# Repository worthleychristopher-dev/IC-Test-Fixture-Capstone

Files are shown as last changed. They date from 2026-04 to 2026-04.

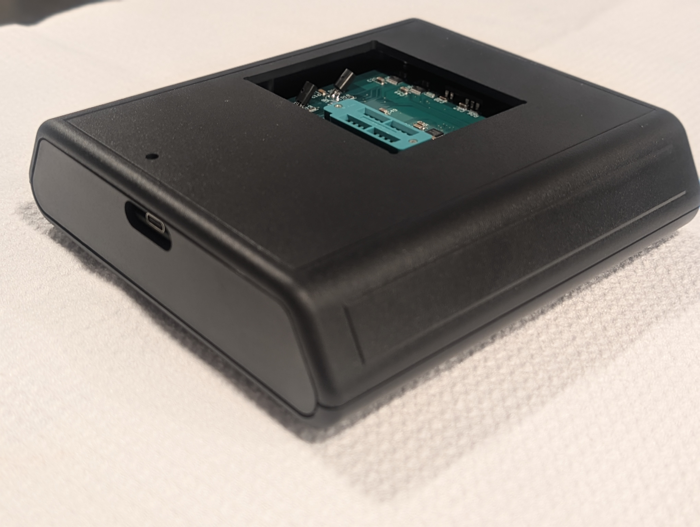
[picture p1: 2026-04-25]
docs/images/hardware_images/chassis_2.jpg

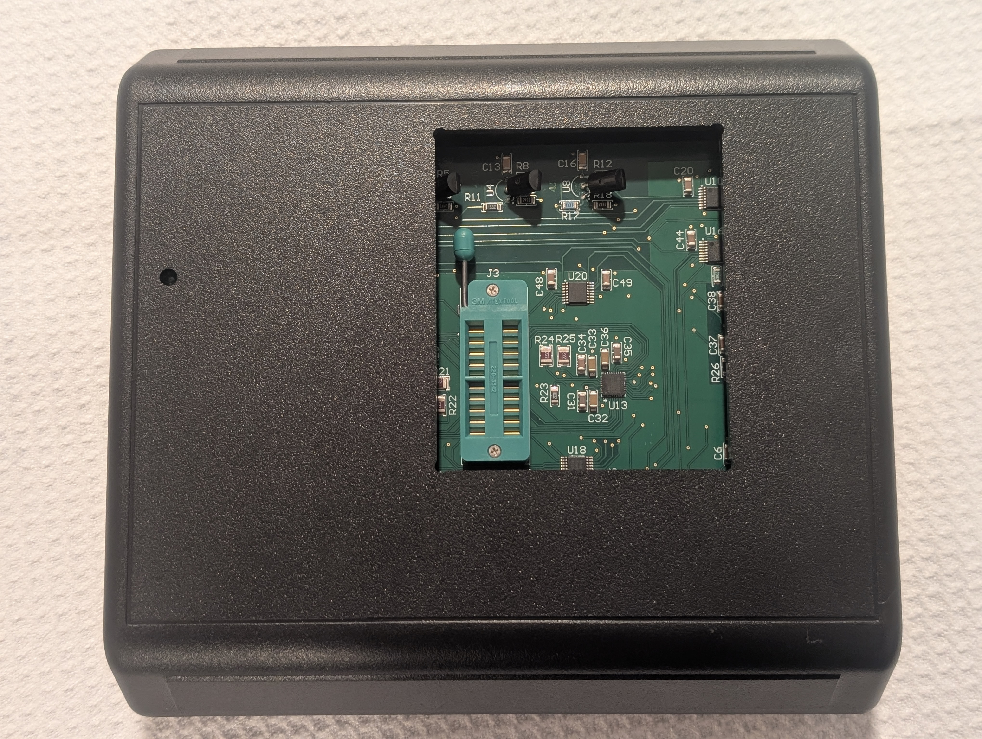
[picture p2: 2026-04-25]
docs/images/hardware_images/chassis_1.jpg

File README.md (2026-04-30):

# Reconfigurable Digital Integrated Circuit Test Fixture

A flexible test setup designed to quickly verify the functionality of various digital integrated circuits, ranging from simple logic gates to timing-dependent shift registers. It supplies standard logic-level voltages and measures output voltages to ensure they are within specification. A PC application enables users to control the system and execute test scripts. Test results are stored and exported as a PDF report describing the outcome of each test.

## Project Background

The core challenge lies in testing and servicing digital integrated circuit (IC) assemblies used in NUWC Division Newport’s ship test equipment. The large number of ICs in these systems makes troubleshooting and verification time-consuming, impacting operational efficiency, system reliability, and maintenance costs.

Since these assemblies are expected to remain functionally reliable for 25–30 years, diagnosing failures without efficient tools increases labor time, risks using faulty components, and threatens overall system readiness.

### Proposed Solution

To address this, our project proposes a **Reconfigurable Digital Integrated Circuit Test Fixture** that enables NUWC technicians to quickly verify IC functionality and assist in debugging failed circuit assemblies.

### System Components

- **Hardware Fixture**  
  Adapts to various IC packages and pinouts, applies logic-level signals, and measures outputs via analog-to-digital converters.

- **Software Interface**  
  Communicates with the hardware over USB, runs user-defined test scripts, and automatically generates detailed PDF reports.

### Key Benefits

- **Improved Maintenance Efficiency**  
  Reduces time spent on board-level diagnostics and repairs.

- **Inventory Verification**  
  Confirms IC functionality before installation.

- **Cost and Labor Savings**  
  Minimizes dependence on expensive test equipment and manual checks.

## Prerequisites

### Hardware

Altium Designer or KiCad (may need to manually fix PCB layers)

SolidWorks

CP2102 USB to UART Driver (https://www.silabs.com/software-and-tools/usb-to-uart-bridge-vcp-drivers)

AN721: CP210x/CP211x Device Customization Guide (https://www.silabs.com/interface/usb-bridges/classic/device.cp2102?tab=softwareandtools)

USB-C 2.0 Cable

### Software

Requires Python >= 3.10

Third Party Libraries used in this project are:

  - PySide6
  - PyYAML
  - ReportLab

See software/pyproject.toml for compatible versions.

### Firmware

STM32CubeIDE

ST-Link debugger/programmer

## Installation

```sh
git clone https://github.com/worthleychristopher-dev/IC-Test-Fixture-Capstone
```

Follow the steps below in order to complete the full system setup.

### 1. PCB Fabrication and Assembly

Fabricate and assemble the PCB before proceeding with any software setup.

- Gerber and ODB++ files are located in: hardware/altium_files/
- Bill of Materials (BOM) is located in: docs/

Send these files to your PCB manufacturer and complete assembly.

---

### 2. Install Required Drivers

Install all required hardware drivers before connecting the device.

- Refer to the **Hardware** section of this README for the full list of required drivers
- Ensure STM32 and any peripheral device drivers are properly installed

---

### 3. Firmware Installation (STM32)

Build and flash the firmware to the STM32 microcontroller.

- Navigate to: firmware/README.md
- Follow the instructions under:
  - Building the Firmware
  - Flashing the Firmware

Verify successful flashing before proceeding.

---

### 4. Software Installation (Python Application)

Build and install the Python application.

- Navigate to: software/README.md
- Follow the instructions under:
  - Installation
  - Usage

## Usage

1. Connect test fixture to PC using USB-C 2.0 cable
2. Open ICTestFixture.exe
3. Go to File -> Open and open a test script
4. Insert the IC into the socket.
5. Run -> Run to execute the test script
6. Save PDF report, refer to User Manual for interpretation

## Test Scripts

The test fixture was tested with select 7400-series ICs manufactured by Texas Instruments. These chips range from simple logic gates, to edge dependent shift-registers. Refer to the table below for exact chips tested. 

Test scripts are written using YAML syntax, refer to docs/YAML Test Script Documentation for expected syntax of the application. All used test scripts and their results are located in test_scripts/ and test_results/ respectively.

| IC | Logic |
| -- | ----- |
| 74(HC/HCT)00 | NAND |
| 74(HC/HCT)02 | NOR |
| 74(HC/HCT)04 | Inverter |
| 74(HC/HCT)08 | AND |
| 74(HC/HCT)32 | OR |
| 74(HC/HCT)73 | J-K FF -edge |
| 74(HC/HCT)74 | D FF +edge |
| 74(HC/HCT)138 | 3:8 Demux |
| 74(HC/HCT)153 | 4:1 Mux |
| 74(HC/HCT)165 | 8-bit shift register |
| 74(HC/HCT)244 | Tri-state buffer |
| 74(HC/HCT)245 | 8-bit transceiver |
| 74(HC/HCT)283 | 4-bit full adder |
| 74(HC/HCT)374 | Tri-state D FF +edge |
| 74(HC/HCT)688 | 8-bit comparator |

All chips were able to pass. For ICs 245, 283, and 688, shorter test scripts were used as running an exhaustive test will take hours to complete. The shorter test scripts for these ICs checked that all inputs and output pins were able to operate with a HIGH or LOW signal. See test_results/ for all generated PDF reports.

74HC74 and 74HCT73 had their 2nd flip-flops fail (right side), but their respective variants were able to pass.Rotating the ICs 180 degrees (reverse test scripts), the 2nd flip-flops were able to pass, but the 1st flip-flop failed. It is theorized the right side of the PCB is signifcantly noisier causing the chips to unexpectedly fail.

## Documentation

All documentation can be found in the directory docs. The directory includes PDF files of user manuals
and technical documentation. Additionally, /docs/editable/ includes a DOCX variant to allow
additions to the documentation as this project is expanded on. README markdown file are included with most parts
of the project to assist in navigation and summarize their purpose.

The User Manual for this system is located in docs/User Manual

## License

The Reconfigurable Integrated Test Fixture project contains multiple components with different licenses:

- **Hardware (Altium, SolidWorks)**: CERN-OHL-P-2.0 (see /hardware/LICENSE)
- **Software (Python)**: MIT License (see /software/LICENSE)
- **Firmware (STM32)**: MIT License (see /firmware/LICENSE)

Refer to each subdirectory for full details regarding license of each component.

## Project Structure

```
IC-Test-Fixture-Capstone/
├── README.md               # project overview, and instructions
├── LICENSE                 # top-level license
├── docs/                   # images, user manual, and technical documentation
├── hardware/               # altium source files and chassis files
├── software/               # Python application
├── firmware/               # firmware for STM32C071RB
├── test_scripts/           # HC/HCT test scripts for select 7400-series ICs
└── test_results/           # generated PDF reports from testing on 7400-series ICs
```

## UML Capstone Team 2025 - 2026

Qingping Diep (EE/CS) - [LinkedIn](https://www.linkedin.com/in/qdiep/)

Chris Worthley (CE) - [LinkedIn](https://www.linkedin.com/in/christopher-worthley-98b83a29a/)

Theodore Skafidas (EE) - [LinkedIn](https://www.linkedin.com/in/theodore-skafidas/)

Will Mensah (EE) - [LinkedIn](https://www.linkedin.com/in/will-s-mensah/)

Zacharie Fluet (EE) - [LinkedIn](https://www.linkedin.com/in/zacharie-fluet-6625728b/)

## Acknowledgements

### Advisors

Zachary Murtishi (NUWC)

Paul Robinette (Dept. of Electrical and Computer Engineering UML) - [LinkedIn](https://www.linkedin.com/in/paul-robinette-24857b/)

### UConn Capstone Team 2024 - 2025

Steven Chen (CSE) - [LinkedIn](https://www.linkedin.com/in/steven848/)

William Dunnett (CSE) - [LinkedIn](https://www.linkedin.com/in/william-dunnett-61431b260/)

Joshua Bardinelli (CSE) - [LinkedIn](https://www.linkedin.com/in/joshua-bardinelli/)

Sarah Millien (CSE) - [LinkedIn](https://www.linkedin.com/in/sarah-millien/)

Brennen Ravenberg (CSE)

Gabriel Zambrano (ECE) - [LinkedIn](https://www.linkedin.com/in/gabrielzambrano1111/)

Quincy Tejada (ECE)

Amir Herzberg (Dept. of Computer Science and Engineering UConn)

This project was sponsored by Naval Undersea Warfare Center Division Newport.

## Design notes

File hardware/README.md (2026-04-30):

# Reconfigurable Digital Integrated Circuit Test Fixture - Hardware

The hardware encompasses circuit simulations, schematics, chassis and any other physical component of the **Reconfigurable Digital Integerated Circuit Test Fixture**. The design emphasizes reconfigurability, measurement accuracy, and system protection, enabling reliable testing of digital ICs across a range of operating conditions.

## Overview

The hardware utilizes a USB-C interface for power and communication. The power and data lines are isolated, reducing the noise of the system and protecting the host PC from potential electrical faults. The test fixture accomodates common logic voltage levels from 1.8V to 5V.

Input signal routing is handled using a pair of analog switch arrays, allowing flexible operation of input voltages to pins of the device under test. For measuring output pins, the output signal path is multiplexed and fed first into a high-impedance (Hi-Z) detection circuit, and then into a high-resolution ADC system.

## Core Components

Control of the circuit is handled by the STM32C071RB microcontroller from STMicroelectronics. Communication with the host PC is achieved through a CP2102 USB-to-UART bridge. To ensure signal integrity and safety, USB data lines are isolated using the ADuM4160, while power isolation is provided by the UCC33420 module.

Logic-level voltage references are generated using TLV431 shunt regulators in combination with high-precision resistors, ensuring stable and accurate voltage levels.

Dynamic analog signal routing is implemented using the ADG2128 switch array and ADG708 multiplexers. Output voltages are measured by the NAU7802 ADC, providing high-resolution data.

## Validation

The hardware was validated through a series of test, ensuring analog components performed with high-precison and stability. The power rails and TLV431 circuits were verified for correctness. Signal routing was tested for all ppossible combinations. The ADC performance was evaluated to confirm accuracy of responses and compatability with 1.8 to 5V signals.

All system components performed within expected specifications.

## Chassis

All files included are of the SolidWorks CAD of the IC test fixture chassis design.

This includes raw pre-fab chassis consisting of a top, front, rear, and bottom chassis, modified chassis with cutouts for the PCB on the top, front, and bottom chassis, and the CAD files for hardware used to fully assemble the IC test fixture, including screws, standoffs, and rubber feet.

Drawings are present showing each chassis parts individually, along with their measurements and cutouts. The Chassis is made of ABS plastic.

The pre-fabricated chassis is a JB-65 Desktop Electronics Enclosure, by Polycase and can be orderd from https://www.polycase.com/jb-65

Physical assembly of the chassis can be done with the chassis screws provided with the chassis by Polycase, 8x #4-40 Pan screws, 4x #4-40 1" hex standoffs, and 4x 0.5" cylindrical bumper rubber feet along with the IC test fixture PCB.

## Spice Simulations

Voltage reference (VREF) circuits consist of a TLV431 shunt regulator component with a $1.24\ V$ reference voltage, a voltage divider resistor circuit to set the VREF voltage, and a current limiting resistor to restrict the amount of current that can flow through the circuit.

For all VREF circuits within the IC test fixture, $V_{in} = 5\ V$, $V_{ref} = 1.24\ V$.

The formula for all the VREF circuits is:

$$V_{out} = V_{ref} \left(1 + \frac{R_1}{R_2}\right)$$

where $R_2 = 2490\ \Omega$ for consistency.

$V_{out}$ is set to $1.8\ V$, $2.5\ V$, $3.3\ V$, $4.0\ V$, or $4.5\ V$ for the VREF circuit, which is used to find each circuit's $R_1$ value, which is then chosen from the closest available 0.1% tolerance value.

The current limiting resistor ($R_3$) is equal to: 
$$R_3 = \frac{\left(V_{in} - V_{out}\right)}{\left(I_{out} + I_{cathode}\right)}$$

### TLV431 Simulation Results

| Target Voltage | Simulated Voltage |
| --- | --- |
| 1.8 V | 1.803 V |
| 2.5 V | 2.509 V |
| 3.3 V | 3.314 V |
| 4.0 V | 4.001 V |
| 4.5 V | 4.506 V |

5V is not present as the USB interface outputs at max 5V. Instead, the 5V is provided by the isolated 5V rail from UCC33420.

## Documentation

Refer to Hardware Documentation in docs/. The documentation details the system architecture, circuit design, component selection, and PCB implementation used to support flexible, multi-voltage logic testing.

The hardware documentation includes:

| Section | Description |
| --- | --- |
| System Overview | High-level description of functionality and purpose |
| System Architecture | Block-level breakdown of subsystems |
| Design Decisions | Justification of key engineering choices |
| Signal Flow | End-to-end operation from input to measurement |
| Circuit Descriptions | Detailed explanation of each schematic block |
| PCB Layout | Board design, routing, and layer stack considerations |
| Electrical Specifications | Voltage ranges, thresholds, and performance |
| Interfaces | USB, UART, I²C, and ZIF socket definitions |
| Testing & Validation | Verification of system functionality |
| Safety & Protection | ESD, isolation, and overcurrent protection |

Refer to Reconfigurable Test Fixture BOM in docs/. The file includes the name of the part, part number, manufacturer number, designator, and quantity.

Errors were identified in the PCB layout, refer to docs/eco for all Engineering Change Orders implemented.

## License

The hardware portion of the **Reconfigurable Digital Integrated Circuit Test Fixture** is under a CERN-OHL-P-2.0 license.

## Package Structure

```
hardware/
├── README.md               # project overview, and instructions
├── LICENSE                 # license for hardware source files
├── altium_files/
│   ├── Source/  
│   │   ├── Schematics/     # altium schematics
│   │   └── PCB/            # altium PCB
│   ├── Outputs/            # generated altium output files
│   ├── Draftsman/          # assembly and fabrication drawings
│   └── Releases/           # gerber file used for fabrication
├── chassis/                # SolidWorks design files
└── vref__circuits/         # LTSpice simulation for TLV431 shunt regulator
```

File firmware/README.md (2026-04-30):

# Reconfigurable Integrated Circuit Test Fixture – Firmware

This firmware drives the **Reconfigurable Digital Integrated Circuit Test Fixture**, enabling configurable testing of common digital ICs through a command-based interface.

## Overview

The system is designed to operate in two primary modes:
- **GUI-controlled operation** (normal use case)
- **Standalone command-driven operation** (development, debugging, automation)

The firmware runs on an STM32 microcontroller and interfaces with:
- Analog switch matrices (2x ADG2128)
- Analog multiplexers (4x ADG708, 1x ADG709)
- Voltage rail selection circuitry
- GPIO-based digital I/O
- ADC (NAU7802) for measurement
- UART interface for command communication

## Firmware Architecture

### Core Responsibilities
- Parse and execute incoming commands (SCPI-style)
- Configure routing through analog switch arrays
- Apply voltage rails to DUT pins
- Drive digital inputs and read outputs
- Execute test sequences
- Return structured responses over UART

### Key Modules
- `main.c`  
  Handles system initialization (HAL, peripherals), UART communication, and command dispatch
  Parses incoming ASCII commands and routes them to execution handlers

- `test_utils.c`  
  Contains core test execution logic and validation
  Contains functions for switch array routing

- `nau7802.c`
  Handles ADC reads, calibration, and measurement routines

- `mux_utils.c`  
  Controls analog switch matrices (ADG2128) and pin routing

- `bist.c`   
  Code for executing a built-in self test for the fixture

- `fault_handling.c`
  Functions and subroutines for hardware fault handling

- `adg2128_router.c` *functions not used*
  Contains legacy functions for routing the switch arrays
  Functions improved upon and implemented in test_utils.c. 
  Header file includes variable definitions that ARE used

- `firmware_crc.c`
  Contains functions for running the firmware checksum

## Command Interface

The firmware uses a text-based command protocol.

### Format
```
CMD:arg1,arg2,arg3
```

### Example
```
PRM:20,7,5
VIN:0.33,3.84
INS:1,2,3
OUT:4,5
VIP:0b0101,0b1010
TEST
```

### Full Command Reference
See:
```
/docs/STM32 Command Programming Guide.txt
```

This file contains:
- All supported commands
- Argument formats
- Command use cases

## Development Setup

### Requirements
- STM32CubeIDE
- ST-Link debugger/programmer
- USB connection to STM32 board
- (Optional) Python (for executor script)

## Building the Firmware

1. Open STM32CubeIDE
2. Go to:
   ```
   File → Open Projects from File System
   ```
3. Import the firmware project folder
4. Build the project:
   ```
   Project → Build Project
   ```

## Flashing the Firmware (ST-Link)

1. Connect ST-Link to the board
2. Power the board via USB
3. In STM32CubeIDE:
   ```
   Run → Debug (or Run)
   ```
4. The firmware will compile (if needed) and flash automatically

## UART Communication

Typical UART settings:
- Baud Rate: 115200
- Data Bits: 8
- Stop Bits: 1
- Parity: None

## Using the System with the GUI

### Steps
1. Plug in the fixture via USB
2. Ensure firmware is running on the STM32
3. Open the GUI application
4. The GUI will automatically connect 
5. System now ready to run test scripts from the GUI application

### Notes
- No manual setup is required if firmware is running
- GUI handles all command formatting and communication

## Standalone Usage (Without GUI)

### Option 1: Serial Terminal

You can manually send commands using a serial terminal.

#### Recommended Tools
- STM32CubeIDE Serial Terminal
- Terminal or Windows Powershell

#### Steps
1. Open a serial terminal
2. Set directory to the one that includes stm32_terminal.py
   ex. 'cd C:\IC-Test-Fixture-Capstone\firmware\utils'
3. Run the python file, 'python stm32_terminal.py'
4. Send commands manually:
   ```
   PRM:20,7,5
   TEST
   ```

#### Example Output
```
OK PRM
OK TEST
RESULT: PASS
```

---

### Option 2: Script Execution (executor.py)

The `executor.py` script allows automated execution of command sequences.

#### Usage
```
python executor.py 
```

#### Example `script.txt`
```
PRM:20,7,5
VIN:0.33,3.84
INS:1,2,3
OUT:4
VIP:0b0101
TEST
```

#### Features
- Sequential command execution
- Response logging
- Useful for automated testing and debugging

## Typical Workflow

### Development Workflow
1. Modify firmware source code
2. Build in STM32CubeIDE
3. Flash using ST-Link
4. Test using terminal or executor.py

### Normal Operation
1. Power on fixture
2. Open GUI
3. Run test scripts

## Error Handling

Common responses:
- `OK <CMD>` → Command executed successfully
- `ERR <reason>` → Command failed

### Examples
```
ERR no_colon
ERR invalid_args
```

## Troubleshooting

### No UART Output
- Check COM port selection
- Verify baud rate
- Ensure firmware is running

### Flashing Issues
- Verify ST-Link connection
- Confirm correct target device in CubeIDE
- Power cycle the board

### Command Errors
- Ensure correct format (`CMD:args`)
- Refer to Command Programming Guide

## Future Improvements
- Expanded command set
- Improved error reporting
- Multi-fixture GUI support
- Enhanced logging and diagnostics

## Notes
- Designed for production-like testing environments
- Emphasizes modularity and scalability
- Command-based interface enables easy automation

## License

The firmware portion of the **Reconfigurable Digital Integrated Circuit Test Fixture** is under a MIT license. The firmware contains third-party software provided by STMicroelectronic and are subject to their own licenses and agreement policies. See firmware/LICENSE, and firmware/THIRD_PARTY_NOTICES for full details.

## Package Structure

firmware/
├── README.md               # project overview, and instructions
├── LICENSE                 # license for firmware source files
├── THIRD PARTY NOTICES     # license for third-party libraries used
├── STM32_main/
│   ├── Core/  
│   │   ├── Src/            # C source files
│   │   └── Inc/            # C header files
│   ├── Drivers/            # STMicroelectronic drivers
│   ├── .cproject           # compiler settings
│   ├── .mxproject          # CubeMX project wrapper
│   ├── .project            # STM32CubdeIDE project file
│   └── STM32_main.ioc      # STM32 configurations
└── utils/                  # utility Python scripts to run firmware
```

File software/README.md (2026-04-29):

# Reconfigurable Digital Integrated Circuit Test Fixture - Software

A standalone GUI application for controlling the **Reconfigurable Digital Integrated Circuit Test Fixture**. 
Users can write or upload YAML-based test scripts to execute tests, with results exported as PDF files.

Requires Python >= 3.10

Recommended Python >= 3.14.3 (latest as of April 2026)

## Installation

Create virtual Python environment
```sh
cd software/

python -m venv .venv

# linux/mac
source .venv/bin/activate

# windows
.venv\scripts\Activate.ps1
```

To install project dependencies
```sh
# run in same directory as pyproject.toml

# only required dependencies
pip install -e .

# install with additional optional dev dependencies
pip install -e .[dev]
```

## Usage

### Developing in IDE
```sh
# run directly from src
python src/ic_test_fixture/main.py

# or if installed in editable mode
python -m ic_test_fixture.main
```

### Compiling Executable

To compile an executable
```sh
# linux/mac
bash ./scripts/build.sh

# winodws (PowerShell)
powershell -ExecutionPolicy Bypass -File .\scripts\build.ps1
```

## GUI Usage

### From Existing Test Script
    1. Go to **File -> Open File** (Ctrl+O)
    2. Verify test script is correct
    3. Press **Run -> Run** (F5)
    4. Save results to desired location as PDF file
    
### Create a New Test Script

1. Go to **File → New File** (Ctrl+N)
2. Choose one of the following:
   - **Text Editor** (manual script creation)
   - **Test Script Wizard** (guided setup)

---

Refer to User Guide in docs/ for full usage

#### Option A: Text Editor
3. Write your test script manually  
4. Save the test script as a YAML file  

---

#### Option B: Test Script Wizard
3. Select the desired optional sections  
4. Use the dropdown menus to configure parameters  
5. Save the test script as a YAML file  

## Running Tests

```sh
# to run all unit tests
pytest tests/

# :: operator can be used to run specific tests
pytest tests/test_parser.py::TestParserHelpers
```

## Troubleshooting

### Unable to Communicate with STM32

Reset the circuit by unplugging and replugging the USB-C cable. Firmware must have the response "OK PING".

### Software Checksum failed

Verify the ICTestFixture.exe file has not been tampered with. Last 32 bytes should match the SHA-256 of the executable excluding the last 32 bytes of data.

### Checksum failed

Verify CP2102 driver has been installed and serial number has been reprogrammed. See the repository's main README.md for the associated download links.

Verify the test fixture is connected via USB-C 2.0.

Ensure firmware has not been tampered with. If developing, change EXPECTED_CHECKSUM in device/serial_manager.py::CheckSum to the the new expected checksum. 

## Documentation

See docs/ for all documentation

Python Technical Documentation - explaination of source code, architecture, and data structures

YAML Test Script Documentation - expected syntax of test scripts

## License

The software portion of the **Reconfigurable Digital Integrated Circuit Test Fixture** is under a MIT license. The software contains third-party packages that are subject to their own licenses provided by their authors. See software/LICENSE, and software/THIRD_PARTY_NOTICES for full details.

## Package Structure

```
software/
├── README.md               # project overview, and instructions
├── LICENSE                 # license for Python source code
├── THIRD PARTY NOTICES     # licenses for Python packages used
├── pyproject.toml          # package metadata and dependencies
├── scripts/
│   ├── append_checksum.py  # appends checksum to executable
│   ├── build.ps1           # Windows Powershell build script
│   └── build.sh            # Mac/Linux build script
├── src/
│   └── ic_test_fixture/
│       ├── device/         # device-related modules
│       ├── file_io/        # file parsing, and exporting data
│       ├── gui/            # graphical user interface code
│       ├── utils/          # misc. code / helper tools
│       ├── __init__.py
│       └── main.py         # application entry point
└── tests/
    ├── unittest_yaml/      # YAML-based test scripts for unit tests
    ├── test_parser.py      # tests for parser module
    └── test_test_vector.py # tests for test_vector module
```

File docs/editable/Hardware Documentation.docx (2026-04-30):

Reconfigurable Test Fixture for Digital Integrated Circuits

Hardware Design Documentation

ABSTRACT

This report presents the design and implementation of a reconfigurable test fixture for evaluating 7400-series digital integrated circuits (ICs). The system enables dynamic signal routing, multi-voltage logic testing, and automated data acquisition through a USB-connected microcontroller platform. Key features include electrical isolation, programmable voltage references, multiplexed signal routing, and high-resolution analog-to-digital conversion. The design ensures accurate, flexible, and safe testing of digital ICs across a range of operating conditions.

I. INTRODUCTION

The increasing diversity of digital logic devices necessitates flexible testing platforms capable of supporting multiple voltage levels and configurations. Traditional fixed test setups lack adaptability and require significant manual intervention. This work presents a reconfigurable hardware system that enables testing of a varied number of digital ICs.

II. SYSTEM OVERVIEW:

The reconfigurable test fixture for digital integrated circuits is designed to evaluate and characterize 7400-series logic ICs across a range of operating voltage levels. The system provides a flexible platform that allows users to dynamically configure input signals, apply selectable voltage levels, and measure output responses through a software-controlled interface.

The fixture connects to a host computer via USB, enabling both power delivery and communication. An onboard microcontroller coordinates signal routing, voltage selection, and data acquisition while interfacing with external components such as analog switch arrays, multiplexers, and an analog-to-digital converter (ADC). The system supports multiple logic voltage levels (1.8V to 5V), allowing compatibility with a wide variety of digital devices.

By integrating electrical isolation, programmable signal routing, and high-impedance measurement capability, the design ensures safe operation, minimizes noise interference, and provides accurate testing results. This makes the system suitable for both educational use and practical validation of digital IC functionality.

III. SYSTEM ARCHITECTURE:

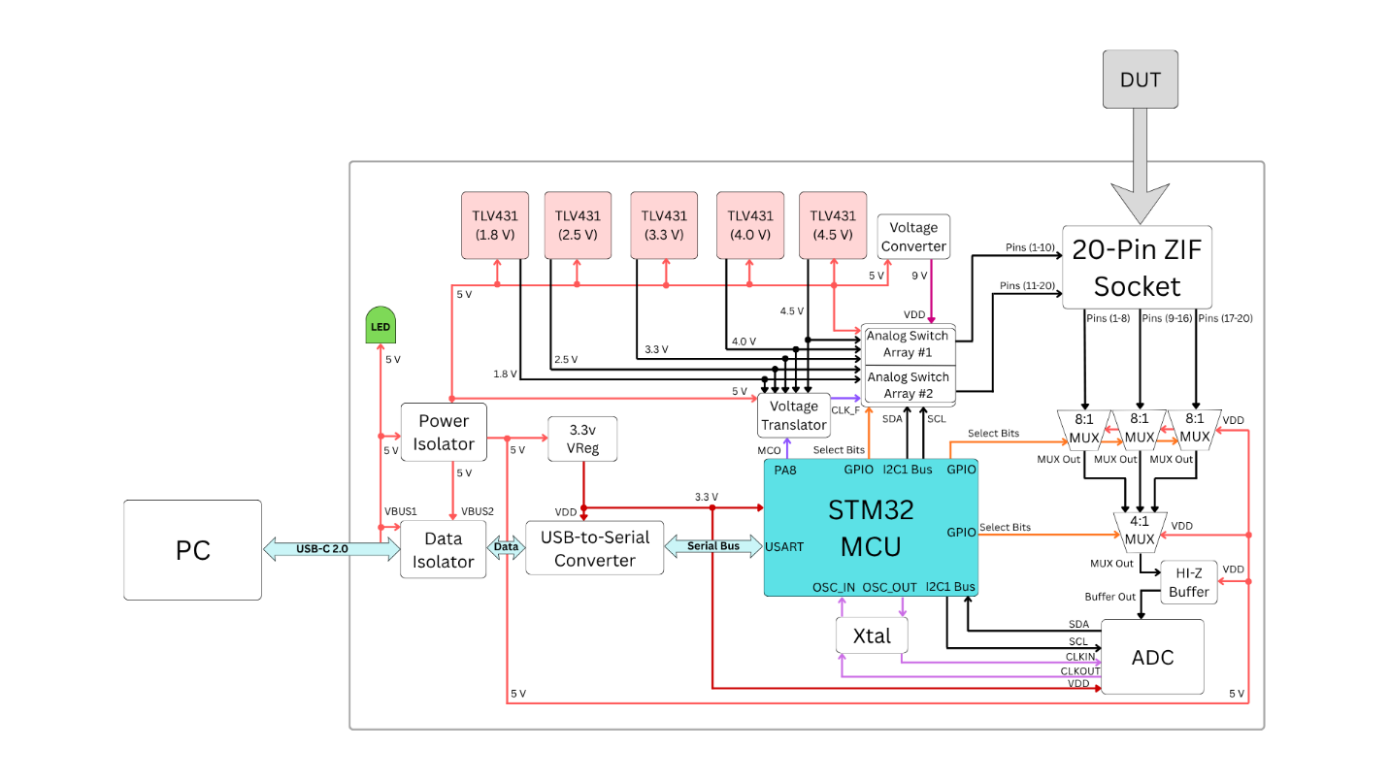
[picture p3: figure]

Fig. 1. Block Diagram of the Reconfigurable Test Fixture

In Figure 1 above, the IC test fixture connects to a user-end PC through a USB-C 2.0 connection, which provides 5 V and data for both power and communication. The 5 V from USB connects to a power indicator LED and, along with the data lines, is routed to individual isolators for protection. The isolated data then connects to a USB-to-Serial converter before interfacing with the STM32 microcontroller. The isolated 5 V rail powers multiple components, including a 3.3 V voltage regulator, buffer op-amp, 8:1 and 4:1 multiplexers, a voltage translator, and a voltage converter, as well as multiple voltage reference circuits (1.8 V, 2.5 V, 3.3 V, 4.0 V, and 4.5 V) made up of TLV431. TLV431 are shunt regulators and used to maintain a stable voltage signal by using voltage dividing resistors. The 3.3 V regulator supplies power to the USB-to-Serial converter, STM32 microcontroller, and the analog-to-digital converter. The voltage converter generates 9 V to power the analog switch arrays, which provide routing to all 20 pins of the zero-insertion force (ZIF) socket to accommodate the input pin requirements of a valid 7400 series IC for testing. The 20-pin ZIF socket provides connection access for these ICs, supporting a maximum of 20 pins. A cascade of three 8:1 multiplexers provides routing to all 20 pins of the ZIF socket to accommodate output pins of the IC under test and funnels them into a 4:1 multiplexer. The 4:1 multiplexer sends the selected signal through a buffer op-amp to allow for high-impedance (Hi-Z) testing, after which the buffer op-amp drives the signal into the analog-to-digital converter for conversion. The analog-to-digital converter then sends the digitized signal to the STM32 microcontroller for analysis. The STM32 processes the received data and transmits the results back to the user-end PC. Additionally, the STM32 controls multiple components through select bits, including the analog switch arrays and both the 8:1 and 4:1 multiplexers, to determine signal pathing during testing. A voltage translator is used to match voltage levels for clock rise and fall signals required by certain ICs, and an external crystal (Xtal) provides a higher frequency (24 MHz) and improved accuracy for both the STM32 and the analog-to-digital converter.

IV. REQUIREMENTS AND SPECIFICATIONS

A. Functional Requirements

- Support up to 20-pin 7400-series ICs
- Provide configurable voltage levels (1.8V–5V)
- Enable dynamic signal routing
- Measure and report logic states

B. Electrical Specifications

- Input Voltage: 5V (USB)
- ADC Resolution: 24-bit
- Logic Levels: 1.8V–5V

V. DESIGN DECISIONS

The purpose of this test fixture is to provide a flexible and safe platform capable of testing a wide range of logic voltage levels for 7400-series integrated circuits. Several key design decisions were made to achieve this functionality:

USB-Based Power and Communication

USB-C was selected as the primary interface due to its widespread availability and ability to provide both power and data through a single connection. Operating in USB 2.0 mode simplifies implementation while still meeting system bandwidth requirements.

Electrical Isolation

Isolation was implemented using the ADuM4160 and UCC33420 to protect the host computer and eliminate ground loops. This improves measurement accuracy and prevents noise from propagating between the host and the test circuitry.

Microcontroller Selection (STM32)

The STM32 microcontroller was chosen for its balance of processing capability, peripheral support, and ease of integration. It provides sufficient GPIO, I²C, and UART interfaces to control multiplexers, switch arrays, and communication modules while maintaining low power consumption.

External ADC Usage

An external ADC (NAU7802) was used instead of the internal STM32 ADC to achieve higher resolution and improved measurement accuracy. This is particularly important when detecting small voltage differences and high-impedance states.

Multiplexing and Switching Architecture

Instead of dedicating a measurement channel to each pin, multiplexers (8:1 and 4:1) and an analog switch array (ADG2128) were used to reduce hardware complexity while maintaining flexibility. This allows a single ADC channel to measure multiple signals efficiently.

Multi-Voltage Support

Multiple voltage references (1.8V to 5V) were implemented using TLV431 shunt regulators. This enables the system to test ICs operating at different logic levels and ensures stable and accurate voltage generation.

High-Impedance Measurement Capability

A buffer op-amp stage was included before the ADC to allow high-impedance (Hi-Z) measurements. This prevents loading effects and ensures accurate detection of open or disconnected signals.

Dedicated Power Domains

Separate isolated and non-isolated domains were used to improve signal integrity and system reliability. Sensitive analog and measurement circuits operate in the isolated domain to minimize noise.

VI. SIGNAL FLOW DESCRIPTION

The system operates through a coordinated signal flow controlled by the STM32 microcontroller:

1. A command is sent from the user’s PC to the system via the USB interface.
2. The USB-to-UART bridge (CP2102) converts the incoming USB data into serial communication for the STM32.
3. The STM32 processes the command and configures the analog switch array and multiplexers to establish the desired signal path.
4. Selected voltage levels are applied to the input pins of the device under test (DUT) through the switch matrix.
5. Output signals from the DUT are routed through a cascade of multiplexers (8:1 followed by 4:1).
6. The selected signal passes through a high-impedance buffer stage to prevent loading.
7. The buffered signal is sent to the ADC, where it is converted into digital data.
8. The STM32 reads the ADC data via I²C, processes the results, and determines the logic state or measurement outcome.
9. The processed data is transmitted back to the PC for display and analysis.

This structured signal flow enables flexible, automated, and accurate testing of digital ICs.

VII. KEY COMPONENT SUMMARY TABLE

Component | Part Number | Function
Microcontroller | STM32 | Controls system operation and data processing
USB-to-UART Bridge | CP2102 | Enables communication between PC and MCU
USB Isolator | ADuM4160 | Provides data isolation between host and system
Power Isolator | UCC33420 | Generates isolated 5V supply
ADC | NAU7802 | Converts analog signals to digital data
Analog Switch Array | ADG2128 | Routes signals dynamically
Multiplexer (8:1) | ADG708 | Selects one of multiple input signals
Multiplexer (4:1) | ADG708 | Final signal selection stage
Voltage Reference | TLV431 | Generates stable reference voltages
Voltage Regulator | LDO (3.3V) | Supplies regulated power to digital components

VIII. SCHEMATICS

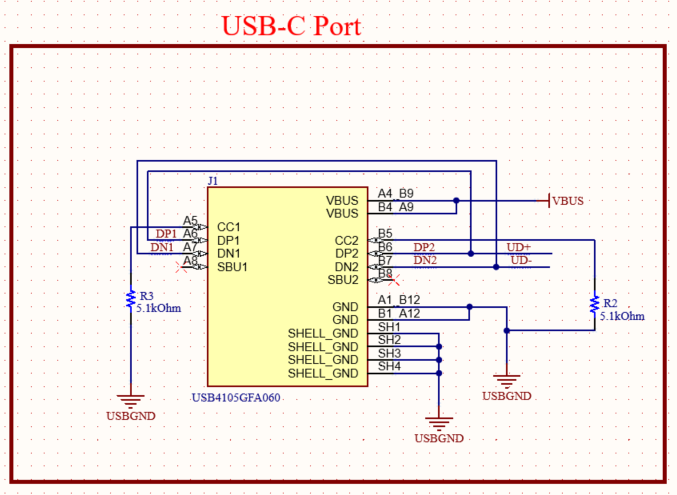
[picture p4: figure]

Figure 2. USB-C Port Schematic.

A USB-C connector is configured to operate in USB 2.0 mode, providing both power and data communication between the user and the board. The differential data lines (D+ and D−) are formed by tying DP1 with DP2 and DN1 with DN2, ensuring proper operation regardless of cable orientation.

The CC1 and CC2 pins are connected to 5.1 kΩ pull-down resistors, indicating that the device operates as a USB sink. This configuration allows the host to detect the connection and supply 5V (VBUS) power while enabling data communication.

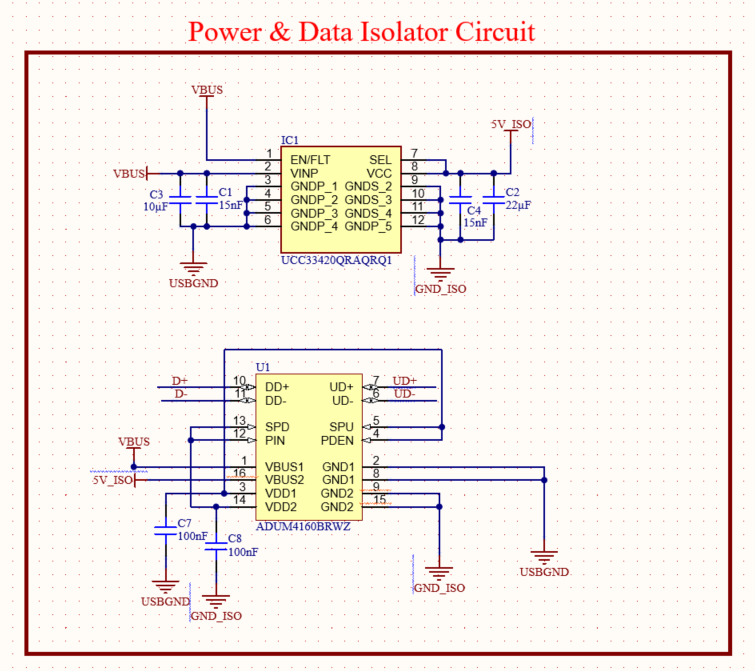
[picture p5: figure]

Figure 3. Power and Data Isolator Circuit

This circuit implements full USB isolation by separating both power and data between the host (computer) and the system. The top portion of the schematic uses the UCC33420 to convert the incoming USB VBUS (5V) into an isolated 5V supply (5V_ISO), effectively separating the host ground (USBGND) from the system ground (GND_ISO). This ensures that the board operates on a clean, isolated power domain, reducing noise and preventing ground loops. The bottom portion of the circuit uses the ADuM4160 USB isolator to transfer the differential data signals (D+ and D−) across the isolation barrier. On the host side, the data lines are received and magnetically coupled across the isolator, then reconstructed on the device side as DATA_P and DATA_N. Together, these components create two independent domains, host and system, allowing safe and reliable communication while protecting sensitive circuitry and improving measurement accuracy by minimizing noise interference.

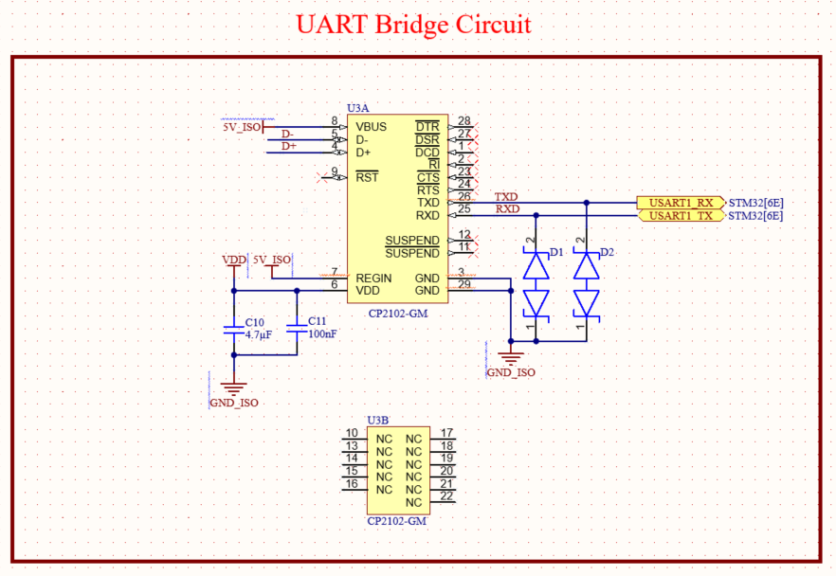
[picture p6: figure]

Figure 4. USB-to UART Bridge

This circuit implements a USB-to-UART communication bridge using the CP2102, enabling communication between the host computer and the microcontroller. The differential USB data lines (D+ and D−), labeled as DATA_P and DATA_N, enter from the isolated USB domain (5V_ISO and GND_ISO) and connect to the CP2102, which converts USB signals into UART signals. The device is powered using the isolated 5V supply, with local decoupling capacitors (4.7 µF and 100 nF) ensuring stable operation. On the output side, the CP2102 provides TXD and RXD signals, which are routed to the microcontroller’s UART interface (USART1 TX/RX). ESD protection diodes are placed on the UART lines to protect against voltage spikes and improve system robustness. Overall, this circuit enables reliable, isolated serial communication between the USB host and the onboard microcontroller while maintaining signal integrity and protection.

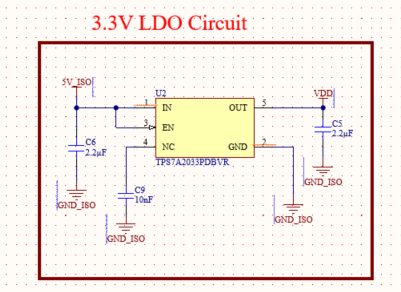
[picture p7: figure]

Figure 5. 3.3V LDO Circuit.

This circuit implements a 3.3V low-dropout (LDO) regulator to generate a stable supply voltage for low-power components on the board. The regulator takes the isolated 5V supply (5V_ISO) as its input and steps it down to a regulated 3.3V output (VDD). Input and output capacitors (2.2 µF) are used to stabilize the voltage and reduce noise, while an additional 10 nF capacitor on the enable pin helps filter any unwanted transients. The entire circuit is referenced to the isolated ground (GND_ISO), maintaining consistency with the system’s isolated power domain. This ensures a clean and reliable 3.3V rail for sensitive digital and analog components, contributing to overall system stability and performance.

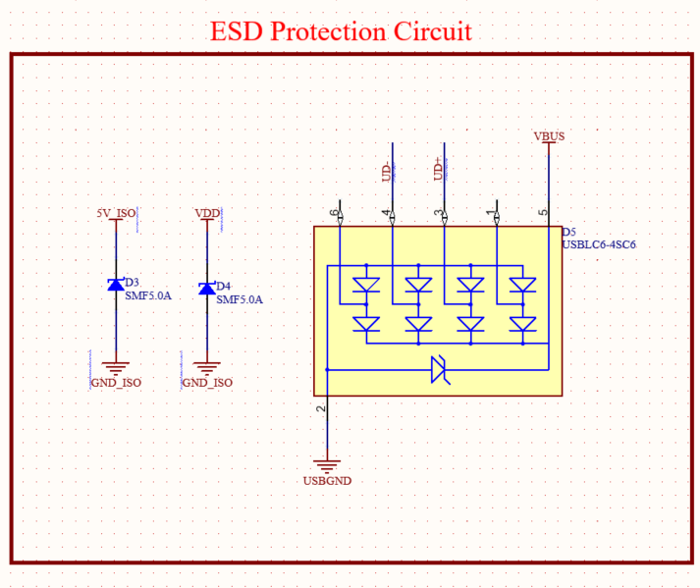
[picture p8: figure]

Figure 6. ESD Protection Circuit

This circuit provides electrostatic discharge (ESD) protection for the USB interface and critical signal lines. Transient voltage suppression (TVS) diodes are placed on key lines, including VBUS, TX, and RX, to protect against voltage spikes caused by electrostatic events or external disturbances. The USBLC6-4SC6 device is used to protect the USB data lines (D+ and D−) by clamping high-voltage transients safely to ground (USBGND), ensuring the integrity of the communication interface. Additional TVS diodes (SMF5.0A) are used on power and signal lines referenced to the isolated ground (GND_ISO), providing localized protection within the system. This design helps prevent damage to sensitive components, improves system robustness, and ensures reliable operation in environments where ESD events may occur.

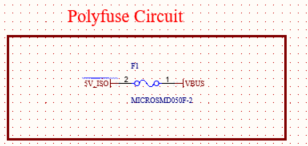
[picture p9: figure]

Figure 7. Polyfuse Circuit

This circuit implements overcurrent protection using a resettable polyfuse (PTC fuse) on the 5V supply line. The polyfuse is placed between the isolated 5V supply (5V_ISO) and the downstream VBUS rail, allowing normal current flow during standard operation. If excessive current is drawn due to a fault or short circuit, the polyfuse increases its resistance significantly, limiting the current and protecting the rest of the system. Once the fault is removed, the polyfuse automatically resets to its low-resistance state, restoring normal operation without requiring replacement. This provides a simple and reliable method of protecting the power path from damage.

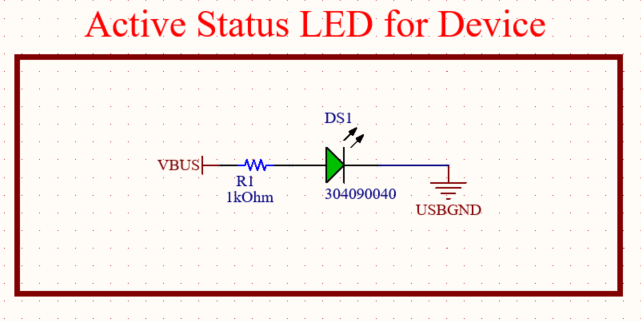
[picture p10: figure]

Figure 8. Active Status LED for Device

This circuit implements a simple status indicator using an LED to show when the device is powered. The LED is connected to the VBUS line through a current-limiting resistor, allowing it to illuminate whenever USB power is present. The resistor ensures that the LED operates within a safe current range, preventing damage while providing visible indication. The LED is referenced to USB ground (USBGND), making it active as soon as the USB cable is connected. This provides a quick and intuitive visual confirmation that the device is receiving power.

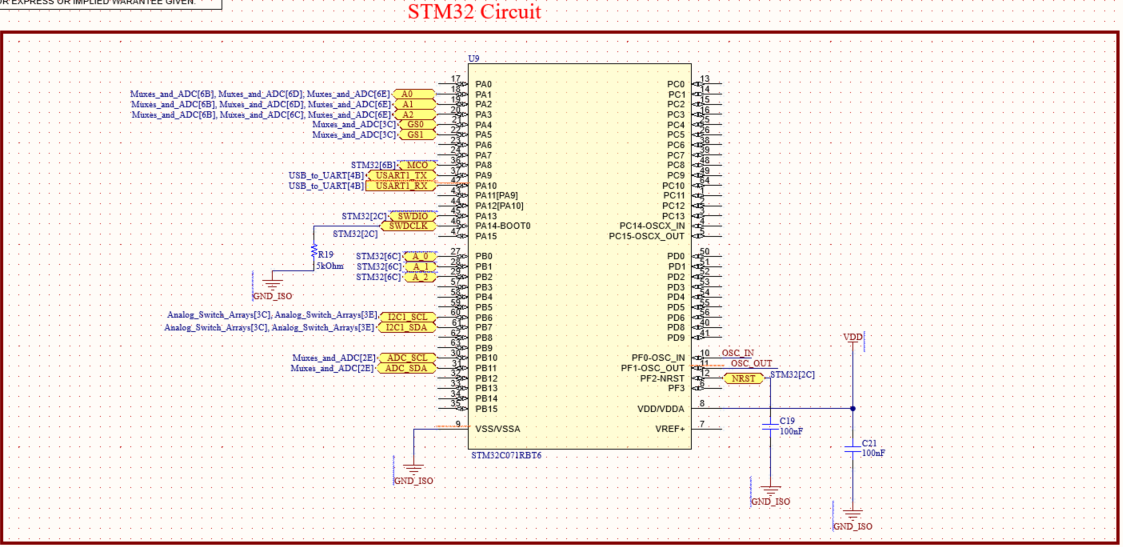
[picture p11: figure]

Figure 9. STM32 Circuit

This circuit implements the STM32 microcontroller as the central control unit of the system, responsible for coordinating data acquisition, processing, and communication. The microcontroller interfaces with multiple subsystems, including the USB-to-UART bridge for communication, the ADC for measurement data, and external circuitry through GPIO pins. Power is supplied through the 3.3V rail (VDD), with local decoupling capacitors placed near the supply pins to ensure stable operation and reduce noise. The reset (NRST) and oscillator (OSC_IN/OSC_OUT) pins are configured to support reliable startup and clock generation. Additionally, communication interfaces such as I²C (SCL/SDA) and UART (TX/RX) are connected to enable interaction with peripheral devices and sensors. Overall, the STM32 serves as the core processing element, managing system logic, data flow, and control functionality.

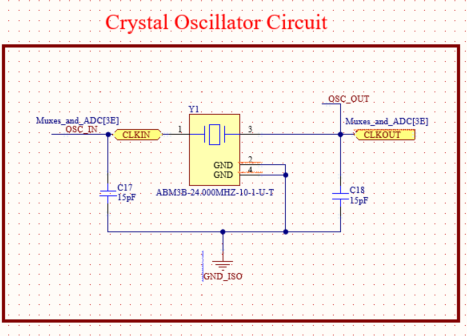
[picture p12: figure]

Figure 10. Crystal Oscillator Circuit

This circuit implements a crystal oscillator to provide a stable clock signal for the system. The 24 MHz crystal (ABM3B series) is connected between the microcontroller’s oscillator input (OSC_IN) and output (OSC_OUT) pins, forming a feedback loop required for oscillation. Two load capacitors (15 pF each) are connected from each side of the crystal to ground (GND_ISO) to stabilize the oscillation frequency and ensure reliable startup. The crystal generates a precise and stable clock signal (CLKIN/CLKOUT), which is essential for accurate timing, communication, and overall system operation.

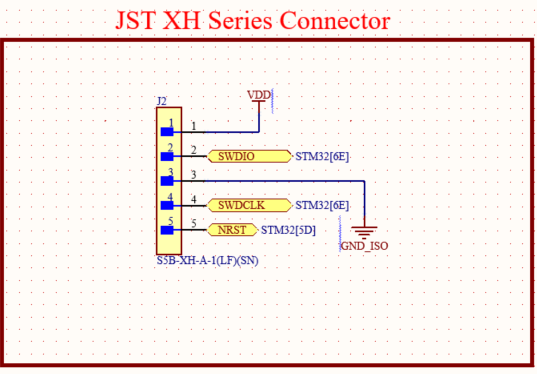
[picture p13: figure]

Figure 11. JST XH Series Connector

This circuit implements a JST XH series connector to provide an external programming and debugging interface for the STM32 microcontroller. The connector exposes key signals, including SWDIO and SWCLK for Serial Wire Debug (SWD) communication, as well as NRST for resetting the microcontroller. A 3.3V supply (VDD) and ground (GND_ISO) are also included to power the debugger and establish a common reference. This interface allows for firmware programming, real-time debugging, and system testing, making it an essential tool for development and troubleshooting.

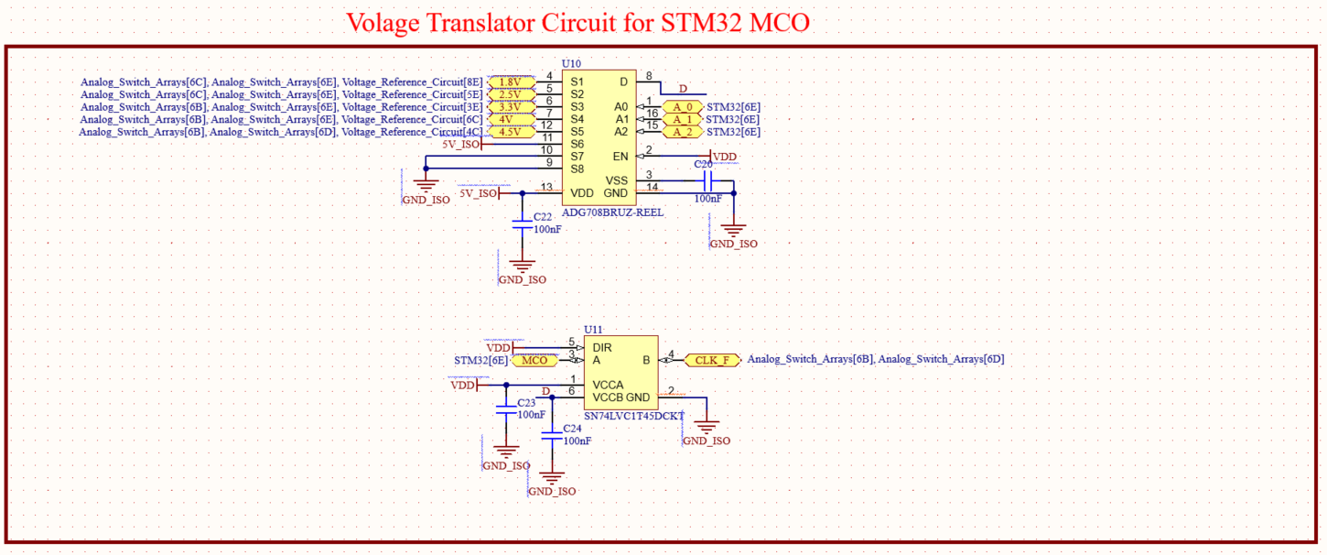
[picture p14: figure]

Figure 12. Voltage Translator Circuit for STM32 MCO

This circuit implements voltage translation and selection to ensure compatibility between the STM32 and devices under test (DUT) operating at different logic levels. An 8:1 multiplexer is used to select from multiple reference voltages (e.g., 1.8V, 2.5V, 3.3V, 4V, 4.5V, and 5V) generated by the voltage reference circuit, allowing the system to dynamically choose the appropriate logic level for the DUT. In addition, a 74LVC series level translator is used to shift the STM32’s MCO (microcontroller clock output) signal from its native 3.3V domain to the selected voltage level, ensuring proper signal compatibility. Together, this circuit enables flexible, multi-voltage operation and reliable interfacing with a wide range of logic devices.

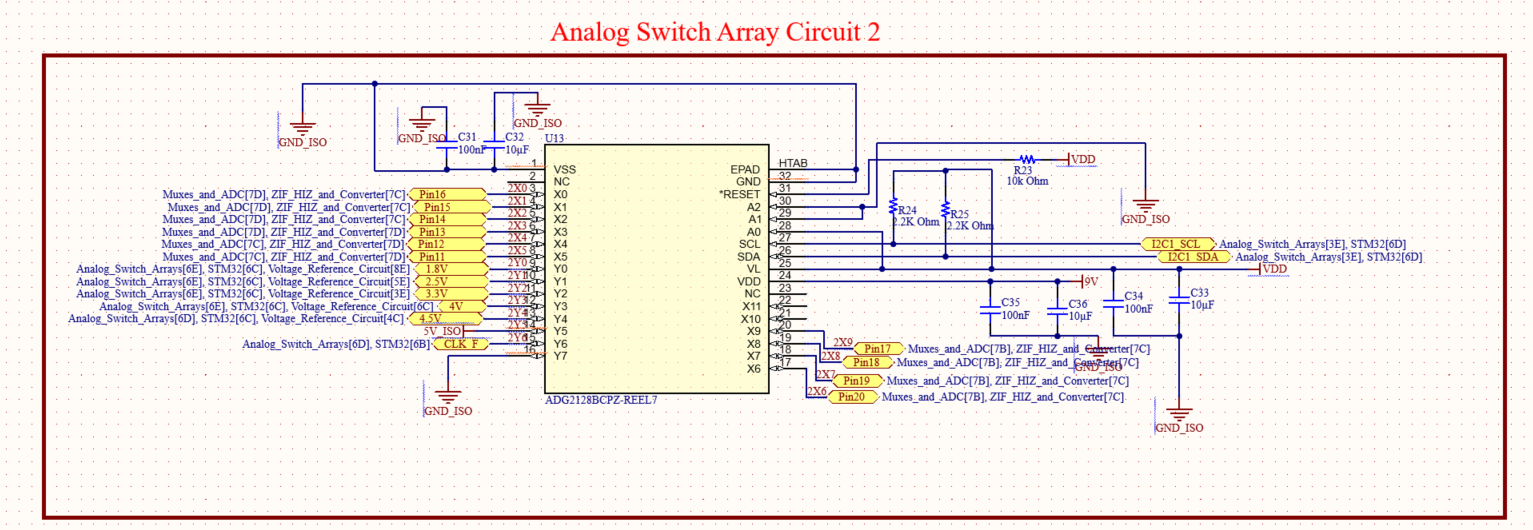
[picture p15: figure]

Figure 13. Analog Switch Array Circuit

This circuit implements an analog switch array that enables flexible routing of multiple voltage levels and signals throughout the system. The ADG2128 switch matrix allows different input voltages, including 1.8V, 2.5V, 3.3V, 4V, 4.5V, and 5V, as well as clock and measurement signals, to be selectively connected to various outputs under digital control. The device is controlled via an I²C interface (SCL and SDA) from the STM32, allowing dynamic configuration of signal paths in real time. Pull-up resistors are used on the I²C lines to ensure proper communication, and decoupling capacitors are included to stabilize the power supply. This design enables reconfigurable signal routing, allowing the system to adapt to different testing conditions and voltage requirements efficiently.

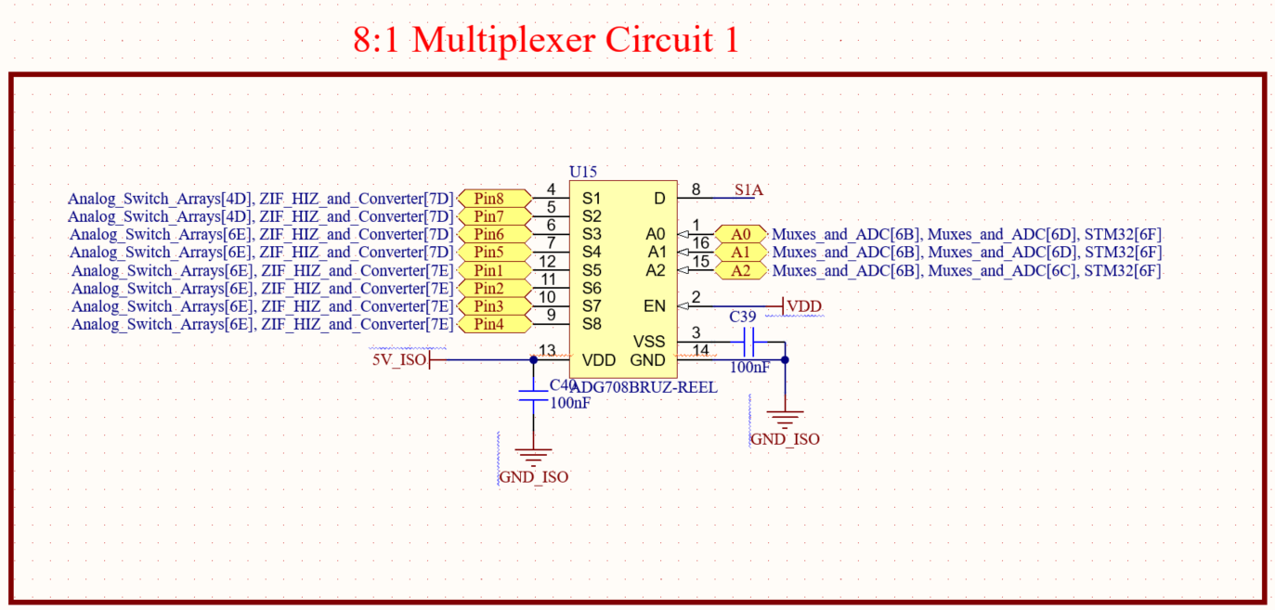
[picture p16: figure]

Figure 14. 8:1 Multiplexer Circuit

This circuit implements an 8:1 multiplexer that allows the system to select one of multiple input signals and route it to a single output. The ADG708 multiplexer receives several input signals, including outputs from the analog switch array and measurement circuitry, and selects one based on the control signals (A0, A1, A2) provided by the STM32. This enables dynamic signal selection and efficient use of a single ADC channel for multiple inputs. The device is powered from the isolated supply (5V_ISO) with a local decoupling capacitor to ensure stable operation. Overall, this circuit provides flexible signal routing and reduces the need for multiple ADC inputs by multiplexing several signals into one.

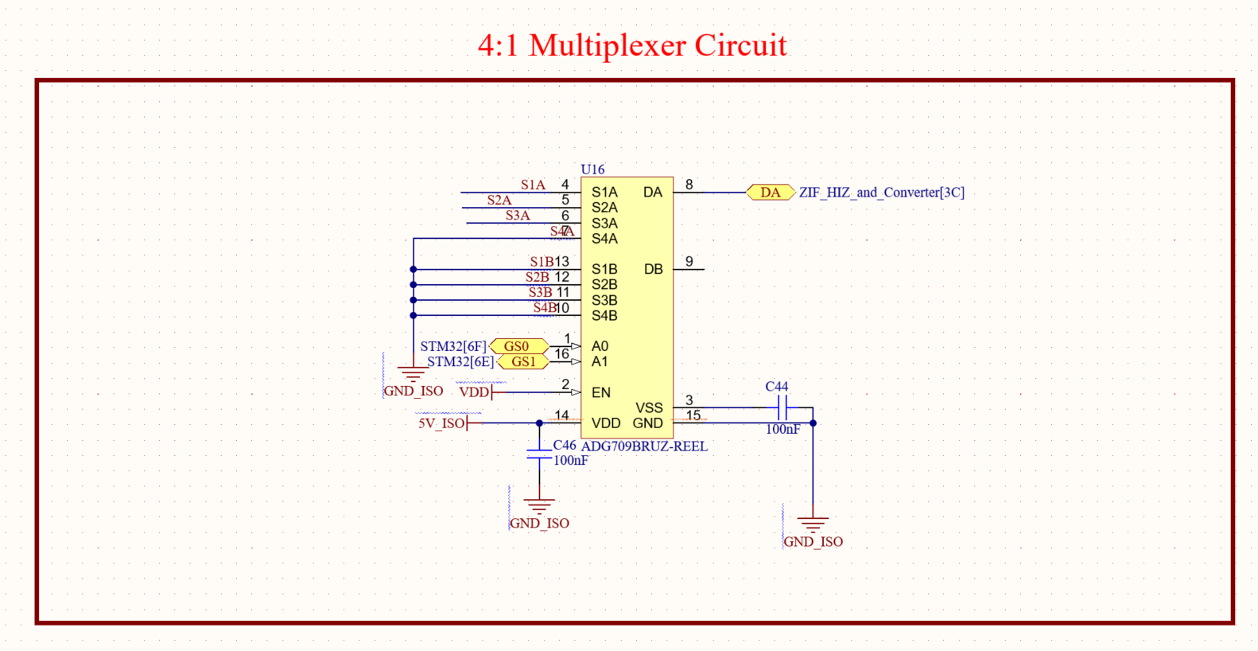
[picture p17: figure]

Figure 15. 4:1 Multiplexer Circuit

This circuit implements a 4:1 multiplexer that selects one of multiple input signals and routes it to a single output for further processing. The ADG708 device receives inputs from different signal paths and uses control lines (A0 and A1) from the STM32 to determine which input is passed to the output (DA). An enable (EN) pin allows the multiplexer to be activated or disabled as needed. The device is powered using the isolated 5V supply (5V_ISO), with a local decoupling capacitor to ensure stable operation. This configuration allows efficient signal selection and routing, enabling multiple signals to share a single processing path while maintaining system flexibility.

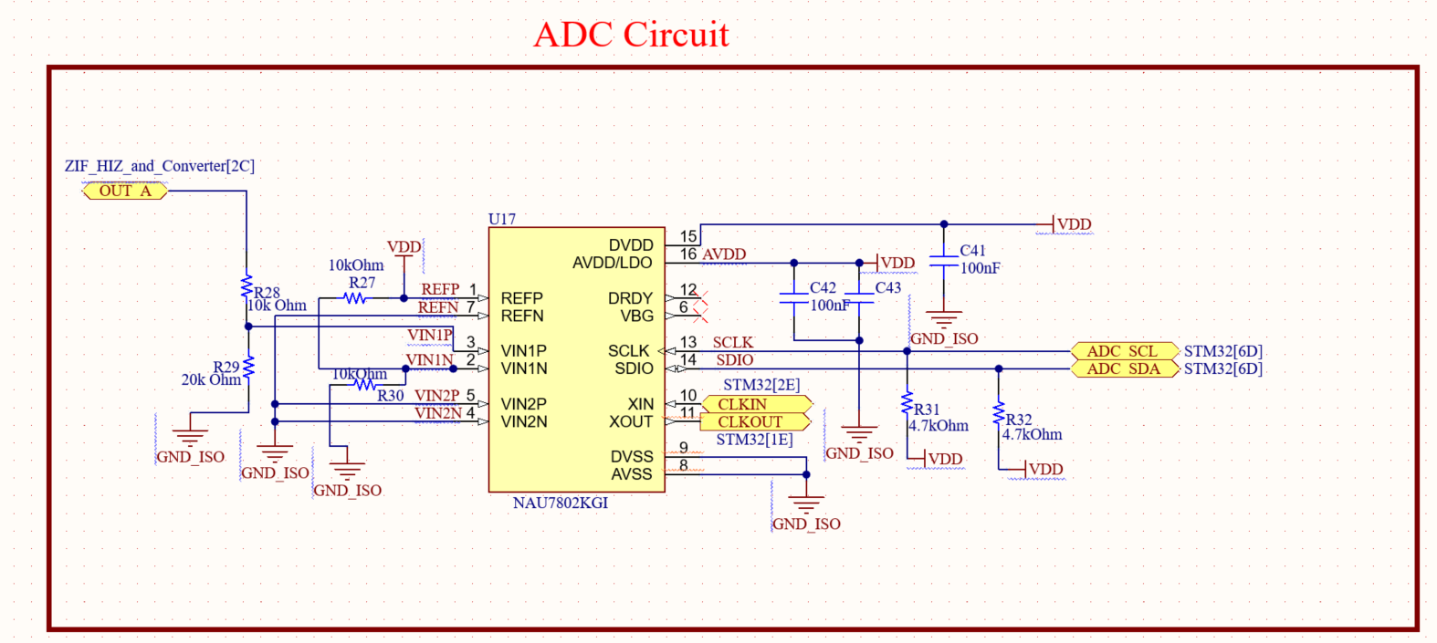
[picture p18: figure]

Figure 16. ADC Circuit

This circuit implements a high-resolution ADC stage using the NAU7802 to convert analog signals into digital data for processing by the microcontroller. A voltage divider network is incorporated at the input to scale down incoming signals, ensuring that the voltage presented to the ADC does not exceed the programmable gain amplifier (PGA) input limit of approximately 2.5V. This prevents signal clipping and allows the ADC to accurately measure higher input voltages without distortion. The conditioned signal is then applied to the differential input pins (VIN1P/VIN1N and VIN2P/VIN2N) for precise measurement. The ADC is powered by the 3.3V supply (VDD), with local decoupling capacitors used to minimize noise and maintain stability. Communication with the STM32 is handled through an I²C interface (SCL and SDA), with pull-up resistors ensuring proper signal levels. Overall, this design enables accurate, low-noise measurements while safely accommodating a wider input voltage range.

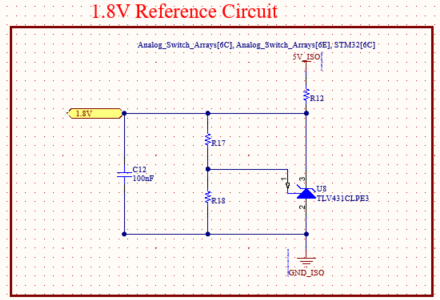
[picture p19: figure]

Figure 17. Voltage Reference Circuit for 1.8V

This schematic shows a set of precision reference voltage circuits that generate multiple stable voltage levels 1.8V, 2.5V, 3.3V, 4V, and 4.5V used throughout the system for accurate analog measurements and signal conditioning. Each reference circuit follows a similar design approach, where a resistor divider network is used to scale a higher supply voltage down to the desired level, and a precision reference device (TLV431) stabilizes the output. The resistor pairs are carefully selected to produce the target voltage, while the reference diode ensures that the output remains constant despite variations in supply voltage or load conditions and reducing current usage in the circuits as well.

In each circuit, capacitors are included to filter noise and improve stability, ensuring that the reference voltage remains clean and suitable for sensitive analog operations such as ADC conversions. The presence of these capacitors helps suppress high-frequency noise and prevents fluctuations that could degrade measurement accuracy. Some circuits also include additional resistors to provide proper biasing for the reference device, ensuring it operates within its optimal range.

These reference voltages are distributed to different parts of the system, such as the analog multiplexers and switch arrays, where precise voltage levels are critical for accurate signal interpretation. By generating multiple reference levels, the design allows flexibility in measuring signals across different ranges and improves the overall resolution and reliability of the system.

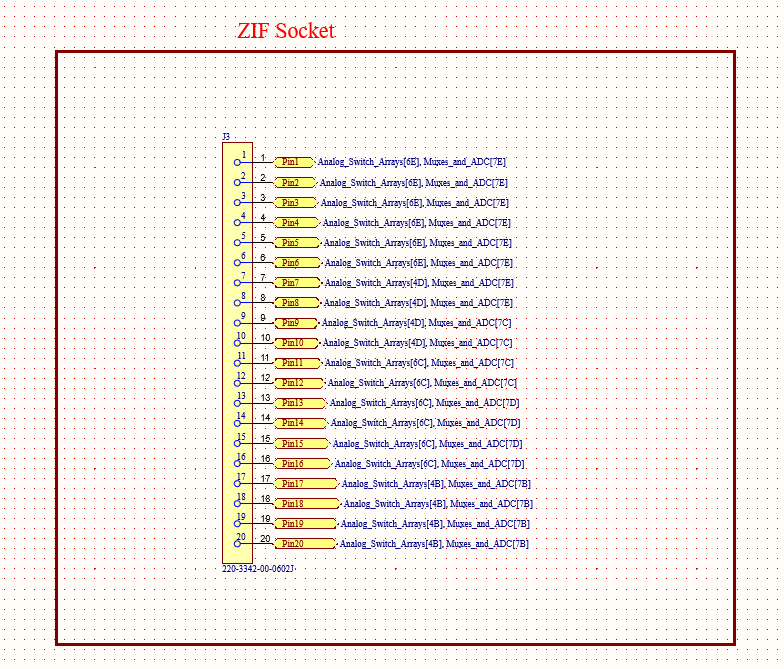
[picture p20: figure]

Figure 18. ZIF Socket

This schematic represents the external interfacing and signal conditioning portion of the system, consisting of a ZIF (Zero Insertion Force) socket, a voltage conversion circuit for the switch arrays, and a high-impedance buffer stage for the ADC. The ZIF socket serves as the primary interface for connecting the test components to the system. It exposes multiple analog signal lines, which are routed into the internal circuitry for measurement. These signals correspond to the various channels handled by the analog switch arrays and multiplexers, allowing the system to flexibly acquire data from many external sources while maintaining ease of connection and removal.

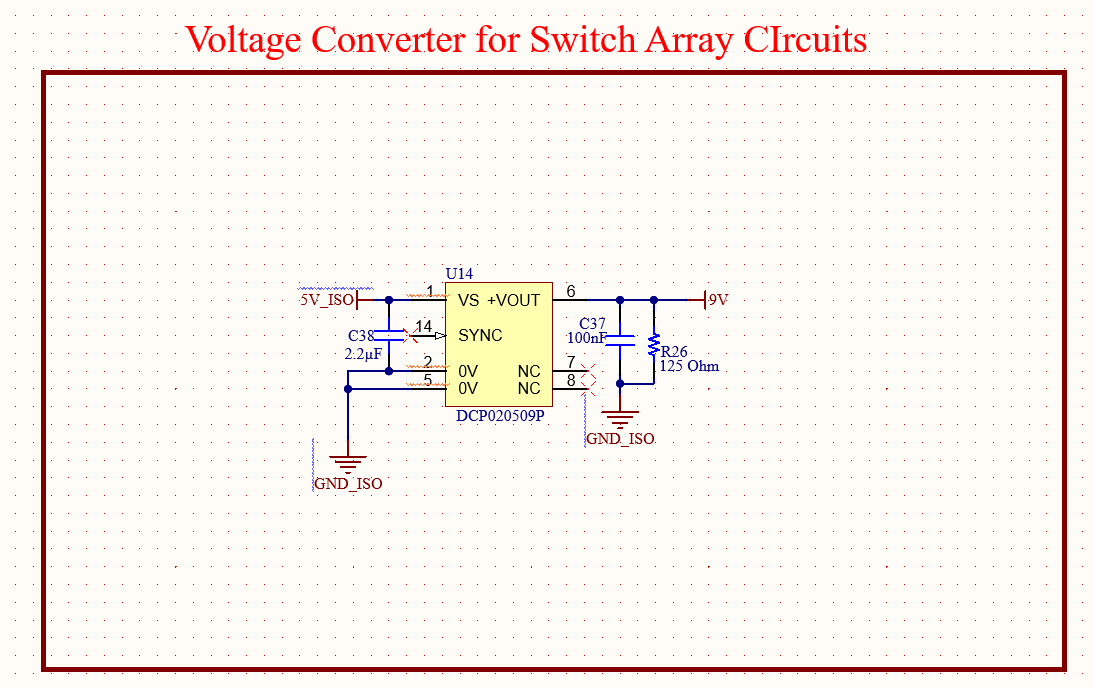
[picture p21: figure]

Figure 19. Voltage Converter for Switch Array Circuits

The voltage converter block provides a regulated supply specifically for the analog switch array circuits. This is implemented using a DC-DC converter to step-up the input voltage to a level suitable for the analog switches. Proper decoupling capacitors are included to ensure a stable output and minimize noise, which is critical for maintaining signal integrity in analog switching applications. Supplying a dedicated, clean voltage to the switch arrays helps reduce interference and ensures consistent switching behavior across all channels.

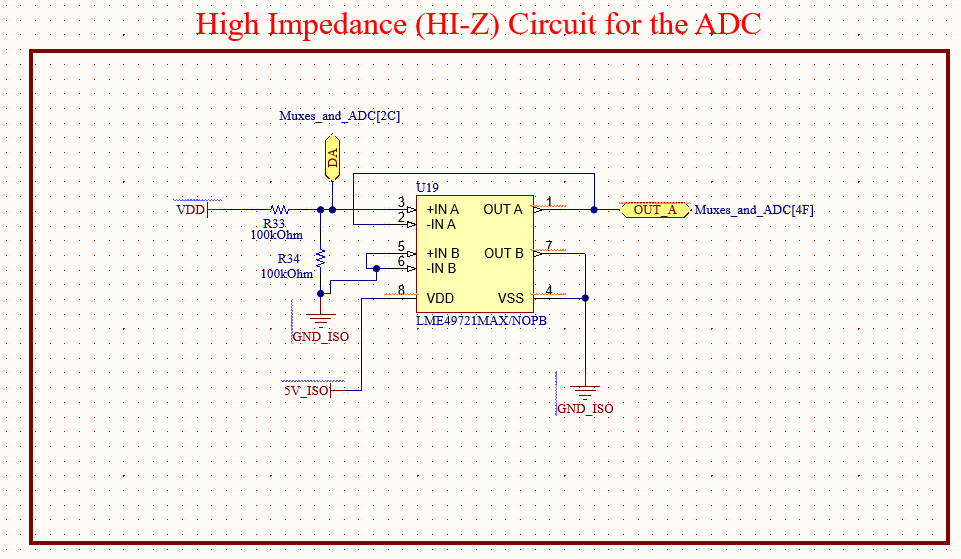
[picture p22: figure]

Figure 20. High Impedance Circuit for ADC

The high-impedance (Hi-Z) circuit is specifically designed to allow the ADC to measure a high-impedance condition, effectively representing an open circuit. This is achieved using an operational amplifier configuration that isolates the ADC input from the rest of the circuit, preventing loading effects and ensuring that minimal current is drawn from the measured node. By presenting a very high input impedance, this stage allows the system to accurately detect open or near-open conditions without influencing the signal itself. This is particularly important in measurement or diagnostic applications where distinguishing between connected and disconnected states is required.

IX. PCB LAYOUT

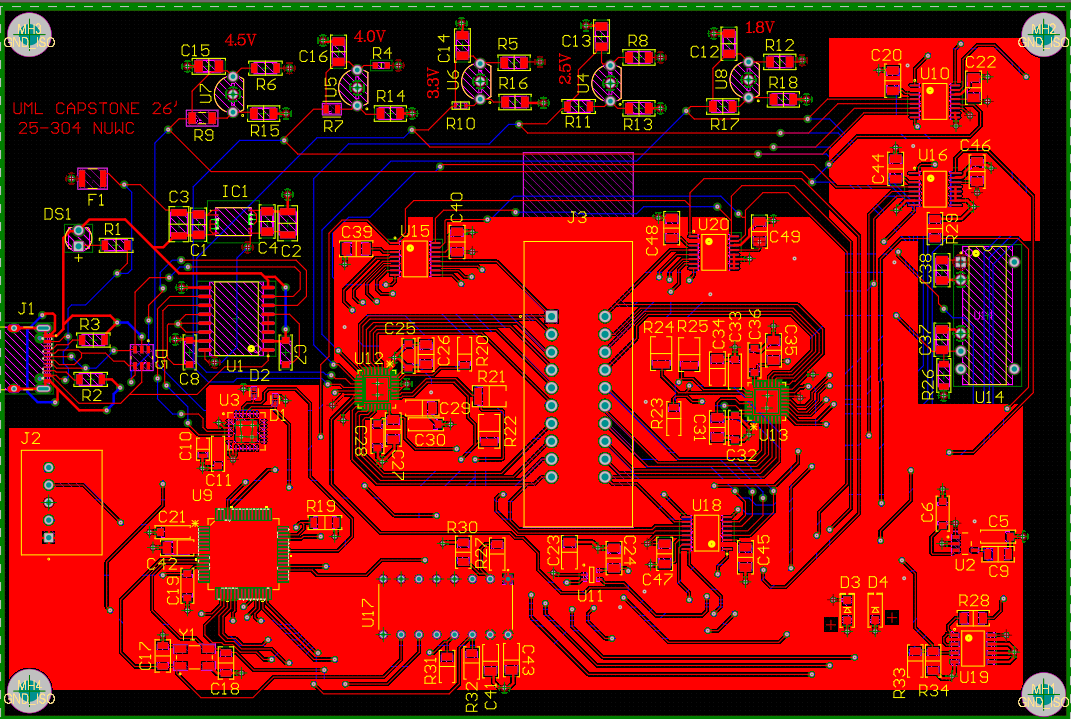
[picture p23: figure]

Figure 21. Top Layer 2D View of the PCB Layout

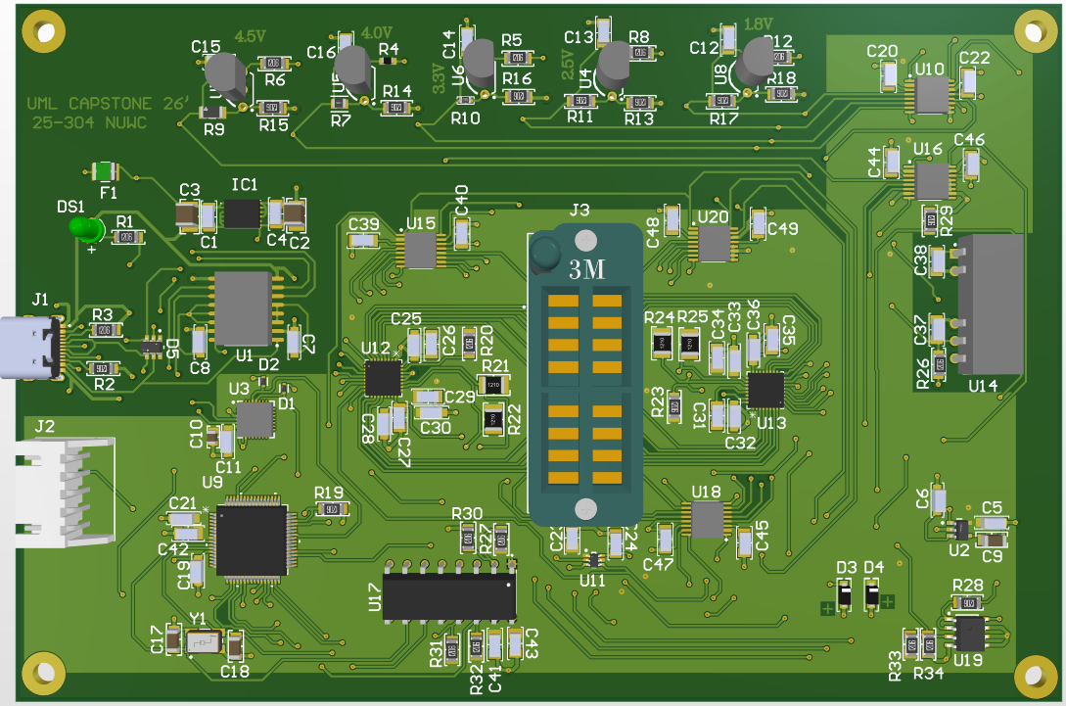
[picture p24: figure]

Figure 22. Top Layer 3D View of the PCB Layout

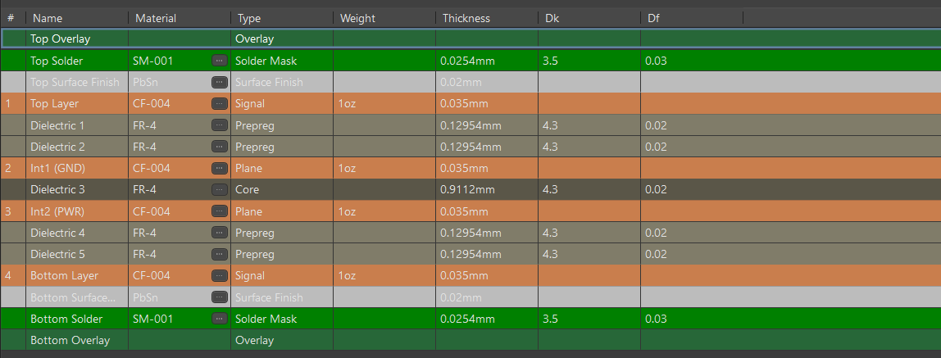
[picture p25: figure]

Figure 23. Layer Stack Setup of the board.

The PCB layout was designed to ensure signal integrity, minimize noise, and maintain clear separation between power domains. A multi-layer stackup was used, with dedicated ground and power planes to reduce impedance and improve stability.

Careful attention was given to routing sensitive analog signals, particularly those connected to the ADC, to minimize interference from digital switching noise. Short trace lengths and proper decoupling were used to improve measurement accuracy.

Differential USB data lines (D+ and D−) were routed as a matched pair to maintain signal integrity and comply with USB specifications. Ground planes were used extensively to provide shielding and reduce electromagnetic interference.

Power distribution was organized to separate the isolated and non-isolated domains, ensuring that noise from the host system does not affect measurement performance. Overall, the layout supports reliable operation and accurate signal acquisition.

X. LIMITATIONS

While the system provides significant flexibility, several limitations exist:

- The test fixture supports a maximum of 20 pins, limiting compatibility to specific IC packages.
- The ADC input range is constrained and requires voltage scaling for higher input signals.
- Analog multiplexing introduces switching delays, limiting high-speed signal analysis.
- USB 2.0 communication limits data transfer rates for high-throughput applications.
- The system is optimized for logic-level testing and is not suitable for high-frequency RF measurements.

XI. CONCLUSIONS

The reconfigurable test fixture presented in this work provides a flexible, accurate, and robust platform for evaluating 7400-series digital integrated circuits across a wide range of operating conditions. By integrating programmable signal routing, multi-level voltage references, and high-resolution analog-to-digital conversion, the system enables comprehensive testing of logic behavior while minimizing hardware complexity. The use of electrical isolation, ESD protection, and regulated power domains enhances system reliability and protects both the device under test and the host interface. Additionally, the incorporation of a microcontroller-based control architecture allows for automated configuration, data acquisition, and communication with a host PC, improving usability and scalability. Overall, the design successfully meets its intended objectives by combining adaptability, precision, and safety, making it suitable for both educational applications and practical digital IC validation environments.

XII. REFERENCES

[1] Global Connector Technology, “USB4105 USB Type-C Receptacle for USB 2.0, SMT Type, PCB Top Mount – Product Specification,” Rev. A1, Oct. 2019. [Online]. Available: USB4105 Datasheet

[2] Texas Instruments, “UCC33420 Ultra-Small, 1.5W, 5.0V, 3kVRMS Isolation Industrial DC/DC Module Datasheet,” Rev. E, Apr. 2025. [Online]. Available: UCC33420 Datasheet (https://www.ti.com/lit/ds/symlink/ucc33420.pdf?utm_source=chatgpt.com)

[3] Analog Devices, “ADuM4160 Full/Low-Speed USB Digital Isolator Datasheet,” Rev. D, 2024. [Online]. Available: ADuM4160 Datasheet (https://www.analog.com/media/en/technical-documentation/data-sheets/adum4160.pdf)

[4] Silicon Laboratories, “CP2102C USB-to-UART Bridge Datasheet,” Rev. 1.6, 2023. [Online]. Available: https://www.silabs.com/documents/public/data-sheets/cp2102c-datasheet.pdf

[5] Littelfuse, “MICROSMD050F-2 Resettable PTC Fuse Datasheet,” 2022. [Online]. Available: https://www.littelfuse.com

[6] Texas Instruments, “TPS7A20 300-nA IQ, 300-mA Low-Dropout Regulator Datasheet,” Rev. H, 2024. [Online]. Available: https://www.ti.com/lit/ds/symlink/tps7a20.pdf

[7] STMicroelectronics, “USBLC6-4SC6 Low Capacitance ESD Protection for High-Speed Interfaces Datasheet,” Rev. 7, 2023. [Online]. Available: https://www.st.com/resource/en/datasheet/usblc6-4sc6.pdf

[8] Littelfuse, “SMF Series Surface Mount TVS Diodes Datasheet,” 2022. [Online]. Available: https://www.littelfuse.com/assetdocs/tvs-diodes-smf-datasheet

[9] STMicroelectronics, “STM32C071x8/xB Mainstream Arm Cortex-M0+ Microcontrollers Datasheet,” Rev. 5, 2024. [Online]. Available: https://www.st.com/resource/en/datasheet/stm32c071c8.pdf

[10] Analog Devices, “ADG708/ADG709 8:1/4:1 Analog Multiplexers Datasheet,” Rev. E, 2023. [Online]. Available: https://www.analog.com/media/en/technical-documentation/data-sheets/ADG708_709.pdf

[11] Texas Instruments, “SN74LVC1T45 Single-Bit Dual-Supply Bus Transceiver Datasheet,” Rev. S, 2024. [Online]. Available: https://www.ti.com/lit/ds/symlink/sn74lvc1t45.pdf

[12] Abracon, “ABM3B SMD Crystal Oscillator Datasheet,” Rev. 2022. [Online]. Available: https://abracon.com/Resonators/abm3b.pdf

[13] JST, “XH Series Connector Datasheet,” Rev. 2021. [Online]. Available: https://www.jst-mfg.com/product/pdf/eng/eXH.pdf

[14] Analog Devices, “ADG2128 I²C CMOS 8 × 12 Analog Switch Array Datasheet,” Rev. E, 2023. [Online]. Available: https://www.analog.com/media/en/technical-documentation/data-sheets/adg2128.pdf

[15] Analog Devices, “ADG708/ADG709 8:1/4:1 Analog Multiplexers Datasheet,” Rev. E, 2023. [Online]. Available: https://www.analog.com/media/en/technical-documentation/data-sheets/ADG708_709.pdf

[16] Nuvoton Technology Corporation, “NAU7802 24-Bit Analog-to-Digital Converter Datasheet,” Rev. 2.6, 2021. [Online]. Available: https://www.nuvoton.com/export/resource-files/en-us--DS_NAU7802_DataSheet_EN_Rev2.6.pdf

[17] Texas Instruments, “TLV431 Low-Voltage Adjustable Precision Shunt Regulator Datasheet,” Rev. Z, Jun. 2024. [Online]. Available: https://www.ti.com/lit/ds/symlink/tlv431.pdf

[18] 3M, “3M™ DIP Sockets, 2.54 mm TS-0365 Series Datasheet,” 2010. [Online]. Available: https://multimedia.3m.com/mws/media/494546O/3mtm-dip-sockets-100-2-54-mm-ts0365.pdf

[19] Texas Instruments, “LME49721 High-Performance, Rail-to-Rail Input/Output Audio Operational Amplifier Datasheet,” Rev. C, Apr. 2013. [Online]. Available: https://www.ti.com/lit/ds/symlink/lme49721.pdf

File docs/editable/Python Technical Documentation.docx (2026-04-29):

Python Technical Documentation

This document provides a technical overview of the Python source code developed for the Reconfigurable Integrated Circuit Test Fixture project. It explores the key design decisions and notable data structures that are the foundation of the codebase, as well as how the software interacts both internally and with the associated hardware and firmware components. In addition, the document outlines considerations for future development, offering guidance on future expansion while preserving the program’s modularity, clarity, and overall organization.

High Level Overview

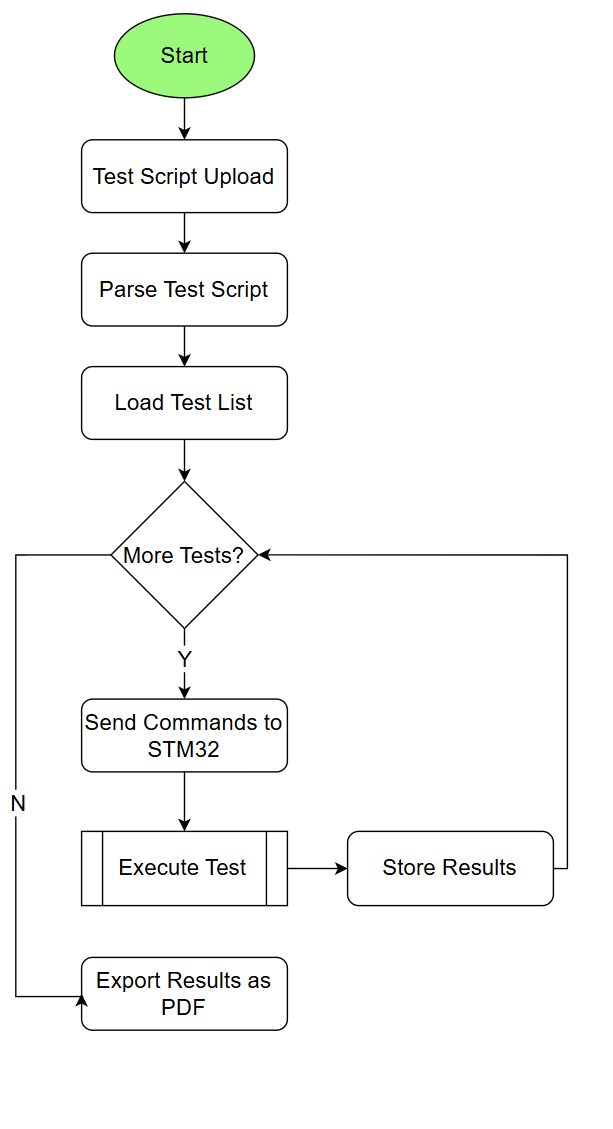
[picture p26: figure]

Figure 1. High level flowchart of program during runtime

The application lets users upload a test script, execute the defined tests, and generate a PDF report of the results. As shown in the flowchart, the program follows a straightforward linear sequence. This approach keeps execution predictable and debugging manageable. Each stage depends on the successful completion of the previous one. Any errors halt the process early and prevent downstream steps from running.

The workflow begins with uploading a test script. Next, the application parses its contents and loads the extracted tests into a list. It then enters a loop to check whether additional tests remain. If so, commands are sent to the STM32 microcontroller, the tests are executed, and the results are stored. The process returns to the decision point until all tests are complete. Finally, the accumulated results are exported into a PDF report.

Most of these operations are handled within the main GUI event loop. The only asynchronous components are the transmission of commands to the STM32 and the storage of test results. While this design generally maintains responsiveness, the GUI can become temporarily unresponsive when handling large or complex scripts—particularly during the upload and parsing stages, where the interface attempts to render and process all script lines at once.


Figure 2. Python project layout

Module | Description | File Name | File Description
device | Handles communication to hardware and require data structures to read and write information | serial_manager.py | Handles all serial communication with test fixture asynchronously
| | test_vector.py | Implements TestVector object to stored parsed information from test scripts and results received during test script execution
file_io | Handles all file-related operations | parser.py | Parsing for algorithm test scripts using PyYAML
| | report.py | PDF report generator using ReportLab’s platypus module
gui | Construct GUI elements and connect backend code in device and file_io | main_window.py | Acts as top-level, constructs the main window of the GUI using PySide6 and integrates all portion of the Python code together
| | tabbed_editor.py | Implements tabbed text editor widget, like NotePad++, VSCode, etc.
| | test_script_wizard.py | Implements QWizard widget that assist in creation of test scripts by offering high-level support in the form of dropdown menus.
utils | Miscellaneous files used to assist the software. | gen_nbit_scripts.py | Creates test scripts where inputs and outputs are based on an n-bits
| | debug.py | Sandbox for testing code

Table 1. Source code layout with brief description

The application contains three modules: device, file_io, and gui, as displayed in Table 1.

The device module implements asynchronous communication with the virtual COM port of the IC test fixture to prevent blocking the main GUI event loop. The module also implements the data structures required to store parsed information from test scripts and the results received. This module is used in the “Parse Test Script” step and the test script execution loop in the flowchart.

The file_io module handles all related file operations, including the implementation of the parsing algorithm, and exporting the results as a PDF file after executing the test script. The module is responsible for the “Parse Test Script” and “Export Results to PDF” steps of the flowchart.

The gui module creates the GUI, including the main window, and user-interactable components required to execute all operations from the flowcharts. These components are connected to the backend code from the device and file_io modules.

The utils module is a spot for miscellaneous Python files. These files may or may not be used to assist in the operation or configuration of the software.

The entry point for the application is main.py which creates and shows the main window.

File IO Module

Parser


Figure 3. Basic layout of parser.py

This file implements the parsing algorithm used to parse the test scripts. The formatting and expected syntax for the test scripts can be found in docs/YAML Test Script Guide. The low-level parsing is done by using PyYAML. PyYAML will read the test script and create a dictionary with keys and values being proper Python data types. The parsing algorithm manually checks that the data is within the hardware’s capabilities and is a valid argument.

At the top of the file are the global macros used by the parsing algorithm. These variables provide the expected logic, voltage levels, and maximum pins the hardware can support. They are implemented as sets for constant lookup times.

Beneath the global macros are parser exceptions. All parser exception types inherit from Python’s base “Exception” class and have no implementation themselves. The purpose of these exceptions is to display the exception type and its error message to the user in the GUI. This allows users to identify the location of the error. For example, a “MissingKeys” error will be shown to the user as “MissingKeys: error_msg.” Adding a line number would also be useful; however, PyYAML does not maintain line numbers for reference.

Following the parser exceptions are the helper functions, denoted by their naming scheme “check_parameter.” These helper functions are used throughout the parsing algorithm, since many operations are repetitive, to ensure arguments are valid. They raise an error if the argument is invalid and simply return if they are.

The functions responsible for the actual parsing are denoted by “parse_section.” These functions are implemented in the same order they are called. All functions first check if the expected sections/parameters are in the test script; otherwise, an error is raised. Any unknown keys will raise a warning.

Inside the “parse” function, PyYAML performs all the low-level parsing, creating a dictionary with all values converted to valid data types, such as int, float, string, or list. Since the data is a dictionary, parsing can easily be accomplished by directly accessing parameters by their designated key in the test script. For example, data[“Global Parameters”][“VCC Pin”] accesses the VCC Pin. Then the VCC Pin can be determined if the pin value provided is valid. There is a function dedicated to parsing each section of the test script. This is done for modularity if more sections are added to the test script in the future. The current parsing order is “Global Parameters,” “Pin Map,” “Truth Table,” and “Tests.”

The functions “parse_truth_table,” and “parse_tests” are unique in that they also parse their respective sections into a different data structure. For the “Truth Table” section, PyYAML creates a list nested dictionary, the “parse_truth_table” function will transform the nested dictionaries shown in Figure 2 into a single dictionary where the column names of the truth table are the keys, and all the values from the nested dictionaries are concatenated into a single list as shown in Figure 3.


Figure 4. Data structure of Truth Table section in test scripts


Figure 5. Resulting data structure of transformed dictionary

The reason why the formatting in Figure 3 of the test scripts isn’t used instead of the structure in Figure 2 is to allow users to write truth tables in the test scripts resembling how truth tables are typically represented. Truth tables typically have inputs on the leftmost columns, and outputs on the rightmost columns, each row representing the inputs required to get the output. From Figure 3, the truth table appears to be rotated, where the rows have the names of the columns, and the columns represent the row of the truth table.

The “parse_tests” function creates a list of TestVector objects. Any information that is required for testing should be passed as argument to this function. The helper function “parse_test_IO” parses the “Inputs” and “Outputs” section of each individual test. In this function, each key-value pair is wrapped into an IOCommand data class. The voltage type and command type are determined by the written command of the test script.

Report


Figure 6. Basic PDF report layout

This file is responsible for exporting the data inside TestVector objects, and other information inside the test script, and exporting the results as a readable PDF file. All data is exported in tabular format for dynamic expansion and formatting. PDF reports are generated using the platypus module from the ReportLab project. The module contains high-level abstractions for creating PDF documents, drawing objects, auto-formatting, and sizing.

At the top of the file are constants for drawing tables for the sections “Chip Info,” “Pin Map,” and “Global Parameters” sections of the test script. The data will simply be represented as key-value pairs; the left side of the chart contains the keys, and the right side of the chart contains the values. The “dict_to_table” function is responsible for creating these types of tables. The “Truth Table” section is not included as the data from the TestVector objects contains all the inputs, expected outputs, and results to be printed out in a tabular format.

The “export_to_pdf” function generates the contents and builds the PDF report. The list variable story is all of the contents to be displayed in the PDF report. The platypus module will display the contents in the same order as the story array, meaning the first element will be at the top of the first page, and the last element will be at the bottom of the last page. The function first generates the information tables by calling “dict_to_table” and appends them to the story. Then the function will iterate over a list of TestVector objects, calling the “export_to_table” function. For each TestVector object, it will create a table for the data and create a TableStyle object to format the table using the metadata returned from the “export_to_table” function. This is accomplished by creating style commands and concatenating all of them into a list. The primary purpose of these commands is mainly to center and span empty cells in the table. Empty cells are equivalent to empty strings, and spanning will combine cells together. Spanning is useful for creating cells that need to be subdivided into multiple rows or multiple columns.

Device Module

Test Vector


Figure 7. Basic layout of test_vector.py

This file implements the TestVector class and all associated data structures required for testing.

The enumerated type LogicMapping is used to represent the type of command. The type of command determines how the specified pin(s) map to the specified value(s).

The data class IOCommand represents a line in the “Inputs” and “Outputs” sections of tests. IOCommand stores the pins, and their respective values are stored as a list. The fields volt_type and cmd_type are used during testing for the voltage of a HIGH signal, and how to map pins to their respective values.

The data class PinResult is used for storing the received logic and ADC result (in Volts).

The data class Condition is used for representing a test condition. The possible conditions are the VCC voltage and its respective output low and high thresholds from the test script. This is used by TestRunner to keep track of the current condition a test is being performed with.

The TestVector class contains all the necessary information used to perform a test. Any additional information needed should be added to the constructor. TestVector contains the following: global_params, pin_map, inputs, outputs, results, test_name, and passed. The first two fields contain information for test conditions and the abstracted pin names. The inputs and outputs are a list of IOCommands that are used to write commands and compare results, respectively. The results field is a 3-layer dictionary used to store the results received from the test fixture. The remaining fields are for the name of the test provided in the test script, and a Boolean for if a test has passed, and all results match the expected outputs. If an input or output contains a serial command, all inputs and outputs are padded to be the same length as the longest serial command. The padded logic is the last logic value in the command. This is because the firmware expects serial commands to be the same length, or the logic is a single voltage.

The results field is a 3-layer dictionary, so each result for a pin can be accessed in constant time. The keys for the layers of the dictionary are in this order: the VCC voltage condition, the step number, and the pin that was measured. The step number is an output of the firmware, which is used for serial inputs. For tests with no serial inputs, the step number is always 0.

The methods “test_conditions” and “power_pins” return all test conditions and power pins, including the VCC voltage from global_params. These are used for generating the PRM and VIN commands expected by the firmware. The method “pin_lists” converts all input IOCommand into a list of pins and voltage input, and all output IOCommand to a list of pins to be measured by hardware. These lists are used for generating the INS, VIP, and OUT commands.

The method “compare_results” will compare all output IOCommand to the logic received from the test fixture stored in results. In this function, the logic will be converted from an integer to the same value type used in the test script. For example, the firmware returns a 0 for LOW, if the expected output for the pin is “L,” 0 is replaced with “L” inside the results. If the expected output was an integer, then nothing changes. When exporting the results to a PDF report, the expected output and received results share consistent formatting. If the received logic does not match the expected output, TestVector’s pass field is set to False and cannot be changed.

The method “export_to_table” exports all the IOCommand data classes and results in a tabular format, along with their metadata. The exported table is a 2D array, where each list in the array represents a row of data, which is represented by strings. The table includes headers and empty cells (created by empty strings, “”). The empty cells are used when the data in cells needs to span multiple rows or columns. It does not matter where the data is for spanning, but it is recommended to be stored in the left and top-most cells, as the metadata of the table assumes this logic. Unlike input pins that may share columns, the output pins are unraveled from the lists and receive their own columns. This allows the results of each pin to have their own cell to enhance the readability of the table. If a test has multiple test conditions, the VCC column is included, it is omitted. If the VCC column is included, the expected result cells are subdivided to match the number of different test conditions.

The metadata of the table is used for formatting the table in the PDF report, specifically indicating to ReportLab Platypus to span certain rows and columns. The metadata dictionary includes input_span, output_span, num_rows, include_vcc, and num_vcc. The input_span represents the number of input IOCommand. The output_span represents the number of output pins in total from all output IOCommand. These two parameters affect the spanning for rows. The remaining parameters represent the number of rows in the table, if the table includes a VCC column, and the number of different test conditions. These arguments affect the column and row spanning.

The private methods, denoted by the starting “_” character, are helper functions used to assist in translating higher-level test script inputs into low-level hardware commands, or vice versa for test script outputs. These functions should never be called directly outside of unit testing.

For debugging purposes, the method “simulated_test,” and its helper “_get_exp_val,” will roughly simulate the execution of the test. These methods are used in unit tests to verify the implementation of the “_compare” and “export_to_table” methods.

Serial Manager

This file implements serial communication with the test fixture. The SerialManager class is responsible for serial communication. The SerialProtocol base class is the recommended template to implement different types of communication protocols. SerialManager contains the signals done, error, and status_msg, and line_received. These signals are intended to update the GUI asynchronously from the event loop. SerialManager maintains a buffer for all responses received by the test fixture, and keeps track of the current active protocol.

The BIST class sends the “BIST” command to trigger the Built-In Self Test feature of the test fixture. The fixture will test the hardware peripherals exhaustively to verify the circuit is operating within the thresholds.


Figure 8: Basic layout of serial_manager.py

The TestRunner class executes tests in the given list of TestVector objects at all specified VCC voltages. All commands are sent encoded in UTF-8, with a new line at the end of each string. The implementation assumes that after every command is received, the STM32 will send a response ending with a new line character. This is important because commands are sent directly after receiving a response.

The TestRunner field cmds is a deque, which stores all the commands of a test at a condition. The first element of the deque is the command sent to the hardware. If there are no more elements in the deque, nothing happens. The remaining fields, conditions, test_idx, cond_idx, and stop, are used to keep track of the current progress of the tests. If stop is True, an error occurred during testing, and no commands will be sent. Currently, the expected responses are based on the starting characters: “ERR,” “Done,” and “STEP.” If an “ERR” is received, the error signal is emitted, and test execution is stopped. If “Done” is received, this means the test executed successfully, and if “STEP” is received, the string is parsed, and the resulting ADC value and logic are stored into the current TestVector object. Any other response is simply printed to the GUI, and the next command is sent if possible.

GUI Module

Main Window


Figure 9. High level overview of the application and the connections to MainWindow

This file serves as the top-level entity, connecting all backend code in the device and file_io modules with GUI elements.

All GUI elements are created using PySide6, a Python binding to the Qt framework. Qt offers additional apps such as QtCreator, an IDE for GUI development. QtCreator offers a drag-and-drop editor, which is useful for creating complex GUI elements if programming them in Python is difficult. The PySide6 library is used for this project due to its modern UI appearance and wide widget selection, including QSerialPort, which runs asynchronously, simplifying the communication portion. PySide6 also supports signals and slots that can be used to execute tasks outside of the GUI event loop.

The main window offers basic text editor support, like NotePad++ and Visual Studio Code. This allows users to edit test scripts with minor mistakes without needing another text editor app. The QTextEdit widget at the bottom displays updates throughout the program, mainly serial communication with the hardware to inform users of any errors the program encounters and update the status on test script execution. This also acts as a log for the program.

To execute test scripts, or send commands to the STM32, functions should be connected to buttons of the run menu. These functions should create an object derived from SerialCommunication and be implemented in the directory device/, or in serial_communcation.py itself. SerialCommunication must be assigned to the field serial_handler and connect both the done and error signals to _cleanup_serial_handler. This ensures only one object will use serial communication and the readyRead signal is not connected to multiple SerialCommunication objects.

This file will create instances of any objects that are required during the application’s runtime and include any default settings. Currently, it dynamically finds the serial port by searching for the CP2102 USB-to-UART bridge information (VID: 0x10C4, PID: 0xEA60), with the serial number 554D4C2043617073746F6E652032352D333034204E5557432032303236.

Not shown in Figure 9, on startup, the application will first do a SHA-256 checksum for the executable application and raise a warning to the user if the checksum does not match the expected value. The expected checksum is stored as the last 32-bytes of the executable and calculated using every byte of the executable excluding the last 32-bytes. This checksum is appended during the building of the application. This will only apply for the compiled executable and not during development. After that, the GUI will open the serial port and execute the checksum command for the STM32. If the checksum received by the STM32 does not match EXEPECTED_CHECKSUM, a warning will be raised similar to the application’s checksum.

Tabbed Editor

This file creates the Tabbed Editor widget, a collection of QPlainTextEdit objects switchable via the QTabWidget. Most basic text editor features are implemented here, such as key shortcuts, special symbol on the tab, indicating the contents of QPlainTextEdit object has been modified. All functions are implemented based on the current QPlainTexEdit in focus on the GUI as it is unlikely a user will want to modify a file that is not in focus.

A dictionary is used to keep track of which file each QPlainTextEdit object originates from. If a blank QPlainTextEdit was created, the file path is None. The dictionary’s key is the QPlainTextEdit object, and the file path is the value. When a tab is closed, the QPlainTextEdit is popped from the dictionary and the QPlainTextEdit is saved before deleting.

Tabbed Editor has two signals tab_added, and no_tabs. These two signals are connected to the main window of the GUI. The main window will display the directions to create a new file when there are no tabs opens, and swap to the tabbed editor widget when there is at least one.

Test Script Wizard

This file creates the TestScriptWizard widget, a QWizard widget offering high-level support for YAML test script generation. The widget simplifies the test script writing process by using a variety of dropdown menus supported by PySide6. The options for these dropdown menus are limited based on the macros declared in parser.py to guarantee the generated test script is valid.

At the top of the file are sorted lists of the selectable options. These sorted lists are used to instantiate QComboBox widgets, or simply dropdown menus. The “get_value” function will extract the value from any widget. This function can easily be expanded should more types of widgets be used.

Every page of the widget derives from the QWizardPage object. Each page implements its own “validatePage” function. The function returns a Boolean; if false, it will prevent the user from moving onto the next page. The function will extract the data from the entries the user provided into the expected structure that the parsing algorithm expects. The page’s respective “parse” function is called for validation. The order of the pages is the same order as the parsing algorithm’s order. To share information between the pages, as some parsing functions are dependent on other portions, TestScriptWizard contains a dictionary that is accessible via wizard().data in the pages. The page numbers are located near the top of the file as an enumerated type named PageNum. PageNum allows page numbers to be easily changed if the parsing order changes. Page numbers start from 0 and increase upwards. A page number of -1 means it is the last page. The last page (currently TestsPage) will use PyYAML to generate the .yaml file before closing Test Script Wizard.

Most sections of the test scripts can grow dynamically as they are designed to be capable of adapting to the constraints of the chip under test. For example, the “Pin Map” section is the name of the pin, and the pin number on the socket maps to. The number of pins can range from 0 (omitted) to 18 (VCC and GND Pins are reserved). To not flood the screen with dropdown menus or other widget types, the DynamicContainer class is used to create a grid-like arrangement of QWidgets. DynamicContainer grows dynamically based on the number of entries the user requires. DynamicContainer stores these rows as a list of tuples. The first element of the tuple is the list of widgets in the row, and the second element is the delete button for that row. During deletion of the row, the index of the row is located, and the element at the list is popped all widgets in the tuple are deleted. Then, all remaining rows are shifted upwards.

Unit Tests

The unit tests only test the parsing algorithm in parser.py, and the TestVector class in test_vector.py. The parsing algorithm and TestVector class are the most crucial as they serve as the bridge between the abstractions in the test scripts and sending and receiving commands to the hardware portion of the IC Test Fixture. Unit tests are written with the support of the PyTest library. It is highly recommended to run these unit tests after making changes to test scripts or source code to ensure everything works as expected. All unit tests must begin with “test.”

Test classes organize related tests together; for example, the parsing functions have many different conditions where errors are raised. Additionally, using the “::” operator allows developers to run a specific group of tests if it’s unnecessary to run all of the unit tests. The two primary decorators used from the PyTest library are “pytest.fixture,” and “pytest.mark.parametrize.” The first decorator creates a reusable test fixture that all tests in the file can use. Each test will have a unique copy of the test fixture, avoiding any issues where data may be modified in between tests. The second decorator allows the parametrization of test functions, meaning the same function can be used with different inputs. This reduces the amount of code written to do similar tests with only minor changes to the inputs, such as edge cases.

Future Expansion

Coding Style

Any future expansion to the code base should be written following the PEP8 style guide for Python (https://peps.python.org/pep-0008/). The guide outlines standard Python coding conventions that are commonly used for small hobbyists and industry projects.

For documenting the code, it is recommended to use Google style docstrings (https://gist.github.com/redlotus/3bc387c2591e3e908c9b63b97b11d24e). The link provides an example of writing docstrings for various types of code. Many commonly used IDEs support this type of docstring. When hovering over variables, function names, classes, etc, developers will be able to read a short summary of its purpose and expectations if applicable.

Code Expansion

All code should be written with the expectation that it is executed from the software/ directory. This is especially important for any file paths that may are used, whether for configuration or testing. Additionally, to enable cross-platform development, it is recommended to use the pathlib library, as it is OS-independent and will automatically create file paths expected by the OS.

To maintain the project’s structure, it is important to create any new source files inside a module, whether it’s an existing one listed in Table 1.1, or a new module (or submodule) if the source code implements a distinct new feature. The __init__.py file indicates to the Python interpreter that a directory is a package; while not required, it is still highly recommended for modern Python projects. The main.py file should likely not be changed unless there is startup logic that should be conducted before showing the main window or a different color palette is desired. This file serves as the user entry point of the application and should never implement any core logic or features.

If the test script is expanded by adding a new section, a new function named “parse_section_name” should be implemented in parser.py. For any additional subsections to an already existing section in a test script, the parsing logic should be added to the parsing function for that section or abstracted into a helper function that is called by the parsing function. This maintains the organization of the code, where each section of the test script has its own parsing function and relative helpers. New sections that need to be displayed in the PDF report either need to be a part of the return value for the “parse” function or added as a field in the TestVector class, which is created in the “parse_tests” function.

Any serial communication must be handled asynchronously to prevent the GUI from freezing. The main method for this is PySide6 Signal, which emits a signal under certain conditions and can be connected to a function that will be automatically executed. This prevents the need to poll for potential inputs (typically done by waiting in while-loops), which halts the main event loop. Another method is creating a separate thread using QThread. PySide6 documentation recommends using the worker approach, where a QThread is wrapped inside a QObject to separate the logic you want to run from the responsibilities of QThread. More can be read here: https://doc.qt.io/qtforpython-6/PySide6/QtCore/QThread.html. Creating new threads is only necessary if multithreading performance is required. This is when operations are either expensive or take a long time to execute. Currently, the application only freezes when handling large test scripts, but since most test scripts are expected to be small, QThread objects were not used. It is highly recommended to use the SerialManager to manage all serial communication, and declare a SerialProtocol subclass to manager different types of communication protocols.

All new code should somehow be connected to main_window.py to ensure it is a part of the GUI. Ideally, all parts of the code should also display some status message to the GUI to let the user know of the processes happening, and act as pseudo-log.

Unit tests located in the tests/ directory should be run every time changes are made to either parser.py or test_vector.py. These tests should also be updated if new functions are added or logic is changed. New YAML files should be added to the unittest_yaml/ directory to test various incorrect and correct test scripts.

Package API

Package | Documentation
PySide6 | https://doc.qt.io/qtforpython-6/index.html
PyYAML | https://pyyaml.org/wiki/PyYAMLDocumentation
ReportLab | https://docs.reportlab.com/reportlab/userguide/ch1_intro/
PyTest | https://docs.pytest.org/en/stable/index.html
PyInstaller | https://pyinstaller.org/en/stable/

Table 2. Third-party packages used and links to their documentation.

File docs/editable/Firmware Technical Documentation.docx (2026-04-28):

STM32 Firmware Technical Documentation

Reconfigurable Digital Integrated Circuit Test Fixture

1. Overview

This document provides a technical overview of the STM32 firmware developed for the Reconfigurable Digital Integrated Circuit Test Fixture. It describes the architecture, core modules, communication protocol, and key implementation details required for system operation.

The firmware is responsible for:

- Receiving test commands via UART
- Configuring hardware routing through analog switch arrays
- Driving and stimulating IC inputs
- Measuring outputs via ADC
- Performing fault detection and validation
- Executing automated test sequences

The firmware operates as the central controller between the GUI application and the physical test hardware.

2. System Architecture

2.1 High-Level Operation

The firmware follows a command-driven architecture:

Figure 1. High-Level Firmware Flow

Start → UART Receive → Parse Command → Update State
→ (TEST/BIST/CRC trigger)
→ Execute Operation
→ Send Results via UART
→ Repeat

Execution is event-based using flags set during UART command parsing.

2.2 Core Firmware Files

File | Description
main.c | Entry point, UART handling, command parsing, system control
test_utils.c | Core test execution logic and routing control
fault_handling.c | Preflight validation and fault detection
nau7802.c | ADC interface and measurement
mux_utils.c | Output selection mux control
adg2128_router.c | Switch matrix definitions (used by test_utils)
bist.c | Built-in self test functionality
firmware_crc.c | Firmware integrity verification

3. Command Interface (UART Protocol)

The firmware communicates using a simple ASCII command protocol.

3.1 Command Format

COMMAND:parameters\n

Example:

PRM:20,10,5
INS:1,2,3
VIP:0b1010,0b0101
TEST

3.2 Supported Commands

Command | Description
PING | Connectivity check
START | Marks beginning of test script
PRM | Define VCC pin, GND pin, voltage
VIN | Define logic thresholds
INS | Define input pins
OUT | Define output pins
VIP | Define input patterns
TEST | Execute test
BIST | Run hardware self-test
FWCRC | Compute firmware checksum

3.3 Command Processing Flow

Inside main.c, commands are parsed and mapped to flags:

- g_run_test
- g_run_bist
- g_start_script
- g_crc_start

Execution occurs in the main loop after parsing .

4. Test Execution Pipeline

4.1 Test Flow

Figure 2. Test Execution Flow

TEST Command →
(if START)
→ ADC Init
→ ADC Calibration
→ Fault Preflight
→ Apply Inputs
→ Generate Clock Events
→ Read Outputs
→ Report Results

4.2 Session Optimization

The firmware uses session caching:

- Expensive operations (ADC calibration, fault checks) run once per script
- VIP changes do NOT trigger recalibration

This significantly improves performance.

5. Hardware Control

5.1 Switch Matrix (ADG2128)

The firmware controls two ADG2128 crosspoint switches to route signals.

Key features:

- Each DUT pin maps to a switch X-line
- Voltage sources map to Y-lines
- Routing performed via I2C

Example mapping logic :

- Pins 1–10 → Chip 1
- Pins 11–20 → Chip 2

5.2 Routing Sources

Source | Description
1.8V – 5V | Voltage rails
STM32 GPIO | Digital driving
GND | Ground reference

Routing is dynamically configured per test step.

5.3 Clock Generation

Clock signals are generated via an STM32 GPIO:

pulse_stm32_source_gpio(low, high, final_low);

Sequence:

1. Drive LOW
2. Drive HIGH
3. Return LOW

Timing is configurable and critical for flip-flop testing.

5.4 Clock Voltage Matching

A mux ensures the clock voltage matches VCC:

- Controlled via GPIO (PB0–PB2)
- Prevents logic-level mismatch

6. Input Pattern Execution

6.1 VIP Input Types

Type | Description
Voltage | Fixed level (e.g., 3.3V)
Binary | Serial pattern (0b1010)
CLK | Clock-driven input

6.2 Serial Pattern Handling

Binary inputs support:

- 0 → LOW
- 1 → HIGH
- R → Rising edge
- F → Falling edge

Example:

0b10RF

This allows precise control of sequential logic.

6.3 Step Execution

Each test step:

1. Apply inputs
2. Execute clock pulse (if needed)
3. Wait for settle
4. Read outputs

7. Output Measurement (ADC)

7.1 ADC Overview

The NAU7802 ADC measures DUT output voltages.

7.2 Calibration Process

Performed once per session:

1. Route GND to calibration pin
2. Take multiple samples
3. Compute offset
4. Store correction value

Example output:

ADC calibration raw=54 mV, offset=54 mV

7.3 Measurement Process

For each output:

1. Select via mux
2. Allow settling
3. Take multiple samples
4. Use median value
5. Apply calibration offset

7.4 Logic Determination

Condition | Result
≤ LOW threshold | 0
≥ HIGH threshold | 1
Between thresholds | Invalid
Mid-range (~1.6V) | High-Z

8. Fault Handling & Preflight

8.1 Purpose

Preflight ensures:

- IC is inserted correctly
- No shorts or floating pins
- Hardware is functioning

8.2 Preflight Steps

1. Clear all routing
2. Apply power (VCC/GND)
3. Drive all inputs LOW
4. Measure outputs
5. Drive all inputs HIGH
6. Measure outputs again
7. Detect anomalies

8.3 Controlled vs Passive Modes

- Passive scan used for certain IC types
- Avoids driving outputs incorrectly

8.4 Failure Handling

If fault detected:

- Test is aborted
- Error reported via UART

9. Built-In Self Test (BIST)

The BIST verifies hardware integrity:

- Switch matrix functionality
- Voltage routing
- ADC behavior

Triggered by:

BIST

After BIST:

- Test session is invalidated

10. Firmware Checksum (CRC)

10.1 Purpose

Ensures firmware integrity and correct deployment.

10.2 Implementation

Triggered via:

FWCRC

Returns:

FW CRC32=0xXXXXXXXX

Computed over firmware memory using CRC32.

11. Performance Considerations

Key optimizations:

- Session caching (avoids repeated calibration)
- Median filtering for ADC
- Selective routing updates (no redundant switching)
- Asynchronous UART handling

12. Limitations & Future Work

Current Limitations

- Limited voltage levels
- Fixed ADC sampling strategy
- No adaptive timing for different ICs

Potential Improvements

- Dynamic timing adjustment
- Expanded voltage support
- Faster ADC sampling
- Enhanced fault diagnostics
- Parallel test execution

13. Conclusion

The STM32 firmware provides a robust and flexible platform for automated IC testing. Its modular architecture enables:

- Reliable hardware control
- Accurate measurement
- Efficient test execution
- Strong integration with GUI software

The system is designed to closely resemble real production test environments, improving usability for technicians and ensuring high-quality validation of digital ICs.

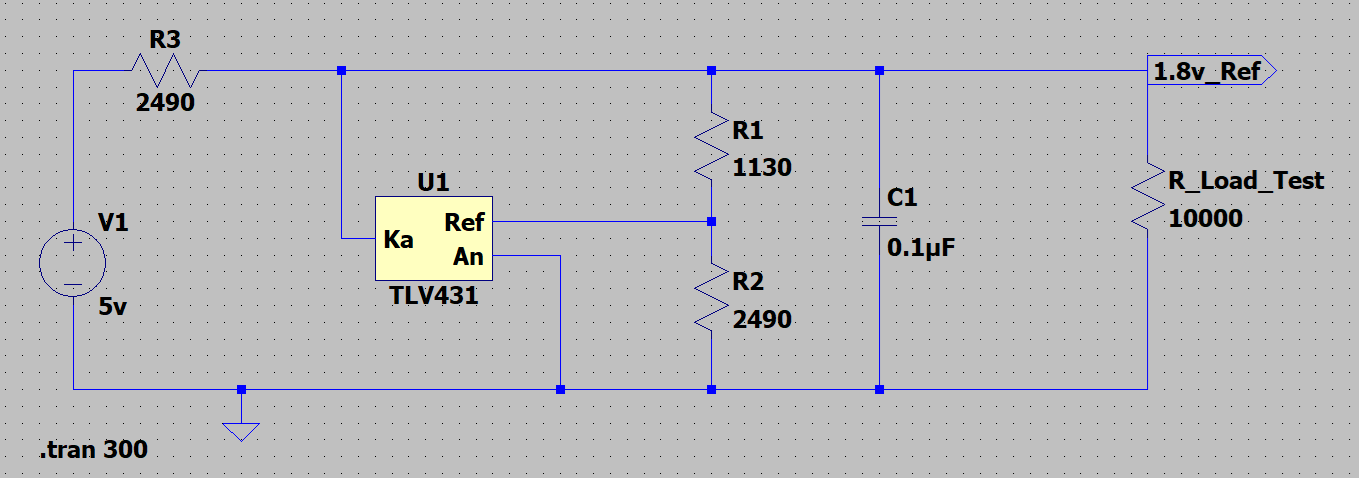
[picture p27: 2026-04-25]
docs/images/hardware_images/spice_images/1_8v_TLV431_E192.png

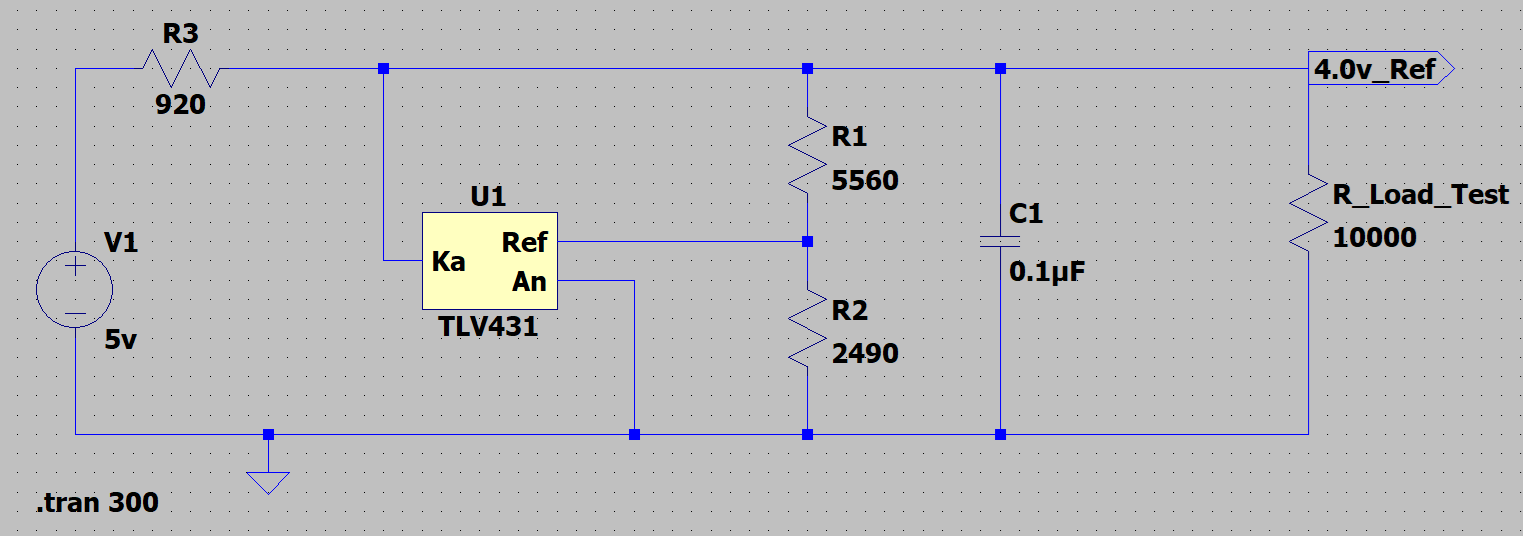
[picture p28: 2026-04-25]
docs/images/hardware_images/spice_images/4_0v_TLV431_E192.png

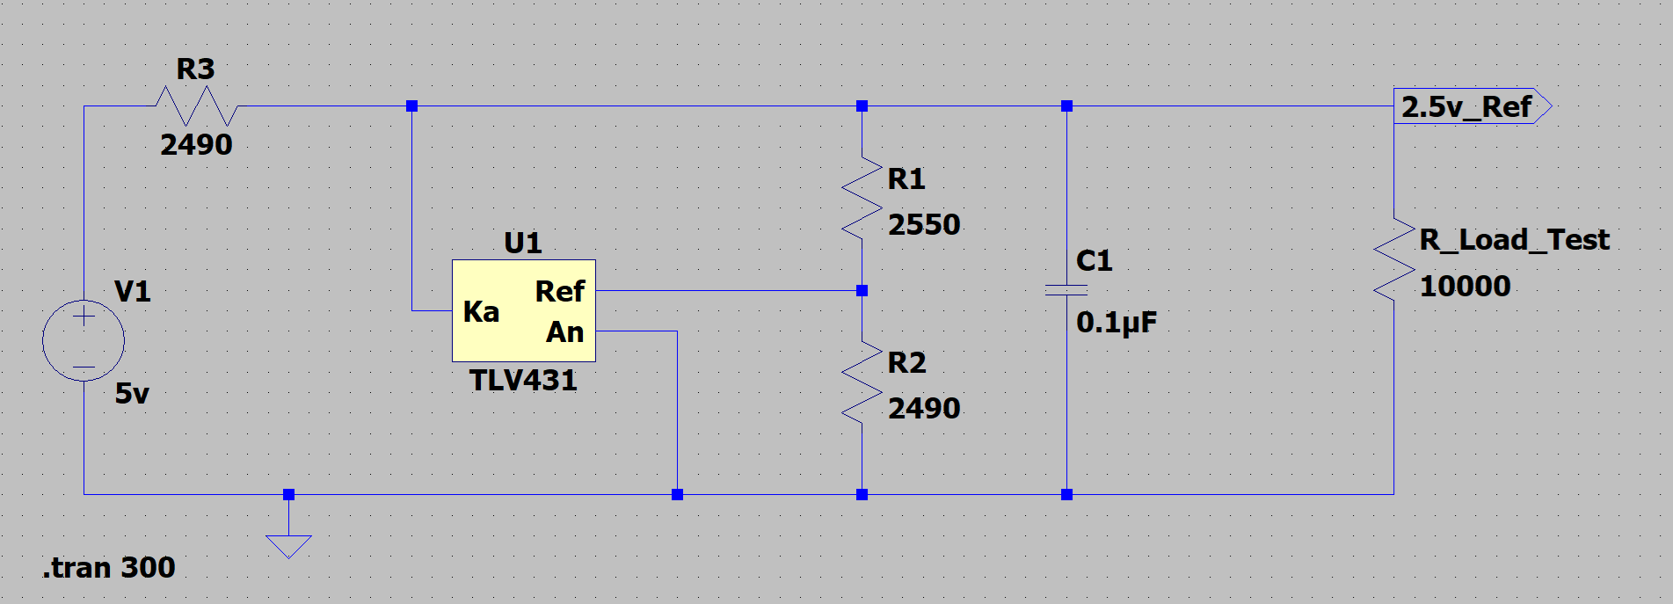
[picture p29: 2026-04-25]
docs/images/hardware_images/spice_images/2_5v_TLV431_E192.png

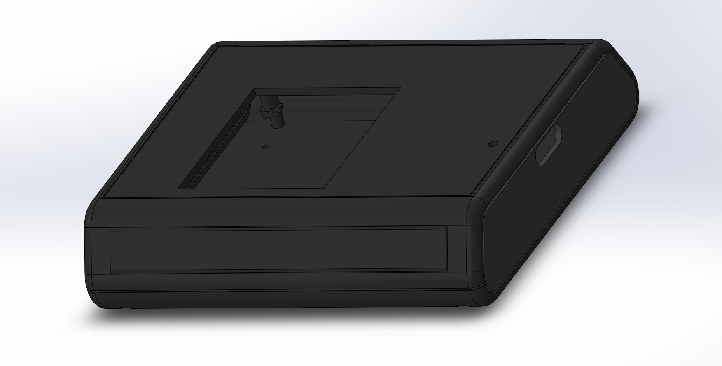
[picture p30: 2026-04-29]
docs/images/hardware_images/chassis_model_empty.png

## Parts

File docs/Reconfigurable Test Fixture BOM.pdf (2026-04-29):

Value | Part Number | DigiKey Number | Manufacturer | Designator | Quantity
CAP CER 15000 pF | 885342208013 | 732-12124-1-ND | Wurth Electronik | C1, C4 | 1
CAP CER 22 uF | GRM32ER71E226ME15L | 490-10758-1-ND | Murata | C2 | 2
CAP CER 10 uF | GRM32ER71H106MA12L (CL32B106KBJNNNE) | 1276-3387-1-ND | Samsung | C3 | 1
CAP CER 2.2 uF | GCM31CL8EL225KE07L | 490-GCM31CL8EL225KE07LCT-ND | Murata | C5, C6 | 2
CAP CER 0.1 uF | GCM31C5C1H104FA16L | 490-GCM31C5C1H104FA16LCT-ND | Murata | C7, C8, C11, C19, C21 | 5
CAP CER 10000 pF | GRM31B7U2E103JW31L | 490-6502-1-ND | Murata | C9 | 1
CAP CER 4.7 uF | GRM21BR71A475KE51L | 490-GRM21BR71A475KE51LCT-ND | Murata | C10 | 1
CAP CER 0.1 uF | VJ1206Y104KXXAC | 720-VJ1206Y104KXXACCT-ND | Vishay Vitrmon | C12, C13, C14, C15, C16 | 5
CAP CER 15 pF | GRM31A5C2H150JW01D | 490-14667-1-ND | Murata | C17, C18 | 2
CAP CER 0.1 F | C1206X104G4HAC7800 (C1206X104G4HACTU) | 399-C1206X104G4HACTUCT-ND | KEMET | C20, C22, C23, C24, C26, C27, C29, C31, C34, C35, C37, C39, C40, C41, C42, C43, C44, C45, C46, C47, C48, C49 | 22
CAP CER 10 uF | GCM31CM8EG106KE08L | 490-GCM31CM8EG106KE08LCT-ND | Murata | C25, C28, C30, C32, C33, C36 | 6
CAP CER 2.2 uF | CC1206ZRY5V8BB225 | 311-3464-1-ND | Yageo | C38 | 1
TVS Diode 5.5 V | TPD1E10B06DPYR | 296-30406-1-ND | TI | D1, D2 | 2
TVS SOID123FL 5 V | SMF5.0A | F5748CT-ND | Littlefuse | D3, D4 | 2
TVS Diode 5.25 V | USBLC6-4SC6 | 497-4492-1-ND | STMicroelectronics | D5 | 1
Green LED, 20mA | 304090040 | N/A | Seeed Studio | DS1 | 1
PTC Reset Fuse 13.2 V | MICROSMD050F-2 | MICROSMD050F-2CT-ND | Littlefuse | F1 | 1
5V-5V DC Isolator | UCC33420QRAQRQ1 | 296-UCC33420QRAQRQ1TR-ND | TI | IC1 | 1
USB-C 2.0 CON | USB4105GFA060 | 2073-USB4105-GF-A-060CT-ND | GCT | J1 | 1
5-pin CON Header | S5B-XH-A-1(LF)(SN) | 455-4228-ND | JST | J2 | 1
20(2x10) ZIF Socket | 220-3342-00-0602J | 3M2002-ND | 3M | J3 | 1
RES 1 K ohm 1% | RC1206FR-101KL | 13-RC1206FR-101KLCT-ND | Yageo | R1 | 1
RES 5.1 K ohm 0.1% | RP1206BRD075K1L | 13-RP1206BRD075K1LCT-ND | Yageo | R2, R3 | 2
RES 920 ohm | RN73R1JTTD9200B25 | 2019-RN73R1JTTD9200B25CT-ND | KOA Spear | R4 | 1
RES 1.69 K ohm 0.1% | RQ73C2B1K69BTD | 2019-RN73R2ATTD5561B25CT-ND | TE Connectivity | R5 | 1
RES 442 ohm 0.1% | RT1206BRD07442RL | 13-RT1206BRD07442RLCT-ND | Yageo | R6 | 1
RES 5.56 K ohm 0.1% | RN73R2ATTD5561B25 | 2019-RN73R2ATTD5561B25CT-ND | KOA Spear | R7 | 1
RES 2.49 K ohm 1% | KTR18EZPF2491 (RMCF1206FT2K49CT) | RMCF1206FT2K49CT-ND | ROHM | R8, R12, R13, R14, R15, R16, R18 | 7
RES Thick Film 57.6 K ohm 1% | CRCW120657K6FKEA | 541-57.6KFCT-ND | Vishay Dale | R9 | 1
RES 4.17 K ohm 0.1% | RN73R1JTTD4171B25 (RN73H1JTTD4171F100) | 2019-RN73H1JTTD4171F100CT-ND | KOA Spear | R10 | 1
RES 2.55 K ohm 0.1% | RT1206BRD072K55L | YAG5059CT-ND | Yageo | R11 | 1
RES 1.13 K ohm 1% | RK73H2BTTD1131F | 2019-RK73H2BTTD1131FCT-ND | | R17 | 1
RES 5 K ohm 0.1% | RT1206BRD075KL | YAG5090CT-ND | Yageo | R19 | 1
RES 10 K ohm 0.1% | RP1206BRD0710KL | 13-RP1206BRD0710KLCT-ND | Yageo | R20, R23 | 2
RES 2.2 K ohm 1% | RK73H2ETTD2201F | 2019-RK73H2ETTD2201FCT-ND | KOA Spear | R21, R22, R24, R25 | 4
RES 125 ohm 0.1% | RT1206BRD07125RL | 13-RT1206BRD07125RLCT-ND | Yageo | R26 | 1
RES 10 K ohm 0.1% | TNPW120610K0BETY | 541-3924-1-ND | Vishay Dale | R27, R28, R30 | 3
RES 20 K ohm 0.1% | TNPW120620K0BYEN | 541-4422-1-ND | Vishay Dale | R29 | 1
RES 4.7 K ohm 0.1% | TNPW12064K70BEEA | 541-3881-1-ND | Vishay Dale | R31, R32 | 2

### Bill of Materials - Electrical

Value | Part Number | DigiKey Number | Manufacturer | Designator | Quantity
RES 100 K ohm 0.1% | TNPW1206100KBEEA | TNP100KACCT-ND | Vishay Dale | R33, R34 | 2
USB Digital Isolator | ADUM4160BRWZ | 505-ADUM4160BRWZ-ND | Analog Devices | U1 | 1
IC REG Linear 3.3 V | TPS7A2033PDBVR | 296-TPS7A2033PDBVRCT-ND | TI | U2 | 1
CP2102 TH, female USB-C | CP2102-GM | 336-1160-5-ND | Silicon Labs | U3 | 1
TLV431 (1.24 V reference) | TLV431ALPG | TLV431ALPGOS-ND | onsemi | U4, U5, U6, U7, U8 | 5
64-pin 48 MHz | STM32C071RBT6 | 497-STM32C071RBT6-ND | STMicroelectronics | U9 | 1
8:1 Multiplexer | ADG708BRUZ-REEL | ADG708BRUZ-REELCT-ND | Analog Devices | U10, U15, U18, U20 | 4
IC CROSSPOINT SWITCH 8X12 32LFCSP | ADG2128BCPZ-REEL7 | 505-ADG2128BCPZ-REEL7CT-ND | Analog Devices | U12, U13 | 2
2W ISO DC-DC Converter | DCP020509P | DCP020509P-ND | TI | U14 | 1
4:1 Multiplexer | ADG709BRUZ-REEL | ADG709BRUZ-REELCT-ND | Analog Devices | U16 | 1
IC ADC 24bit Sigma-Delta 16DIP | NAU7802KGI-ND | NAU7802KGI-ND | Nuvoton | U17 | 1
24 MHz XTAL 10-1-U-T | ABM3B-24.000MHZ-10-1-U-T | 300-8216-1-ND | STMicroelectronics | Y1 | 1
ST-LINK STM Flasher | ST-LINK/V2 | 511-ST-LINK/V2 | Chip Quick | N/A | 1

Name | Part # | Manufacturer Number | Manufacturer | Designator | Quantity
ABS Enclosure 2-Panels | JB-65T*0000 | JB-65T*0000 | Polycase | 1, 2, 3, 4, 5 | 1
Hex Standoff #4-40 1” | 101604HFA | 4753-101604HFA-ND | Kanebridge | 6 | 4
Mach Screw Pan #4-40 | R4-40X1/4 2701 | 335-1082-ND | APM Hexseal | 7 | 8
Bumper Cylindrical 0.5” | SJ-5012 (BLACK) | SJ5012-0-ND | 3M | 8 | 4

## Bill of Materials - Chassis

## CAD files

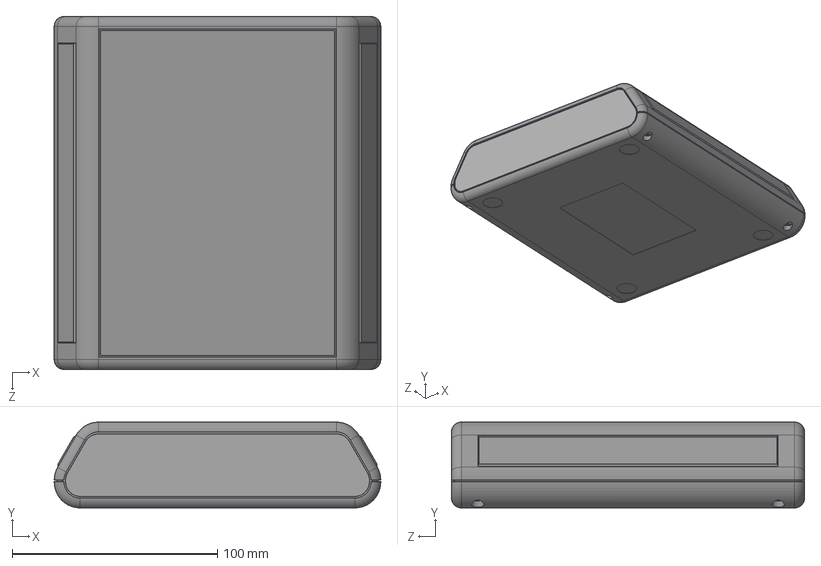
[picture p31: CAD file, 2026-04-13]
hardware/chassis/JB-65T ASSEMBLY.STEP
159.0 x 41.8 x 171.9 mm
SCREWS-HL5~8-BR x 4
JB-65EP_JB-65EP*00 x 2
JB-65B_JB-65B*00
JB-65C_JB-65TC*00

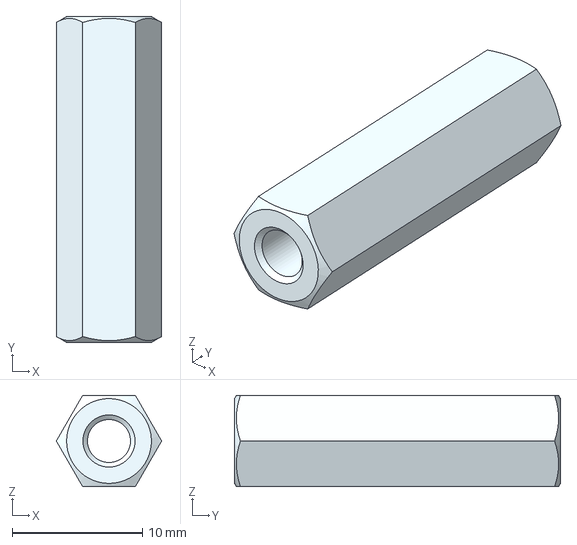
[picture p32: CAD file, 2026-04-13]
hardware/chassis/Abstandzbolzen Stahl verzinkt I-I M4_-_Ettinger - 5.04.251 (M4x25).stp
8.08 x 25.0 x 7.00 mm

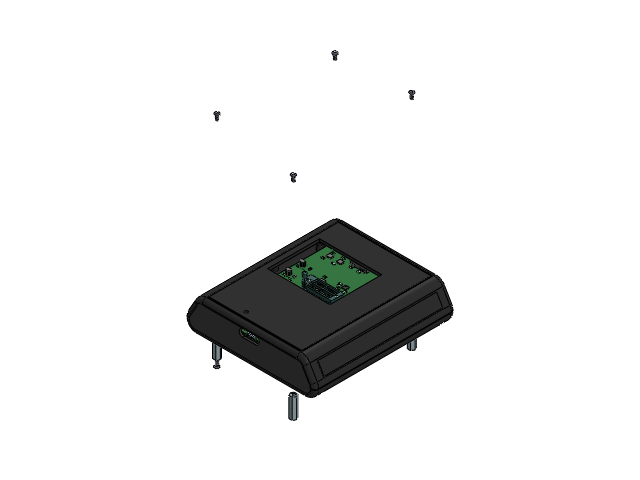
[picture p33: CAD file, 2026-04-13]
hardware/chassis/JB-65T ASSEMBLY_With_PCB.SLDASM
SCREWS-HL5~8-BR x 4
JB-65EP_JB-65EP_00 x 2
JB-65B_JB-65B_00
JB-65C_JB-65TC_00
PCB_3d
Abstandzbolzen Stahl verzinkt I-I M4_-_Ettinger - 5.04.251 (M4x25) x 4
msc-93036580 x 8

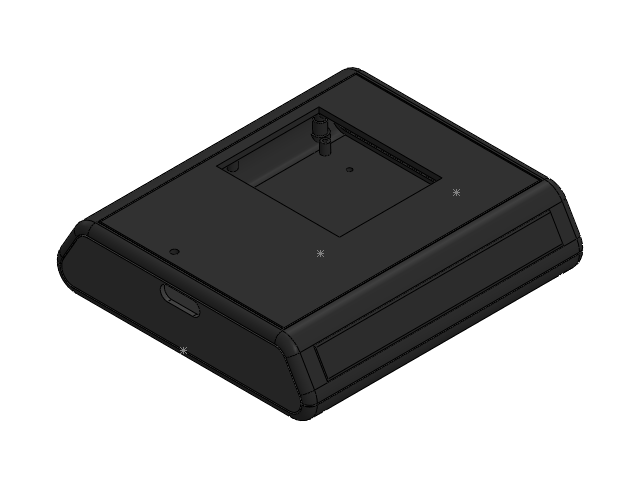
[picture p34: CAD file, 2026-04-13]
hardware/chassis/JB-65T ASSEMBLY_with_cuts.SLDASM
SCREWS-HL5~8-BR x 4
JB-65EP_JB-65EP_00 x 2
JB-65B_JB-65B_00
JB-65C_JB-65TC_00

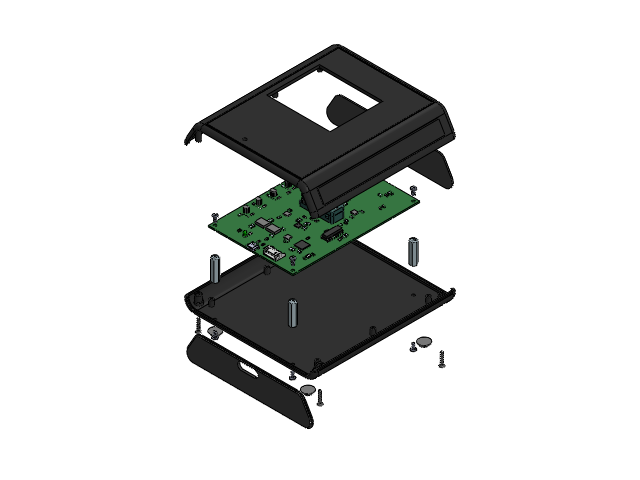
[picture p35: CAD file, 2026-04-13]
hardware/chassis/JB-65T ASSEMBLY_With_PCB_floating_assembly_view.SLDASM
SCREWS-HL5~8-BR x 4
JB-65EP_JB-65EP_00 x 2
JB-65B_JB-65B_00
JB-65C_JB-65TC_00
PCB_3d
Abstandzbolzen Stahl verzinkt I-I M4_-_Ettinger - 5.04.251 (M4x25) x 4
msc-93036580 x 8
BS01R x 4

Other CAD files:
hardware/chassis/JB-65EP_JB-65EP_00.SLDPRT
hardware/chassis/JB-65B_JB-65B_00.SLDPRT
hardware/chassis/JB-65C_JB-65TC_00.SLDPRT
hardware/chassis/PCB_3d.SLDPRT
hardware/chassis/SCREWS-HL5~8-BR.SLDPRT
hardware/chassis/JB-65T ASSEMBLY_with_cuts_bottom.SLDDRW
hardware/chassis/JB-65T ASSEMBLY_with_cuts_front_rear.SLDDRW
hardware/chassis/JB-65T ASSEMBLY_with_cuts_full.SLDDRW
hardware/chassis/JB-65T ASSEMBLY_with_cuts_top.SLDDRW

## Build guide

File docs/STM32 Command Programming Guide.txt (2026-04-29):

General Command Format

All commands are ASCII strings of the form:

CMD:arg1,arg2,arg3,...

CMD is an uppercase command identifier

: separates the command from its parameters

Parameters are comma-separated

No spaces are required

Pin numbers range from 1–20 

Each command is sent independently; command order matters for interpretation.

Supported Commands
----------------------------------------------------------------------------------

INS — Define Input Pins

Defines the ordered list of input pins for the IC under test.

Format

    INS:p1,p2,p3,...

Example

    INS:1,3,5,7

Pins must be integers in the range 1–20

Order matters and is preserved internally
-----------------------------------------------------------------------------

OUT — Define Output Pins

Defines the ordered list of output pins for the IC under test.

Format

    OUT:p1,p2,p3,...

Example

    OUT:2,4,6

Pins must be integers in the range 1–20

Order matters and is preserved internally
------------------------------------------------------------------------

VIN — Define ADC Voltage High/Low Limits

Defines the high/low limits for ADC. Needed for logic decisions

Format

    VIN:low,high

Example

    VIN:0.80,2.00

Values are sent as decimal volts

Firmware internally converts and stores values in millivolts

low < high is expected

-------------------------------------------------------------------------------------

PRM — Power Pin Parameters

Defines which pins on the IC correspond to VCC and GND, and states VCC voltage

Format

    PRM:VCCpin,GNDpin,VCCvoltage

Example

    PRM:14,7,3.3

VCCpin and GNDpin are integer pin numbers, VCCvoltage is float

Order matters: first is VCCpin, second is GNDpin, third is VCCvoltage (GNDvoltage is always 0)

------------------------------------------------------------------------------------

VIP — Input Stimulus per Input Pin (Voltage / Clock / Serial)

Defines the stimulus applied to each input pin, mapped in the same order as INS.
Each VIP index may be one of:
- A voltage (decimal volts), e.g. 3.30
- A clock input in MHz, format CLK, e.g. CLK
- A serial bit pattern, format 0b<binary>, e.g. 0b010101
    - Can specify rising edges, ex 0b0RRFF, where R is rising edge and F is falling edge

Format

    VIP:x1,x2,x3,...

Examples

    VIP:3.30,3.30,CLK,0b0101,0b0R0F

Notes

Token/value count should match the number of pins defined in INS

Voltage values are sent as decimal volts
Firmware internally converts/stores voltages in millivolts

------------------------------------------------------------------------------------

TEST — Start Test Execution

Commences the test after all configuration commands have been sent.

Format

    TEST

No parameters

------------------------------------------------------------------------------------

BIST - Perform a built-in self test

Performs the built-in self test on the test fixture.

Format

    BIST

No parameters

------------------------------------------------------------------------------------

START - Flag to mark the beginning of a test script

Flag to mark the beginning of a test script, so when TEST is passed, perform an ADC calibration and fault handling prior to TEST executing.

Format

    START

No parameters

------------------------------------------------------------------------------------

FWCRC - Initiate checksum 

Initiates the checksum sequence, then sends back checksum string over UART. Expected result "FW CRC32=0x9F0717A7"

Format

    FWCRC

No parameters

------------------------------------------------------------------------------------

PING - "Ping" the fixture

Checks to see if communication can be made between the PC and the fixture. If successful, returns "Device is ready"

Format

    PING

No parameters

------------------------------------------------------------------------------------

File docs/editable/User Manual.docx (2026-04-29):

Reconfigurable Digital Integrated Circuit Test Fixture User Manual

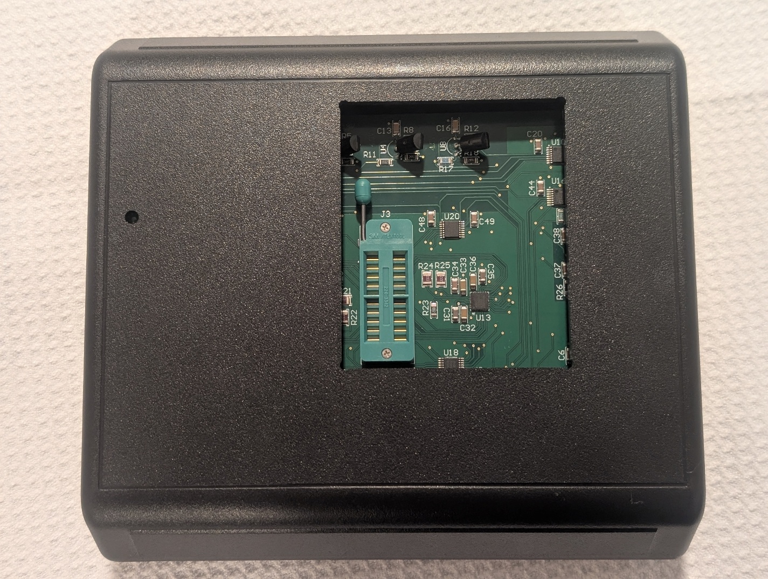
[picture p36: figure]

I. INTRODUCTION

This user manual provides clear instructions for setting up and using the Reconfigurable Digital Integrated Circuit Test Fixture. This project requires the user to fabricate and populate the PCB and build the associated software. The user should have basic experience with electronics and software development tools. This guide covers the required dependencies, building and compiling the project, flashing the STM32, and executing the application to test a digital integrated circuit along with an interpretation of the PDF report generated.

II. PREREQUISITES

This project is distributed as source code and schematics, the hardware must be procured and constructed by the user themselves, and the software must be compiled and flashed.

A. Hardware

Printed Circuit Board Fabrication

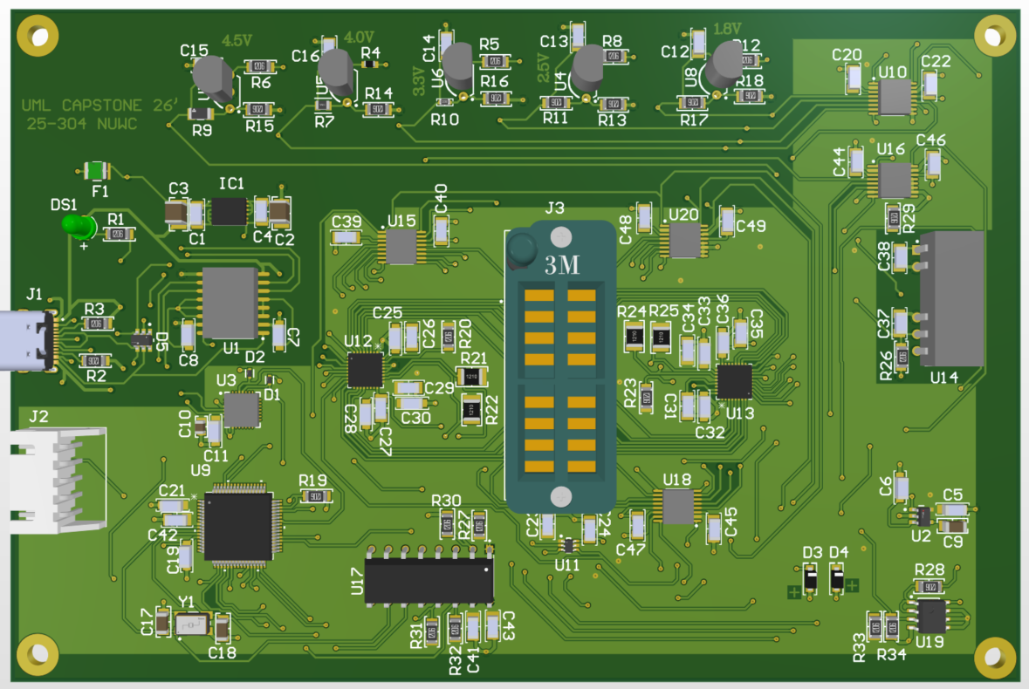
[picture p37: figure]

Figure 1. 3D PCB view of the hardware portion of the test fixture.

The Bill of Materials (BOM) is located in the docs/ folder. The file is an Excel Spreadsheet and can be opened using Microsoft Excel, or Google Sheets,

Gerber and ODB++ files for PCB fabrication can be found in hardware/altium_files. It is recommended to order the PCB with a stencil for easier population. The Engineering Change Order (ECO) is located in docs/. The ECO indicates all changes that have been made to the PCB since the initial fabrication and should be referenced during population.

Chassis

The chassis for the test fixture are located in hardware/chassis. This folder includes all the SolidWorks design files used to fabricate the chassis from the original PolyCase.

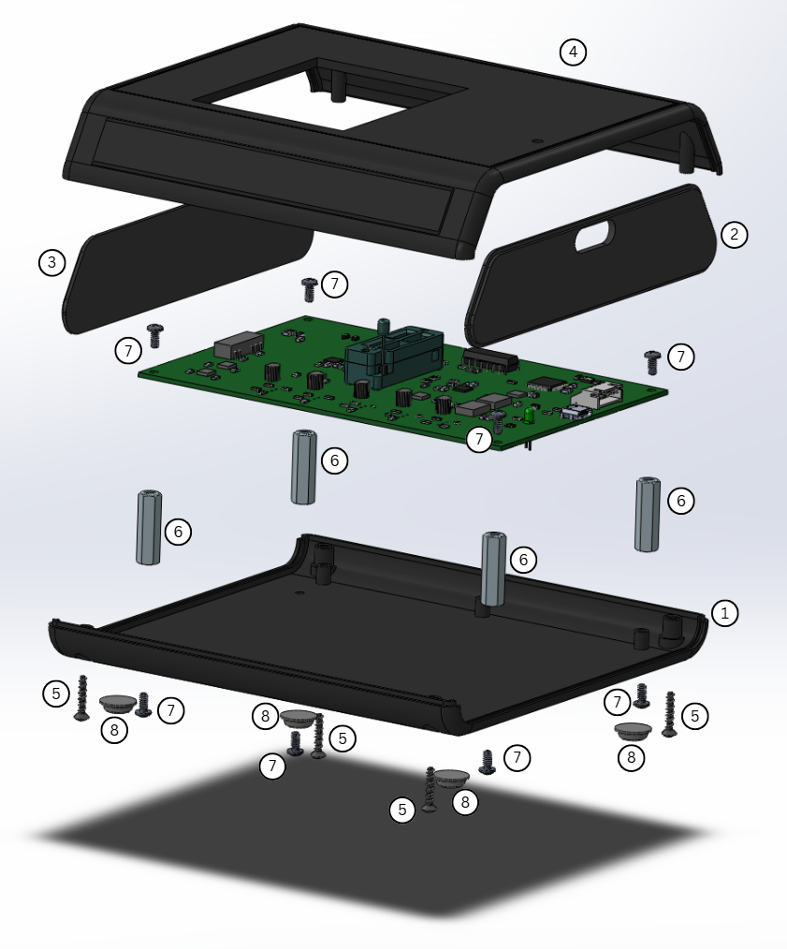
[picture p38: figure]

Figure 2. 3D Chassis scatter view of the IC Test Fixture.

Figure 10 showcases the assembly component view of all parts required to assemble the chassis of the reconfigurable test fixture and set the PCB properly inside. The chassis comes with on bottom chassis (1), a front panel with cutout (2), rear panel (3), and upper chassis with cutouts (4). These can be taken apart and secured together with a snap fit assembly for the panels and secured in place with the included chassis screws x4 (5). Four adhesive rubber feet (8) are attached onto indent holes on the bottom of the chassis. These provide a non-slip grip to a flat surface and prevent the chassis from moving around and damaging surfaces. Four 1” hex standoffs (6) are used to hold up the PCB and can be secured into place using four #4-40 screws (7). It is best practice to secure the hex standoffs in place first by screwing them in place from the bottom of the chassis. Then mount the PCB on top with the USB-C port facing towards the front panel side, then secure the PCB in place with the remaining four #4-40 screws (7). Finally, the front (2) and rear (3) panels can be placed into the indentation marks of the bottom chassis, and the upper chassis (4) can be placed on to, with the LED hole aligned with the PCB LED. The chassis can be secured together using the four included chassis screws (5).

Drivers

The circuit uses a CP2102 USB to UART bridge for communication. The firmware for the CP2102 requires a driver provided by Silicon Labs which can be downloaded from https://www.silabs.com/interface/usb bridges/classic/device.cp2102?tab=softwareandtools (https://www.silabs.com/interface/usb%20bridges/classic/device.cp2102?tab=softwareandtools). The application finds the test fixture dynamically by the CP2102’s serial number which is flashed using another software provided by Silicon Labs which can be downloaded from same link and is called “AN721: CP210x/CP211x Device Customization Guide.” The serial number must be programmed to 554D4C2043617073746F6E652032352D333034204E5557432032303236.

A USB C 2.0 cable is also required for communication with the test fixture.

B. Software

The software application is programmed in Python. The user must have their own Python interpreter that is at least version 3.10 or greater. The current software was built and tested using Python 3.14.3. A Python interpreter can be installed from https://www.python.org/downloads/. To create a Python virtual environment, follow the terminal commands displayed in Figure 2.

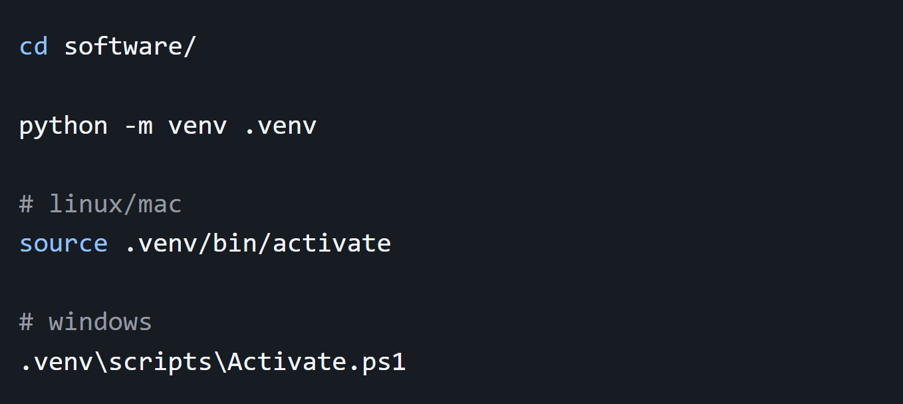
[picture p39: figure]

Figure 3. Terminal commands for creating Python virtual environment.

To install the project dependencies, either command in Figure 3 can be used. It is recommended to install the developer dependencies if it is desired to modify the source code.

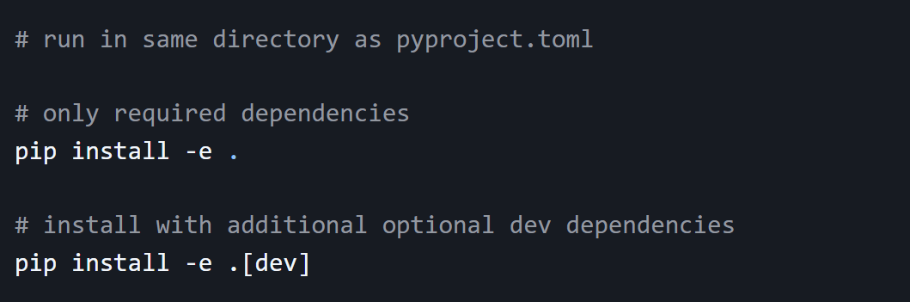
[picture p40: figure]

Figure 4. Terminal commands for installing Python package dependencies.

This program can be compiled using the provided scripts in software/build to build an executable for Windows, Mac, or Linux, or installed as a package. To build an executable, commands shown in Figure 4 can be used.

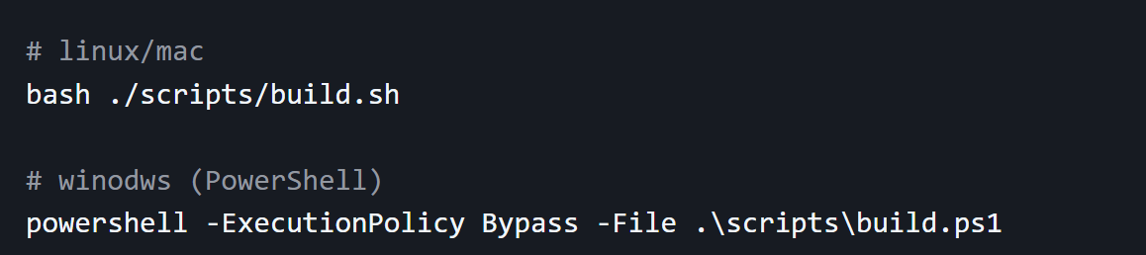
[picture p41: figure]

Figure 5. Terminal commands for building an executable of the application.

If an executable is not desired, or the user is working in a development environment, the software can be executed using the commands in Figure 5.

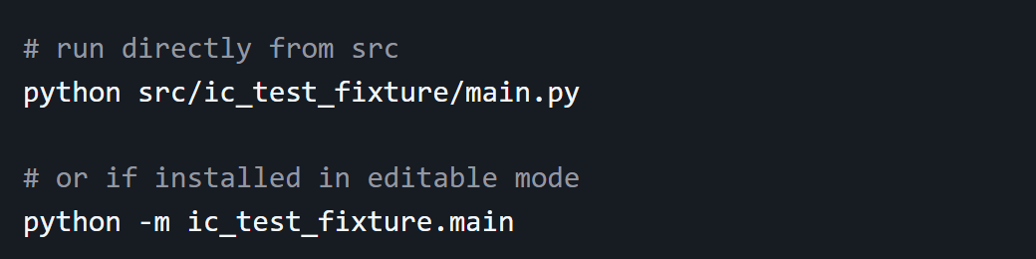
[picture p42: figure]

Figure 6. Terminal commands for executing the application.

C. Firmware

The firmware is programmed in C and must be flashed to the STM32 on the PCB using an ST-Link debugger/programmer. All related firmware is located in firmware/. The PCB has a 5-pin header (J2), located at the bottom right as seen in Figure 1. See Figure 7 for proper connections between the ST-Link and header, jumper wires or a proper link may be used.

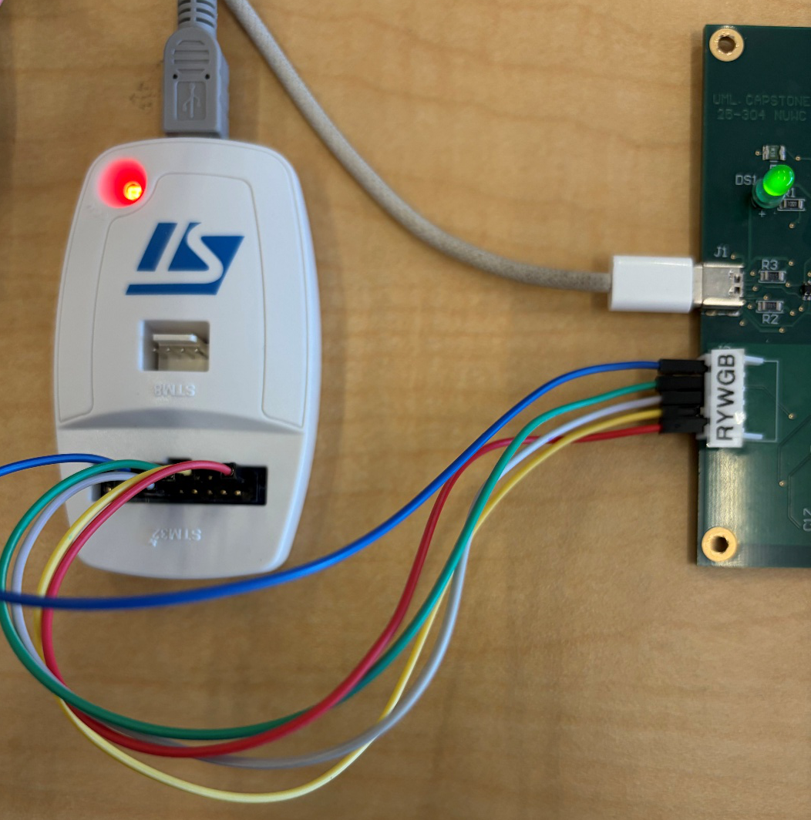
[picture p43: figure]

Figure 7. Jumper wire connections between the ST-Link and 5-pin header for flashing.

To build and flash the firmware, the following directions must be followed:

1. Open STM32CubeIDE
2. File -> Open Projects from File System
3. Import the project from firmware/STM32_main
4. Project -> Build Project
5. Connect ST-Link to PCB (shown in Figure 6)
6. Power the board via USB-C 2.0 cable
7. Run → Debug (or Run)

III. IC Test Fixture Application

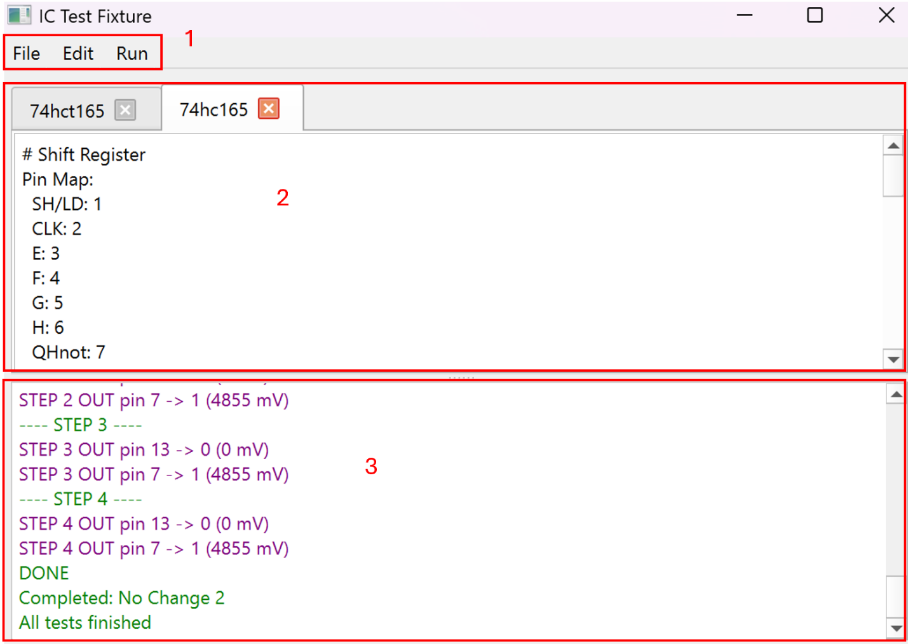
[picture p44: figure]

Figure 8. Labeled image of the main window of the application.

The IC Test Fixture application is a graphical-user interface, allowing the user to control the test fixture. The main window of the application has three primary features shown in Figure 8, the menu bar (1), the text editor (2), and the status display (3).

The menu bar includes the menus File, Edit, and Run. The File menu offers the user the ability to make a new test script, open an existing test script, and save a test script. The Edit menu contains standard text-editing features undo, redo, cut, copy, and paste. The Run menu contains a button Run, and BIST. The Run button is used for executing a test script, and BIST is used to execute the Built-In Self Test feature of the hardware.

The text editor has support for tabs. The tabs allow the user to swap between multiple opened test scripts to streamline the process of testing multiple digital integrated circuits (ICs). All editing and test script executing features are tied to the current tab in focus. The text editor only supports plaintext.

The status display displays all commands sent and received by the hardware. The status display is color-coded to easily identify the types of status messages. See Table 1 for what each color stands for. The status display acts as a pseudo-log for debugging purposes if the application is used in a development environment.

Table 1. The table displays the meaning of each color of text in the status display.

Color | Command Type
Blue | Commands sent to the test fixture.
Red | Errors with the test script or received from the test fixture.
Green | Miscellaneous status messages regarding current progress.
Purple | Measurements received from the test fixture, indicating the measured voltage and logic based on the given thresholds.

IV. YAML Test Scripts

The primary method for a user to control the test fixture is using YAML test scripts. For an in-depth guide on YAML test scripts, refer to the document “YAML Test Script Documentation” located in the docs/ folder. The test scripts allow the user to set the supply voltage for the IC (VCC), and dictate which pins to drive with a digital logic signal, and which pins to measure. The test scripts support both high-level abstraction for readability, and low-level logic for simplicity. It is recommended to use high-level abstraction for ICs with complex logic. There are five sections to the test script, Chip Info, Pin Map, Truth Table, Global Parameters, and Tests. The first three sections are optional; Global Parameters and Tests are required.

Chip Info

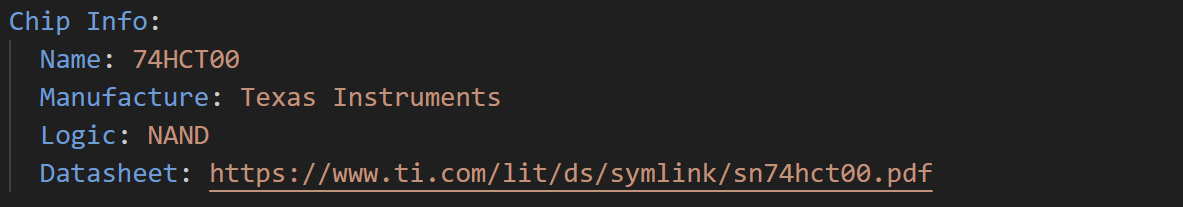
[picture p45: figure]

Figure 9. Example Chip Info section for 74HCT00 IC.

The Chip Info section allows the user to input any additional information regarding the IC if desired. There are no restrictions to this section and none of the information written will interfere with the testing of the chip. All the information will be displayed in the PDF report in a tabular format. This section is ideal if the PDF report is intended to be passed onto someone else who may want additional information. An example is shown in Figure 9.

Pin Map

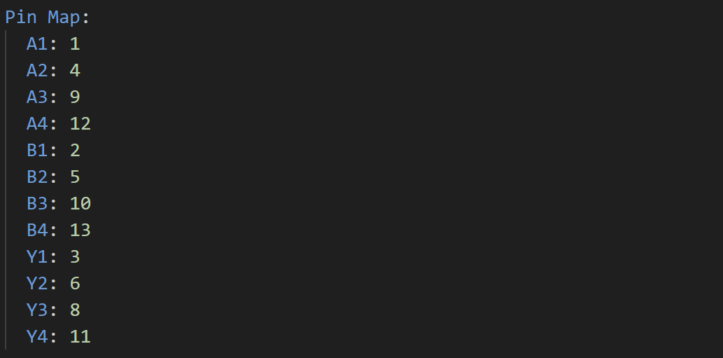
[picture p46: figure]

Figure 10. Example Pin Map Section for 74HCT00 IC.

The Pin Map section allows the user to abstract the pin numbers of the socket to the actual pin names of the IC. These abstractions can then be used in the Tests section of the test script to enhance readability for both the test script and generated PDF report. This section is recommended for ICs with high pin counts. An example is shown in Figure 10.

Truth Table

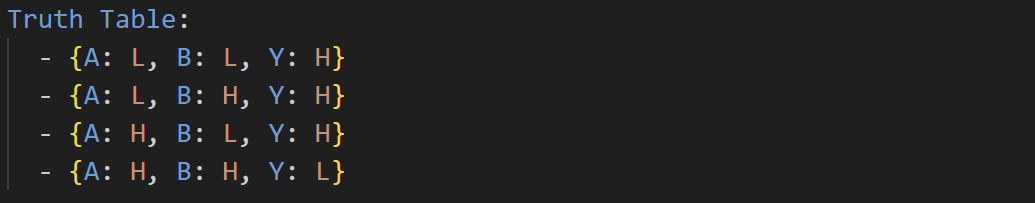
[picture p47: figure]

Figure 11. Example Truth Table section for 74HCT00 IC

The Truth Table section allows the user to write a truth table like data structure inside the test script. The name of a column of the Truth Table can later be used in the Tests sections to abstract the logic signal to drive a pin. This section is useful for logic devices that have multiple independent logic circuits. Each logic circuit can then be tested and presented separately in the generated PDF report. An example is shown in Figure 11.

Global Parameters

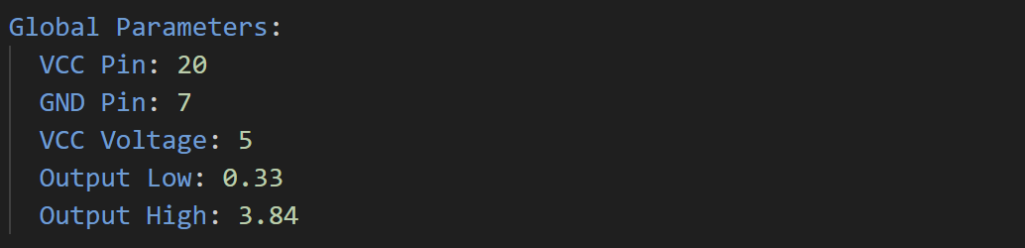
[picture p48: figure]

Figure 12. Example Global Parameters section for 74HCT00 IC.

The Global Parameters section lists all the parameters that will be used for every test. VCC Pin and GND Pin represent the voltage supply pin and ground pin of the IC respectively. VCC Voltage is the voltage level to power the IC, and the default logic HIGH voltage during testing. The parameters Output Low and Output High are the logic thresholds used to determine if the output voltage is HIGH, LOW, or undefined. An example is shown in Figure 12.

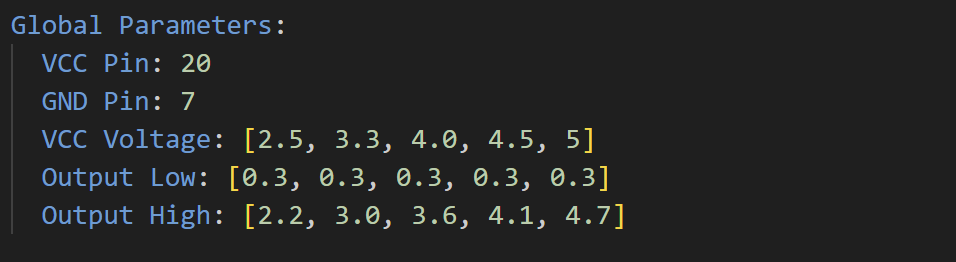
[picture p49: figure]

Figure 13. Example Global Parameters section for 74HC00 IC.

To streamline the process of testing logic devices capable of operating at different voltage levels such as the 7400-series HC devices, square brackets can be used to create list of voltage levels and thresholds. These lists must be the same length. The voltage levels and thresholds located at the same index correspond to each other during testing, that is, the first VCC Voltage will have thresholds at the first Output Low and Output High values. An example is shown in Figure 13.

The voltage levels the IC test fixture can support are 1.8V, 2.5V, 3.3V, 4.0V, 4.5V, and 5.0V.

Tests

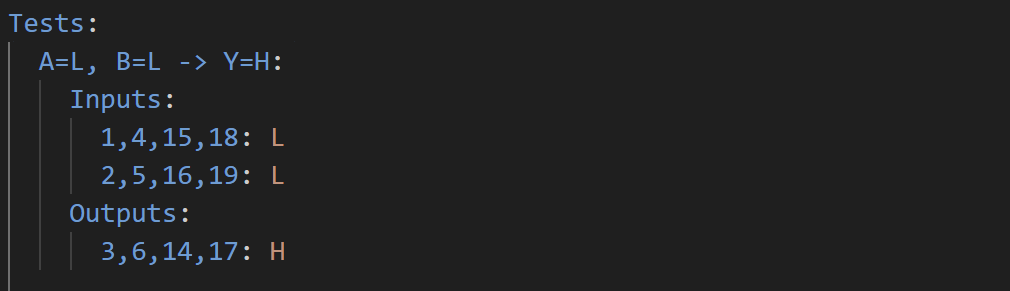
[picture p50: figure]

Figure 14. Example of a test for 74HCT00 IC.

The Tests section is where the user will be able to write commands to drive the input pins of the IC and measure the output pins. Pins can be logically grouped together by separating pins with a comma. In Figure 14, the “A” input pins 1, 4, 15, and 18, and “B” input pins 2, 5, 16, and 19, are driven with a logic LOW. The “Y” output pins 3, 6, 14, and 17 are expected to be a logic HIGH.

Figure 15. Example of test for 74HCT00 IC using abstractions.

If the Pin Map or Truth Table section were included in the test script, the pin numbers and logic symbols can be abstracted for actual names of the pins for the IC, and the column name of a truth table. In Figure 15, the pin A1, B1, and Y1 represent the pins 1, 2, and 3 as shown in Figure 10. The values to drive and measure the pins with are based on the NAND gate truth table shown in Figure 11.

The supported logic symbols for the Inputs subsection for the Tests section are L, H, X, R, and F. These stand for logic LOW, logic HIGH, don’t care (default too LOW), rising edge, and falling edge. For Outputs, the supported logic symbols are L, H, X, Z. Z stands for high-impedance (Hi-Z).

V. Testing Integrated Circuits

Test Procedure

To test an IC, follow the listed steps below:

1. Power the circuit using a USB-C 2.0 cable. The LED should light up.
2. Push up on the lever arm on the socket, so that it is vertical (Figure 16).

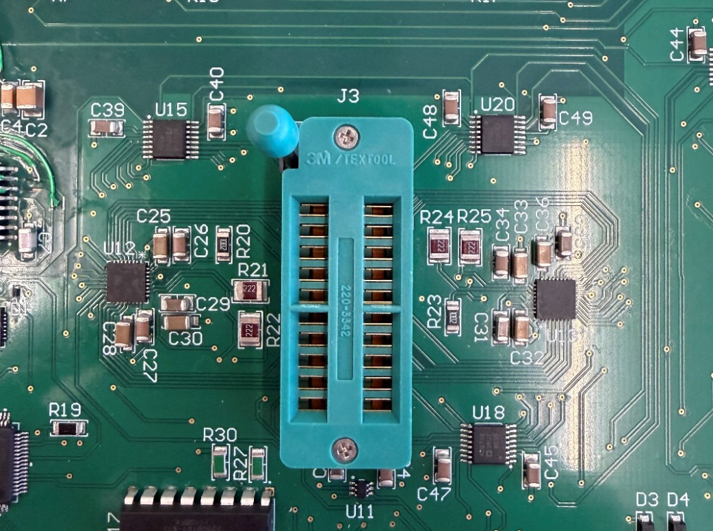
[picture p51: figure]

Figure 16. Demonstration of what the socket should look like after step 2.

3. Insert the IC and push down on the lever arm up so its horizontal. (Figure 17).

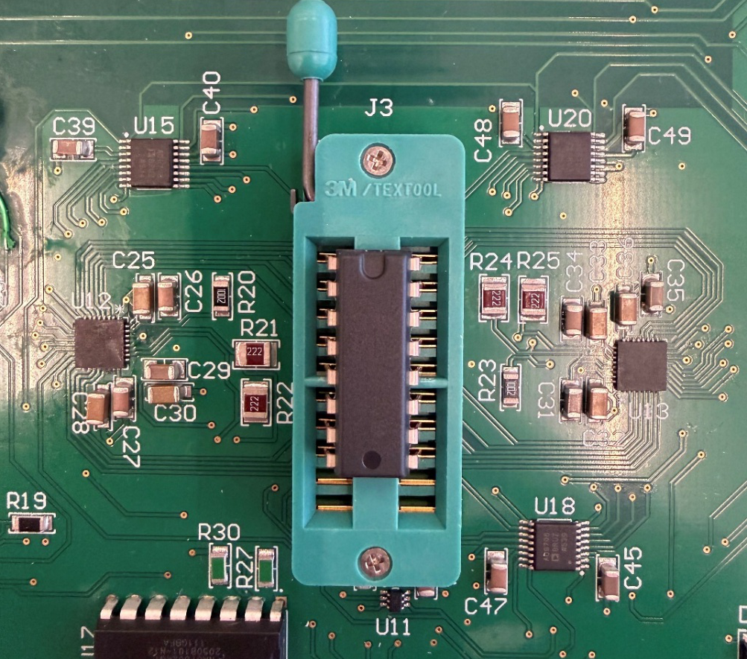
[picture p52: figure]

Figure 17. Demonstration of what the socket looks like after step 3.

4. In the application, open a test script for the IC
5. Run -> Run to execute the test script. DO NOT ATTEMPT TO REMOVE THE IC DURING TESTING.
6. Save the PDF report into the desired location.
7. Pull up on the lever arm and remove the IC.

Interpretation of Results

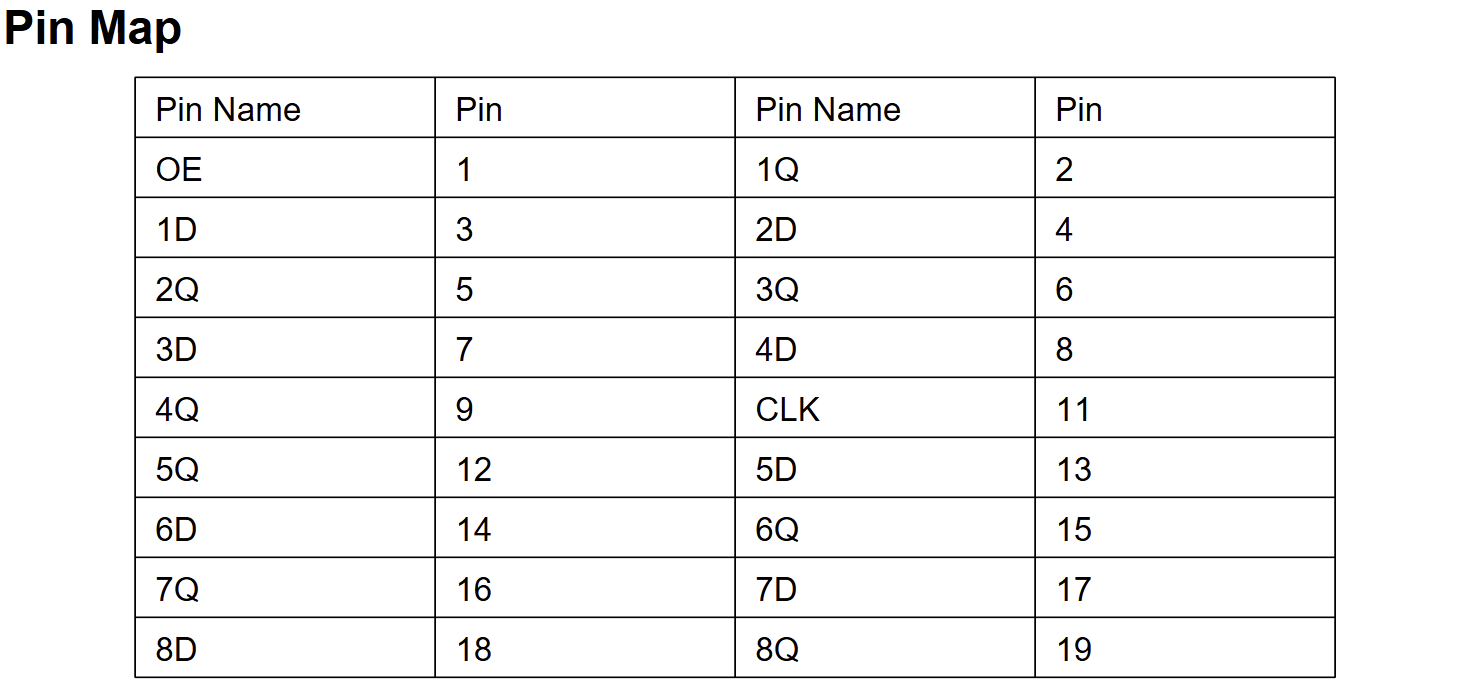
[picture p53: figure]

Figure 18. Pin Map of the Digital IC under test.

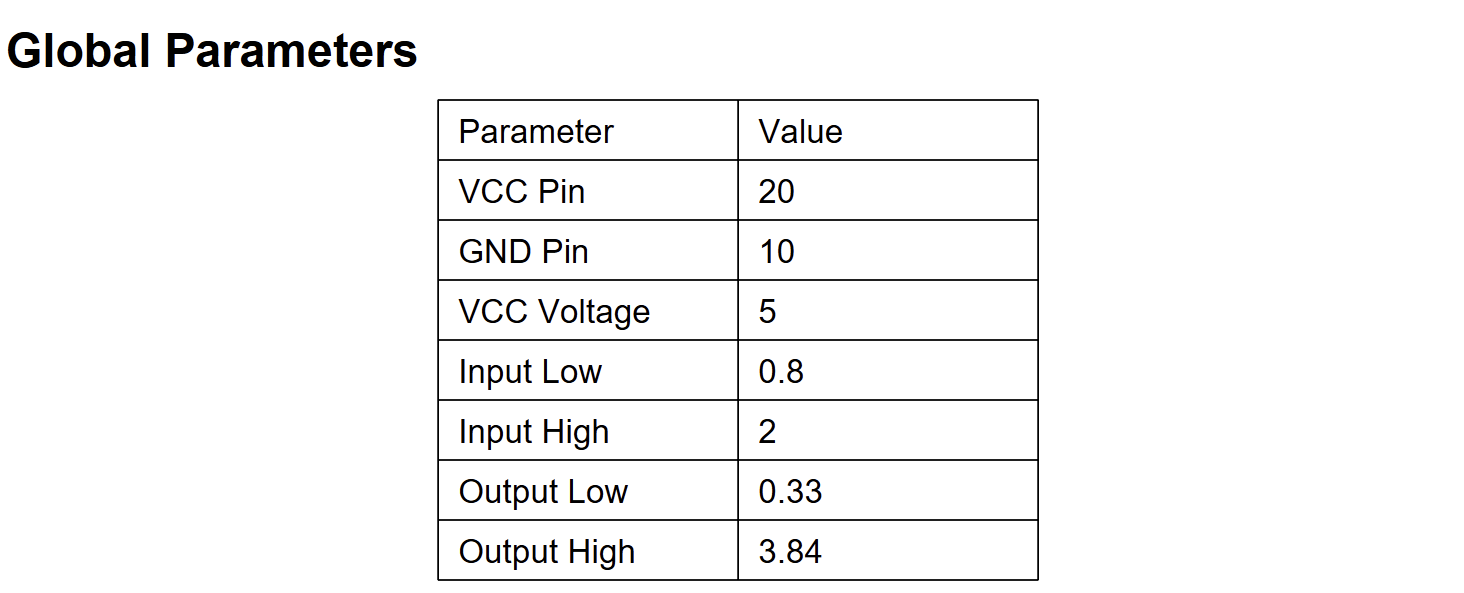
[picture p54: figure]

Figure 19. Global Parameters of the Digital IC under test.

The test script configuration is defined through two key sections: Global Parameters and the Pin Map. Together, these provide a structured and hardware-independent way to control and evaluate the device under test (DUT).

The Global Parameters section establishes the core electrical settings required for testing, including the VCC and GND pin assignments, operating supply voltage, and logic threshold levels. These parameters define how the DUT is powered and how logical HIGH and LOW states are interpreted during testing. Since VCC and GND are automatically driven by the system, they do not need to be redefined elsewhere in the script, ensuring consistent and reliable operation.

The Pin Map section provides an abstraction layer that maps descriptive pin names to their corresponding physical socket positions. This allows test scripts to reference pins by function rather than numeric indices, improving readability and reducing the likelihood of errors. By separating logical naming from physical pin assignments, the same test logic can be reused across different ICs with minimal modification.

Together, these sections simplify test development by centralizing configuration, improving clarity, and enabling flexible adaptation to different devices and operating conditions.

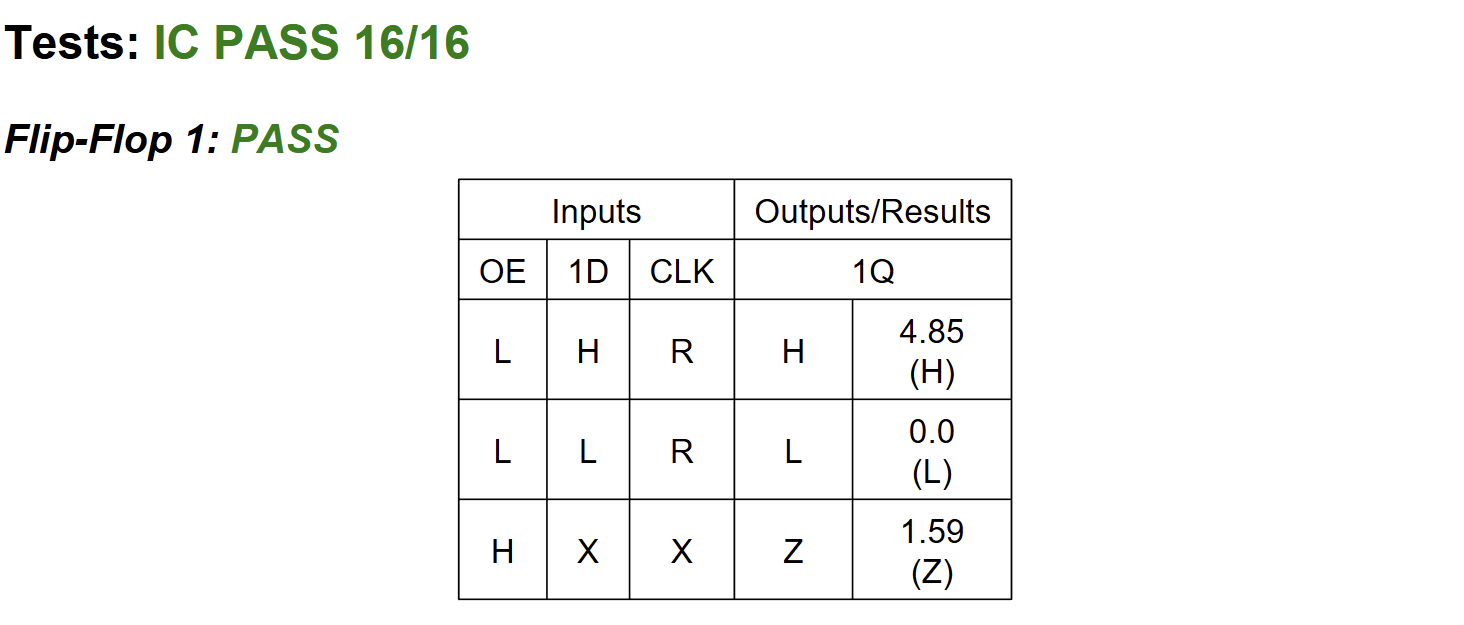
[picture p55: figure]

Figure 20. Example of passing test script for tri-state output IC.

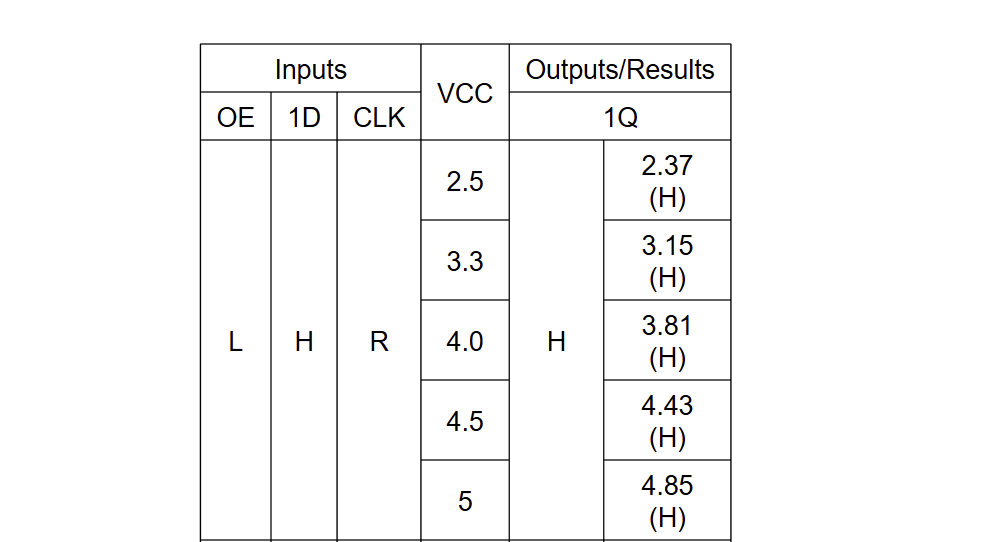
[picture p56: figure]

Figure 21. Example of passing test for IC tested at multiple voltage levels.

The outputs of all the tests are in the Tests section of the PDF report. In the header, there is an overall PASS or FAIL for the IC, and a fraction of the total tests that passed.

The results shown in Figures 20 and 21 demonstrate the correct functionality of the tri-state flip-flop IC under various input conditions and supply voltages. Overall, the device passed all 16 test cases, indicating that it operates within expected logic behavior.

Figure 20 validates the logical operation of the flip-flop under different input conditions. When the output enable (OE) is low (enabled) and the clock (CLK) experiences a rising edge, the device correctly latches the input data. Specifically, when D is high, the output Q transitions to a high state, measured at 4.85 V, which lies within the defined HIGH threshold. Conversely, when D is low, the output Q transitions to a low state, measured at 0.0 V, confirming proper LOW-level operation. When OE is high (disabled), the output enters a high-impedance (Hi-Z) state, indicated by a measured voltage of 1.59 V. This value falls between the defined HIGH and LOW thresholds, confirming that the output is not actively driven and is effectively floating, as expected for a tri-state output. These results demonstrate that the IC correctly performs data latching on the rising clock edge and properly transitions into Hi-Z mode when disabled.

Figure 21 demonstrates how the output voltage scales with varying supply voltages (VCC). As VCC increases from 2.5 V to 5 V, the measured output HIGH voltage increases proportionally, with values of 2.37 V at 2.5 V, 3.15 V at 3.3 V, 3.81 V at 4.0 V, 4.43 V at 4.5 V, and 4.85 V at 5 V. In all cases, the output remains within the defined HIGH logic threshold, confirming correct logic-level operation. These results indicate that the IC maintains proper functionality across a range of supply voltages, while also verifying that the system’s voltage reference generation and measurement circuitry are operating accurately. Overall, the device under test (DUT) exhibits consistent and expected electrical behavior under varying operating conditions.

VI. Troubleshooting

Failed to Open Serial Port

Ensure device is detectable by host PC with the following information:

- VID: 10C4
- PID: EA60
- Serial Number: 554D4C2043617073746F6E652032352D333034204E5557432032303236

If not, ensure that the Silicon Labs CP210X driver is installed on your device.

https://www.silabs.com/interface/usb bridges/classic/device.cp2102?tab=softwareandtools (https://www.silabs.com/interface/usb%20bridges/classic/device.cp2102?tab=softwareandtools)

The serial number can be programmed by downloading “AN721: CP210x/CP211x Device Customization Guide” through the same link.

Checksum

Ensure that firmware and Python executable have not been tampered with. Reflash and rebuild the issues persist.

If operating in a development environment, the firmware checksum can be updated in software/serial_manager.py::Checksum and update the variable EXPECTED_CHECKSUM. For the software checksum, ensure that append_checksum.py is called and the computed checksum is appended to the end of the .exe file. For SHA-256, the checksum is 32-bytes. During runtime, the checksum is computed using all the bytes of the executable (except the last 32-bytes) and compared to the last 32-bytes of the executable.

Integrated Circuit Failed

Ensure that the IC is firmly placed in the socket and is level. Verify that the test script is written correctly. The number of the pins on the IC follows the standard counting for ICs, pin 1 is the top left, and increments counter-clockwise with pin 20 on the top right. This relevant for pins that are the right of the IC as they are likely shifted upwards by 20 – number of pins on the IC.

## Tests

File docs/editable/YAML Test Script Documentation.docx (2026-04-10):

IC Test Fixture YAML Test Scripts

YAML (YAML Ain’t Markup Language) is a human-readable data serialization language. The syntax relies on proper indentation and primarily uses key-value pairs to create visually clean hierarchical data. By default, these files are encoded in UTF-8. Documentation for YAML can be found here: https://yaml.org/

Test scripts written in YAML are used to interface with the test fixture and test digital integrated circuits (ICs). These test scripts relay the operation of the IC and its expected performance under specified conditions. Customizable tests can be written to accommodate sequential and combinational logic.

Basic Syntax

YAML’s primary data structure is based on key-value pairs. Keys must be scalar values, integers, strings, or floating-point decimals. A ‘:’ is used to indicate the key-value pair relationship. All keys must be unique; otherwise, the value for a certain key will be overwritten with the most recent value for that key.

Figure 1.1. Examples of key-value pairs

Additionally, hexadecimal (0x) or binary (0b) can be used in place of integers; however, during parsing, they will be treated as unsigned integer literals. To keep them as a string, single or double quotation marks can be used to explicitly make them a string.

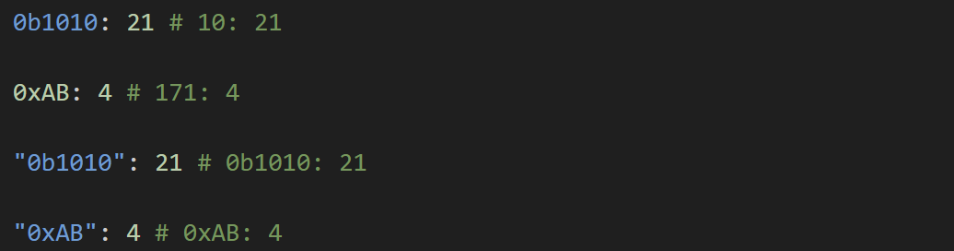
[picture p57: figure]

Figure 1.2. Examples of non-base 10 integers

To create an array/list, either square brackets ([]), delimiting elements with a comma, or hyphens (-) with an extra indentation on subsequent lines can be used.

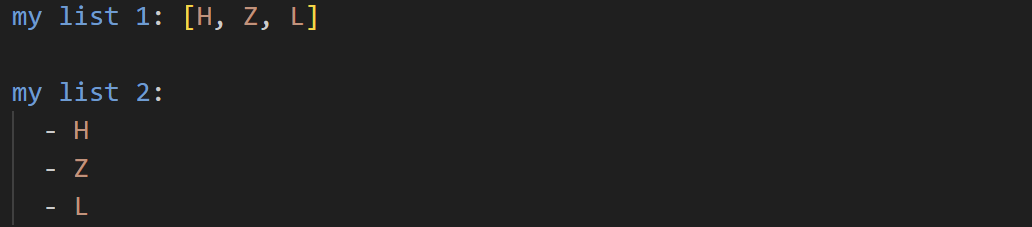
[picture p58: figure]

Figure 1.3. Examples of creating a list

To create nested dictionaries, curly brackets ({}), delimiting key-value pairs with a comma, or chaining multiple key-value pairs with extra indentations based on the level of nesting needed on subsequent lines, can be used. When using key-value pairs, the highest key must have an empty value.

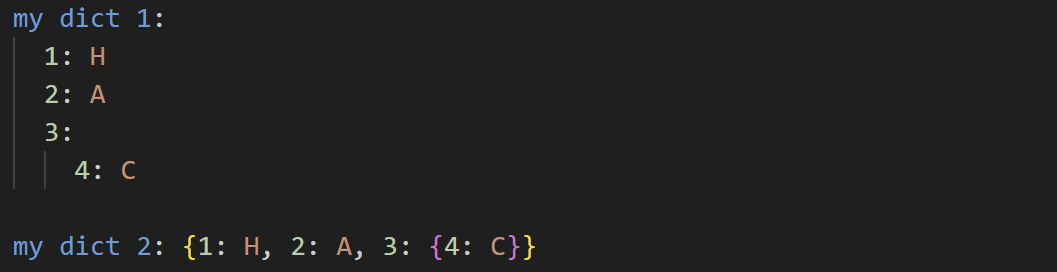
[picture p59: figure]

Figure 1.4. Examples of creating a nested dictionary

Any numbers relating to pins are restricted to a range of 1-20, the number of pins the hardware can support.

The supported voltages are within the set 1.8, 2.5, 3.3, 4.0, 4.5, and 5.0.

The supported input logic is within the set H, L, R, F, and X. R and F are respectively rising and falling edges. This will communicate the test fixture to pulse the specified edge. The test fixture only supports pulsing one of these signals at a time. X will default to logic LOW when used.

The supported output logic is within the set H, L, Z, and X. Z represents the high impedance output (Hi-Z), typically used for ICs with tri-state outputs.

Any IC with special outputs beyond the supported logic symbols can be tested by creating serial inputs and serial outputs to represent the expected output at a lower level.

Chip Info

The Chip Info section allows users to include any additional data regarding the chip under test. None of this information is verified or parsed by the software, as it does not affect how the chip is tested. The information listed here is to be added to the automatically generated PDF report after testing the device is completed. This is useful if the report is to be read by others who may not fully understand the contents of the report or would like additional testing metadata. This section is optional in the test script.

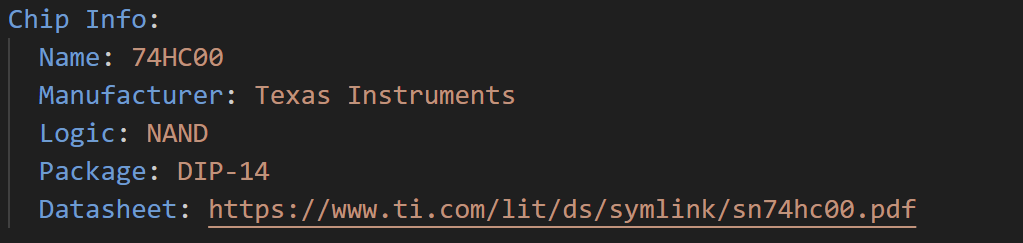
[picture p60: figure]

Figure 2.1. Example of information about a chip.

Note: everything printed to the PDF report will be the default string representation in Python.

Global Parameters

The Global Parameters section lists all of the test parameters used across all tests in the test sections. These parameters include: VCC Pin, GND Pin, VCC Voltage, Input Low, Input High, Output Low, and Output High.

VCC Pin and GND Pin are, respectively, the power and ground pins used to power the IC during operation. Their values are literal integers. The VCC Voltage is the voltage level used to drive the chip; this voltage is also used as the default logic HIGH voltage during testing. This is expected to be a floating-point decimal or a list of floating-point decimals.

Input Low, Input High, Output Low, and Output High are the voltage thresholds the chip recognizes for an input or output of logic LOW and logic HIGH. Any output logic identified by the system is based on the given output voltage thresholds. Input Low and Input High are optional parameters that the user can provide. Their values are either a floating-point decimal or a list of floating-point decimals.

All lists should be parallel to each other, meaning they must be the same length, and elements at the same index correspond to each other during testing. Using lists allows users to test ICs at various supply voltage levels. This section is required to be in the test script.


Figure 3.1. Example of Global Parameters Section

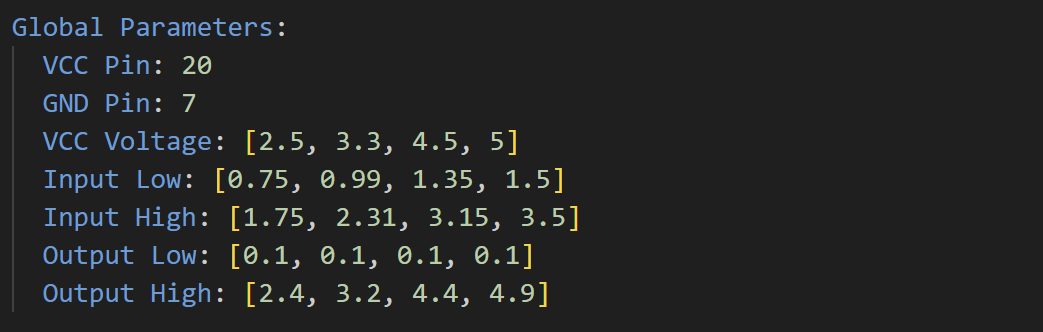
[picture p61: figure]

Figure 3.2. Example of Global Parameters Section using list values.

Note: Input Low and Input High are not actively used during parsing or testing.

Pin Map

The Pin Map section provides an abstraction layer between the test scripts and the physical pins of the IC. It allows users to map pin names to their corresponding socket positions (represented by numeric values). By using the Pin Map, test scripts can reference pins by name rather than by integer values, improving readability and maintainability when specifying which pins to drive or measure. This section is optional in the test script.

Note that VCC and GND pins do not need to be included in the Pin Map, as they are already defined in the Global Parameters section and are always driven during IC testing.


Figure 4.1. Example of Pin Map section

Truth Table

The Truth Table section provides an abstraction layer for defining the logic used to drive and evaluate pins in the test scripts. It is represented as a list of dictionaries, where each key–value pair defines a logic grouping and its associated supported logic symbol. The names of these logic groupings are independent and do not need to match any names defined in the Pin Map or other sections of the test script. Each dictionary in the list must contain the same set of keys and the same number of key–value pairs. While the order of keys does not need to be identical across dictionaries, maintaining a consistent order is recommended for readability and easier visualization of the IC’s truth table. Each dictionary represents a single row in the IC’s truth table. This section is optional in the test scripts.


Figure 5.1. Example of Truth Table section.

Note: Serial inputs or outputs are not supported as a value in the Truth Table.

Tests

The Tests section defines how the test fixture is controlled, specifying which pins to drive, which pins to measure, and the expected logic outputs. This section is structured as a dictionary of test cases. Each test case is identified by a unique name and contains two subkeys: Inputs and Outputs. Multiple test cases can be defined to cover different scenarios. Each test case is independent; inputs and outputs do not carry over between tests. This section is required in the test scripts.

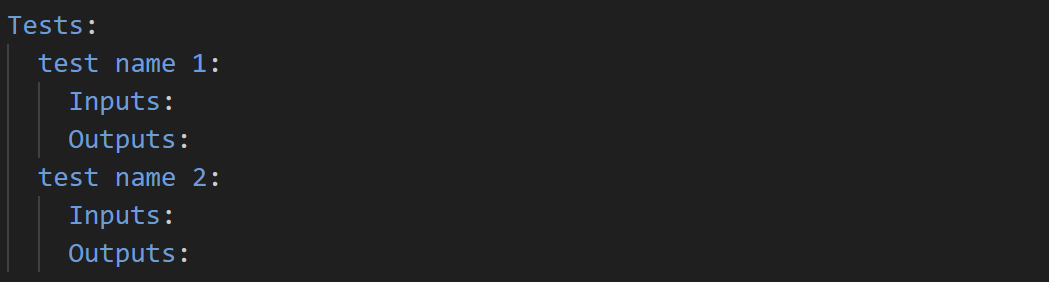
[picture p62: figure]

Figure 6.1. Basic structure of Tests section

I/O Formatting

The Tests section offers various support for different formatting of inputs and outputs, allowing pins and their outputs to be logically grouped together in a single line. The basic structure for formatting inputs the pin numbers or names, delimited by a comma, followed by the driving/expected logic. There are 3 types of formatting that can be used: single, map, and serial.

Single

With Single formatting, there is only one logic in the value of the pair. This logic is mapped to all the pins designated in the key. Optionally, a voltage may be supplied in the input command to use a different voltage from the VCC voltage when driving a logic HIGH signal. If a logic LOW is specified, the voltage is ignored. This type of command is useful when multiple pins with similar responsibilities require the same type of logic.

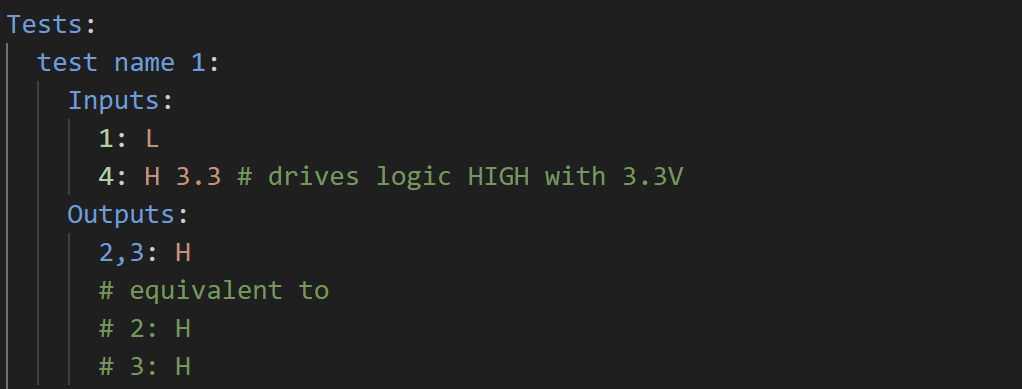
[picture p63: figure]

Figure 6.2. Examples of a Single type command

Map

Using the Map formatting, an equal number of logic values and pins directly correspond to each other. The first pin listed will have the first logic value listed, the second pin will have the second logic value, etc. This type of command is useful for pins that have similar responsibilities but require different logic values. For example, select bits on a multiplexer, or n-bits used to represent integers. Additionally, this command also supports integers as the logic value. The integers assume big-endian notation, meaning the first pin will represent the most significant bit. Like Single, optionally, a voltage can be added to the input command to specify a different voltage than the VCC voltage for logic HIGH. If there is any logic LOW in the command, the voltage is ignored.

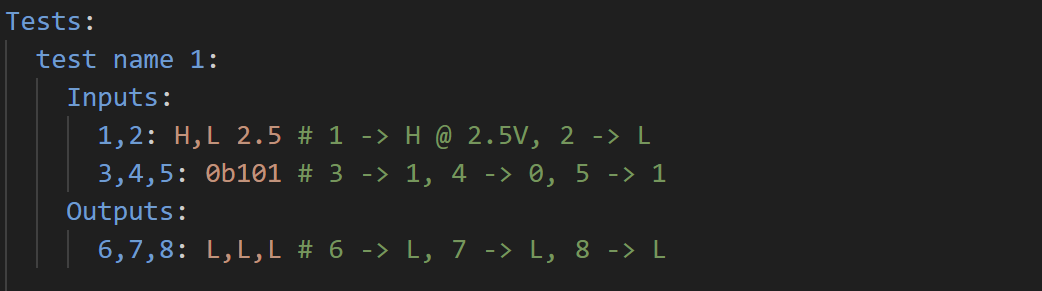
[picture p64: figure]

Figure 6.3. Examples of Map type command

Serial

The serial formatting allows pins to be driven with a series of logic values. This command is denoted by creating a list of logic values. All lists of logic values are parallel to each other, meaning that elements with the same index correspond to each other. During testing, inputs are driven with the value at index i, and the expected outputs are located at index i of the command. Unlike separate test cases, the serial command will carry over inputs and states between each step.

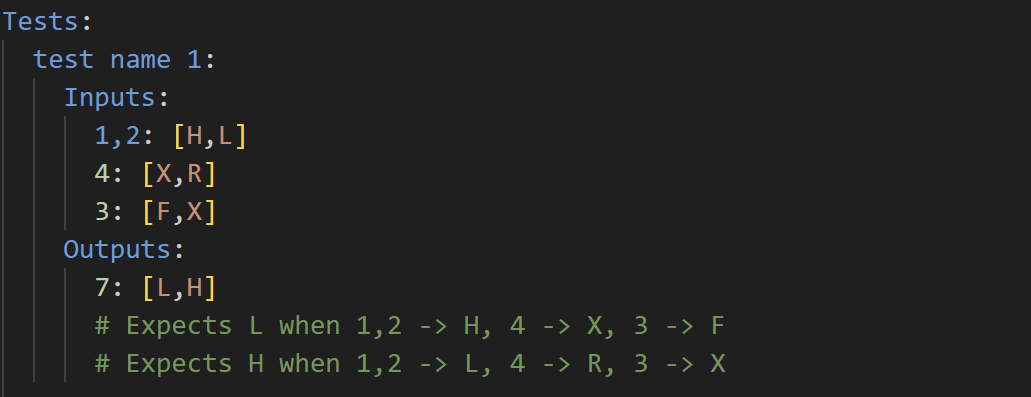
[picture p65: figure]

Figure 6.4. Example of Serial type command

The lists do not need to be the same length; if one command is serial, the remaining inputs and outputs are padded to the longest serial command. They are padded using the last logic value specified in the command.

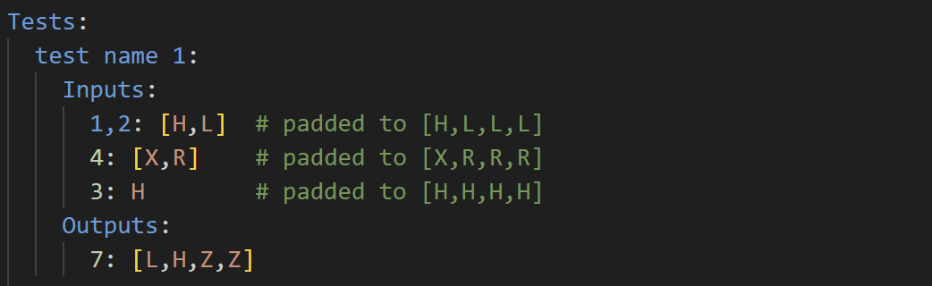
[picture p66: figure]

Figure 6.5. Serial type command with padding

The lists do not need to be the same length; if one command is serial, the remaining inputs and outputs are padded to the longest serial command. They are padded using the last logic value specified in the command. This command is useful for ICs with serial inputs and outputs, and ICs with outputs dependent on previous I/O. Unlike the previous command types, serial commands do not support a different voltage from the VCC voltage. Any logic value that uses a reference from a truth table is considered a serial command.

If Pin Map and/or Truth Table sections are included in the test scripts, the pins and logic values can be abstracted to the names of pins and logic values.

Figure 6.6 Abstracted commands using Pin Map and Truth Table references.

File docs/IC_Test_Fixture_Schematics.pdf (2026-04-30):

REVISION | DESCRIPTION | DATE | APPROVED | REV. SHT. DWG. NO. 1

# 3.3V LDO Circuit


THIS DOCUMENT AND THE DATA DISCLOSED HEREIN OR
HEREWITH IS THE PROPERTY OF ALTIUM LIMITED AND MAY
BE FREELY DISTRIBUTED IN WHOLE. NO RIGHTS ARE
RESERVED OR EXPRESS OR IMPLIED WARANTEE GIVEN.

Power & Data Isolator Circuit

Active Status LED for Device

DATE | PROJECT * | ADDRESS 1 ADDRESS 2 APPROVALS ADDRESS 3 ADDRESS 4

ENG: Will Mensah | --/--/--
DSN: * | --/--/--
CHK: * | --/--/--

REVISION | DESCRIPTION | DATE | APPROVED | REV. SHT. DWG. NO. 2

# STM32 Circuit


BE FREELY DISTRIBUTED IN WHOLE. NO RIGHTS ARE
RESERVED OR EXPRESS OR IMPLIED WARANTEE GIVEN.

JST XH Series Connector

Volage Translator Circuit for STM32 MCO

APPROVALS | DATE | PROJECT | * *

ENG: *
DSN: Will Mensah
CHK: *

REVISION | DESCRIPTION | DATE | APPROVED | REV. SHT. DWG. NO. 3
X6 | 17 X7 | 18 X8 | 19 X9 | 20 X10 | 21 X11 | 22 NC | 23 VDD | 24 VL | 25 SDA | 26 SCL | 27 A0 | 28 A1 | 29 A2 | 30 *RESET | 31 GND | 32 EPAD | HTAB


BE FREELY DISTRIBUTED IN WHOLE. NO RIGHTS ARE
RESERVED OR EXPRESS OR IMPLIED WARANTEE GIVEN.

Analog Switch Array Circuit 1

Analog Switch Array Circuit 2

DATE | PROJECT * | ADDRESS 1 ADDRESS 2 APPROVALS ADDRESS 3 ADDRESS 4

ENG: * | --/--/--
DSN: Will Mensah | --/--/--
CHK: * | --/--/--

REVISION | DESCRIPTION | DATE | APPROVED | REV. SHT. DWG. NO. 4

# 8:1 Multiplexer Circuit 1


BE FREELY DISTRIBUTED IN WHOLE. NO RIGHTS ARE
RESERVED OR EXPRESS OR IMPLIED WARANTEE GIVEN.

DATE | PROJECT * | ADDRESS 1 ADDRESS 2 APPROVALS ADDRESS 3 ADDRESS 4

ENG: * | --/--/--
DSN: Will Mensah | --/--/--
CHK: * | --/--/--

REVISION | DESCRIPTION | DATE | APPROVED | REV. SHT. DWG. NO. 5
1.8V Reference Circuit | 2.5V Reference Circuit | 3.3V Reference Circuit


BE FREELY DISTRIBUTED IN WHOLE. NO RIGHTS ARE
RESERVED OR EXPRESS OR IMPLIED WARANTEE GIVEN.

DATE | PROJECT * | ADDRESS 1 ADDRESS 2 APPROVALS ADDRESS 3 ADDRESS 4

ENG: * | --/--/--
DSN: * | --/--/--
CHK: * | --/--/--

REVISION | DESCRIPTION | DATE | APPROVED | REV. SHT. DWG. NO. 6

# ZIF Socket


BE FREELY DISTRIBUTED IN WHOLE. NO RIGHTS ARE
RESERVED OR EXPRESS OR IMPLIED WARANTEE GIVEN.

Voltage Converter for Switch Array CIrcuits

High Impedance (HI-Z) Circuit for the ADC DA

DATE | PROJECT * | ADDRESS 1 ADDRESS 2 APPROVALS ADDRESS 3 ADDRESS 4

ENG: * | --/--/--
DSN: * | --/--/-- | PROJECT REVISION: | DOCUMENT REVISION: | DESIGN ITEM: 47adc0b8f438799fd026403113170ac1c27f8eec Unknown revision
CHK: * | --/--/--

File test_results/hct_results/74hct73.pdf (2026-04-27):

## Pin Map

Pin Name | Pin | Pin Name | Pin
1CP | 1 | 1R | 2
1K | 3 | 2CP | 5
2R | 6 | 2J | 7
2Qnot | 14 | 2Q | 15
2K | 16 | 1Q | 18
1Qnot | 19 | 1J | 20

## Global Parameters

Parameter | Value
VCC Pin | 4
GND Pin | 17
VCC Voltage | 5
Input Low | 0.8
Input High | 2
Output Low | 0.33
Output High | 3.84

## Tests: IC FAIL 6/7

### JK Flip-Flop 1: PASS

Inputs | Outputs/Results
1R | 1J | 1K | 1CP | 1Q | 1Qnot
L | X | X | X | L | 0.0 (L) H | 4.85 (H)
H | H | L | F | H | 4.85 (H) L | 0.0 (L)
H | L | H | F | L | 0.0 (L) H | 4.85 (H)

### JK Flip-Flop 2: PASS

Inputs | Outputs/Results
2R | 2J | 2K | 2CP | 2Q | 2Qnot
L | X | X | X | L | 0.0 (L) H | 4.85 (H)
H | H | L | F | H | 4.85 (H) L | 0.0 (L)

Inputs | Outputs/Results
2R | 2J | 2K | 2CP | 2Q | 2Qnot
H | L | H | F | L | 0.0 (L) H | 4.85 (H)

### No Change 1 -> L: PASS

Inputs | Outputs/Results
1R, 2R | 1J, 2J | 1K, 2K | 1CP, 2CP | 1Q | 2Q | 1Qnot | 2Qnot
L | X | X | X | L | 0.0 (L) L | | 0.0 (L) H | 4.85 (H) H | 4.85 (H)
H | L | L | F | L | 0.0 (L) L | | 0.0 (L) H | 4.85 (H) H | 4.85 (H)

### No Change 1 -> H: PASS

Inputs | Outputs/Results
1R, 2R | 1J, 2J | 1K, 2K | 1CP, 2CP | 1Q | 2Q | 1Qnot | 2Qnot
H | H | L | F | H | 4.85 (H) H | | 4.85 (H) L | 0.0 (L) L | 0.0 (L)
H | L | L | F | H | 4.85 (H) H | | 4.85 (H) L | 0.0 (L) L | 0.0 (L)

### No Change 2 -> L: PASS

Inputs | Outputs/Results
1R, 2R | 1J, 2J | 1K, 2K | 1CP, 2CP | 1Q | 2Q | 1Qnot | 2Qnot
L | X | X | X | L | 0.0 (L) L | | 0.0 (L) H | 4.85 (H) H | 4.85 (H)
H | X | X | H | L | 0.0 (L) L | | 0.0 (L) H | 4.85 (H) H | 4.85 (H)

### No Change 2 -> H: PASS

Inputs | Outputs/Results
1R, 2R | 1J, 2J | 1K, 2K | 1CP, 2CP | 1Q | 2Q | 1Qnot | 2Qnot
H | H | L | F | H | 4.85 (H) H | | 4.85 (H) L | 0.0 (L) L | 0.0 (L)
H | X | X | H | H | 4.85 (H) H | | 4.85 (H) L | 0.0 (L) L | 0.0 (L)

### Toggle: FAIL

Inputs | Outputs/Results
1R, 2R | 1J, 2J | 1K, 2K | 1CP, 2CP | 1Q | 2Q | 1Qnot | 2Qnot
L | X | X | X | L | 0.0 (L) L | | 0.0 (L) H | 4.85 (H) H | 4.85 (H)

Inputs | Outputs/Results
1R, 2R | 1J, 2J | 1K, 2K | 1CP, 2CP | 1Q | 2Q | 1Qnot | 2Qnot
H | H | H | F | H | 4.85 (H) H | | 4.85 (H) L | 0.0 (L) L | 0.0 (L)
H | H | H | F | L | 0.0 (L) L | | 4.85 (H) H | 4.85 (H) H | 0.0 (L)

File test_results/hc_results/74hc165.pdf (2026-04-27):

## Pin Map

Pin Name | Pin | Pin Name | Pin
SH/LD | 1 | CLK | 2
E | 3 | F | 4
G | 5 | H | 6
QHnot | 7 | QH | 13
SER | 14 | A | 15
B | 16 | C | 17
D | 18 | CLK INH | 19

## Global Parameters

Parameter | Value
VCC Pin | 20
GND Pin | 8
VCC Voltage | 2.5, 3.3, 4.0, 4.5, 5
Input Low | 0.75, 0.99, 1.2, 1.35, 1.5
Input High | 1.75, 2.31, 2.8, 3.15, 3.5
Output Low | 0.3, 0.3, 0.3, 0.3, 0.3
Output High | 2.2, 3.0, 3.6, 4.1, 4.7

## Tests: IC PASS 5/5

### Parallel Load: PASS

Inputs | VCC | Outputs/Results
SH/LD | SER | CLK INH | A, B, C, D, E, F, G, H | CLK | | QH | QHnot
L | L | X | H, L, H, L, H, L, H, H | X | 2.5 | H | 2.37 (H) | L | 0.0 (L)
| | | | | 3.3 | | 3.15 (H) | | 0.0 (L)
| | | | | 4.0 | | 3.81 (H) | | 0.0 (L)
| | | | | 4.5 | | 4.43 (H) | | 0.0 (L)
| | | | | 5 | | 4.85 (H) | | 0.0 (L)
H | L | L | H, L, H, L, H, L, H, H | R | 2.5 | H | 2.37 (H) | L | 0.0 (L)
| | | | | 3.3 | | 3.15 (H) | | 0.0 (L)
| | | | | 4.0 | | 3.81 (H) | | 0.0 (L)
| | | | | 4.5 | | 4.43 (H) | | 0.0 (L)
| | | | | 5 | | 4.85 (H) | | 0.0 (L)
H | L | L | H, L, H, L, H, L, H, H | R | 2.5 | L | 0.0 (L) | H | 2.37 (H)
| | | | | 3.3 | | 0.0 (L) | | 3.15 (H)
| | | | | 4.0 | | 0.0 (L) | | 3.81 (H)
| | | | | 4.5 | | 0.0 (L) | | 4.43 (H)
| | | | | 5 | | 0.0 (L) | | 4.85 (H)
H | L | L | H, L, H, L, H, L, H, H | R | 2.5 | H | 2.37 (H) | L | 0.0 (L)
| | | | | 3.3 | | 3.15 (H) | | 0.0 (L)
| | | | | 4.0 | | 3.81 (H) | | 0.0 (L)
| | | | | 4.5 | | 4.43 (H) | | 0.0 (L)
| | | | | 5 | | 4.85 (H) | | 0.0 (L)

Inputs | VCC | Outputs/Results
SH/LD | SER | CLK INH | A, B, C, D, E, F, G, H | CLK | | QH | QHnot
H | L | L | H, L, H, L, H, L, H, H | R | 2.5 | L | 0.0 (L) | H | 2.37 (H)
| | | | | 3.3 | | 0.0 (L) | | 3.15 (H)
| | | | | 4.0 | | 0.0 (L) | | 3.81 (H)
| | | | | 4.5 | | 0.0 (L) | | 4.43 (H)
| | | | | 5 | | 0.0 (L) | | 4.85 (H)
H | L | L | H, L, H, L, H, L, H, H | R | 2.5 | H | 2.37 (H) | L | 0.0 (L)
| | | | | 3.3 | | 3.15 (H) | | 0.0 (L)
| | | | | 4.0 | | 3.81 (H) | | 0.0 (L)
| | | | | 4.5 | | 4.43 (H) | | 0.0 (L)
| | | | | 5 | | 4.85 (H) | | 0.0 (L)
H | L | L | H, L, H, L, H, L, H, H | R | 2.5 | L | 0.0 (L) | H | 2.37 (H)
| | | | | 3.3 | | 0.0 (L) | | 3.15 (H)
| | | | | 4.0 | | 0.0 (L) | | 3.81 (H)
| | | | | 4.5 | | 0.0 (L) | | 4.43 (H)
| | | | | 5 | | 0.0 (L) | | 4.85 (H)
H | L | L | H, L, H, L, H, L, H, H | R | 2.5 | H | 2.37 (H) | L | 0.0 (L)
| | | | | 3.3 | | 3.15 (H) | | 0.0 (L)
| | | | | 4.0 | | 3.81 (H) | | 0.0 (L)
| | | | | 4.5 | | 4.43 (H) | | 0.0 (L)
| | | | | 5 | | 4.85 (H) | | 0.0 (L)

### Serial In 1: PASS

Inputs | VCC | Outputs/Results
SH/LD | SER | A, B, C, D, E, F, G, H | CLK | CLK INH | | QH | QHnot
L | X | H, L, H, L, H, L, H, L | X | X | 2.5 | L | 0.0 (L) | H | 2.37 (H)
| | | | | 3.3 | | 0.0 (L) | | 3.15 (H)
| | | | | 4.0 | | 0.0 (L) | | 3.81 (H)
| | | | | 4.5 | | 0.0 (L) | | 4.43 (H)
| | | | | 5 | | 0.0 (L) | | 4.85 (H)
H | L | H, L, H, L, H, L, H, L | L | R | 2.5 | H | 2.37 (H) | L | 0.0 (L)
| | | | | 3.3 | | 3.15 (H) | | 0.0 (L)
| | | | | 4.0 | | 3.81 (H) | | 0.0 (L)
| | | | | 4.5 | | 4.43 (H) | | 0.0 (L)
| | | | | 5 | | 4.85 (H) | | 0.0 (L)
H | L | H, L, H, L, H, L, H, L | L | R | 2.5 | L | 0.0 (L) | H | 2.37 (H)
| | | | | 3.3 | | 0.0 (L) | | 3.15 (H)
| | | | | 4.0 | | 0.0 (L) | | 3.81 (H)
| | | | | 4.5 | | 0.0 (L) | | 4.43 (H)
| | | | | 5 | | 0.0 (L) | | 4.85 (H)
H | H | H, L, H, L, H, L, H, L | L | R | 2.5 | H | 2.37 (H) | L | 0.0 (L)
| | | | | 3.3 | | 3.15 (H) | | 0.0 (L)
| | | | | 4.0 | | 3.81 (H) | | 0.0 (L)
| | | | | 4.5 | | 4.43 (H) | | 0.0 (L)
| | | | | 5 | | 4.85 (H) | | 0.0 (L)

Inputs | VCC | Outputs/Results
SH/LD | SER | A, B, C, D, E, F, G, H | CLK | CLK INH | | QH | QHnot
H | H | H, L, H, L, H, L, H, L | L | R | 2.5 | L | 0.0 (L) | H | 2.37 (H)
| | | | | 3.3 | | 0.0 (L) | | 3.15 (H)
| | | | | 4.0 | | 0.0 (L) | | 3.81 (H)
| | | | | 4.5 | | 0.0 (L) | | 4.43 (H)
| | | | | 5 | | 0.0 (L) | | 4.85 (H)
H | L | H, L, H, L, H, L, H, L | L | R | 2.5 | H | 2.37 (H) | L | 0.0 (L)
| | | | | 3.3 | | 3.15 (H) | | 0.0 (L)
| | | | | 4.0 | | 3.81 (H) | | 0.0 (L)
| | | | | 4.5 | | 4.43 (H) | | 0.0 (L)
| | | | | 5 | | 4.85 (H) | | 0.0 (L)
H | L | H, L, H, L, H, L, H, L | L | R | 2.5 | L | 0.0 (L) | H | 2.37 (H)
| | | | | 3.3 | | 0.0 (L) | | 3.15 (H)
| | | | | 4.0 | | 0.0 (L) | | 3.81 (H)
| | | | | 4.5 | | 0.0 (L) | | 4.43 (H)
| | | | | 5 | | 0.0 (L) | | 4.85 (H)
H | H | H, L, H, L, H, L, H, L | L | R | 2.5 | H | 2.37 (H) | L | 0.0 (L)
| | | | | 3.3 | | 3.15 (H) | | 0.0 (L)
| | | | | 4.0 | | 3.81 (H) | | 0.0 (L)
| | | | | 4.5 | | 4.43 (H) | | 0.0 (L)
| | | | | 5 | | 4.85 (H) | | 0.0 (L)

Inputs | VCC | Outputs/Results
SH/LD | SER | A, B, C, D, E, F, G, H | CLK | CLK INH | | QH | QHnot
H | H | H, L, H, L, H, L, H, L | L | R | 2.5 | L | 0.0 (L) | H | 2.37 (H)
| | | | | 3.3 | | 0.0 (L) | | 3.15 (H)
| | | | | 4.0 | | 0.0 (L) | | 3.81 (H)
| | | | | 4.5 | | 0.0 (L) | | 4.43 (H)
| | | | | 5 | | 0.0 (L) | | 4.85 (H)
H | H | H, L, H, L, H, L, H, L | L | R | 2.5 | L | 0.0 (L) | H | 2.37 (H)
| | | | | 3.3 | | 0.0 (L) | | 3.15 (H)
| | | | | 4.0 | | 0.0 (L) | | 3.81 (H)
| | | | | 4.5 | | 0.0 (L) | | 4.43 (H)
| | | | | 5 | | 0.0 (L) | | 4.85 (H)
H | H | H, L, H, L, H, L, H, L | L | R | 2.5 | H | 2.37 (H) | L | 0.0 (L)
| | | | | 3.3 | | 3.15 (H) | | 0.0 (L)
| | | | | 4.0 | | 3.81 (H) | | 0.0 (L)
| | | | | 4.5 | | 4.43 (H) | | 0.0 (L)
| | | | | 5 | | 4.86 (H) | | 0.0 (L)
H | H | H, L, H, L, H, L, H, L | L | R | 2.5 | H | 2.37 (H) | L | 0.0 (L)
| | | | | 3.3 | | 3.15 (H) | | 0.0 (L)
| | | | | 4.0 | | 3.81 (H) | | 0.0 (L)
| | | | | 4.5 | | 4.43 (H) | | 0.0 (L)
| | | | | 5 | | 4.85 (H) | | 0.0 (L)

Inputs | VCC | Outputs/Results
SH/LD | SER | A, B, C, D, E, F, G, H | CLK | CLK INH | | QH | QHnot
H | H | H, L, H, L, H, L, H, L | L | R | 2.5 | L | 0.0 (L) | H | 2.37 (H)
| | | | | 3.3 | | 0.0 (L) | | 3.15 (H)
| | | | | 4.0 | | 0.0 (L) | | 3.81 (H)
| | | | | 4.5 | | 0.0 (L) | | 4.43 (H)
| | | | | 5 | | 0.0 (L) | | 4.85 (H)
H | H | H, L, H, L, H, L, H, L | L | R | 2.5 | L | 0.0 (L) | H | 2.37 (H)
| | | | | 3.3 | | 0.0 (L) | | 3.15 (H)
| | | | | 4.0 | | 0.0 (L) | | 3.81 (H)
| | | | | 4.5 | | 0.0 (L) | | 4.43 (H)
| | | | | 5 | | 0.0 (L) | | 4.86 (H)
H | H | H, L, H, L, H, L, H, L | L | R | 2.5 | H | 2.37 (H) | L | 0.0 (L)
| | | | | 3.3 | | 3.15 (H) | | 0.0 (L)
| | | | | 4.0 | | 3.81 (H) | | 0.0 (L)
| | | | | 4.5 | | 4.43 (H) | | 0.0 (L)
| | | | | 5 | | 4.85 (H) | | 0.0 (L)
H | H | H, L, H, L, H, L, H, L | L | R | 2.5 | H | 2.37 (H) | L | 0.0 (L)
| | | | | 3.3 | | 3.15 (H) | | 0.0 (L)
| | | | | 4.0 | | 3.81 (H) | | 0.0 (L)
| | | | | 4.5 | | 4.43 (H) | | 0.0 (L)
| | | | | 5 | | 4.85 (H) | | 0.0 (L)

### Serial In 2: PASS

Inputs | VCC | Outputs/Results
SH/LD | SER | A, B, C, D, E, F, G, H | CLK | CLK INH | | QH | QHnot
L | X | H, L, H, L, H, L, H, L | X | X | 2.5 | L | 0.0 (L) | H | 2.37 (H)
| | | | | 3.3 | | 0.0 (L) | | 3.15 (H)
| | | | | 4.0 | | 0.0 (L) | | 3.81 (H)
| | | | | 4.5 | | 0.0 (L) | | 4.43 (H)
| | | | | 5 | | 0.0 (L) | | 4.86 (H)
H | L | H, L, H, L, H, L, H, L | R | L | 2.5 | H | 2.37 (H) | L | 0.0 (L)
| | | | | 3.3 | | 3.15 (H) | | 0.0 (L)
| | | | | 4.0 | | 3.81 (H) | | 0.0 (L)
| | | | | 4.5 | | 4.43 (H) | | 0.0 (L)
| | | | | 5 | | 4.86 (H) | | 0.0 (L)
H | L | H, L, H, L, H, L, H, L | R | L | 2.5 | L | 0.0 (L) | H | 2.37 (H)
| | | | | 3.3 | | 0.0 (L) | | 3.15 (H)
| | | | | 4.0 | | 0.0 (L) | | 3.81 (H)
| | | | | 4.5 | | 0.0 (L) | | 4.43 (H)
| | | | | 5 | | 0.0 (L) | | 4.86 (H)
H | H | H, L, H, L, H, L, H, L | R | L | 2.5 | H | 2.37 (H) | L | 0.0 (L)
| | | | | 3.3 | | 3.15 (H) | | 0.0 (L)
| | | | | 4.0 | | 3.81 (H) | | 0.0 (L)
| | | | | 4.5 | | 4.43 (H) | | 0.0 (L)
| | | | | 5 | | 4.86 (H) | | 0.0 (L)

Inputs | VCC | Outputs/Results
SH/LD | SER | A, B, C, D, E, F, G, H | CLK | CLK INH | | QH | QHnot
H | H | H, L, H, L, H, L, H, L | R | L | 2.5 | L | 0.0 (L) | H | 2.37 (H)
| | | | | 3.3 | | 0.0 (L) | | 3.15 (H)
| | | | | 4.0 | | 0.0 (L) | | 3.81 (H)
| | | | | 4.5 | | 0.0 (L) | | 4.43 (H)
| | | | | 5 | | 0.0 (L) | | 4.86 (H)
H | L | H, L, H, L, H, L, H, L | R | L | 2.5 | H | 2.37 (H) | L | 0.0 (L)
| | | | | 3.3 | | 3.15 (H) | | 0.0 (L)
| | | | | 4.0 | | 3.81 (H) | | 0.0 (L)
| | | | | 4.5 | | 4.43 (H) | | 0.0 (L)
| | | | | 5 | | 4.85 (H) | | 0.0 (L)
H | L | H, L, H, L, H, L, H, L | R | L | 2.5 | L | 0.0 (L) | H | 2.37 (H)
| | | | | 3.3 | | 0.0 (L) | | 3.15 (H)
| | | | | 4.0 | | 0.0 (L) | | 3.81 (H)
| | | | | 4.5 | | 0.0 (L) | | 4.43 (H)
| | | | | 5 | | 0.0 (L) | | 4.85 (H)
H | H | H, L, H, L, H, L, H, L | R | L | 2.5 | H | 2.37 (H) | L | 0.0 (L)
| | | | | 3.3 | | 3.15 (H) | | 0.0 (L)
| | | | | 4.0 | | 3.81 (H) | | 0.0 (L)
| | | | | 4.5 | | 4.43 (H) | | 0.0 (L)
| | | | | 5 | | 4.85 (H) | | 0.0 (L)

Inputs | VCC | Outputs/Results
SH/LD | SER | A, B, C, D, E, F, G, H | CLK | CLK INH | | QH | QHnot
H | H | H, L, H, L, H, L, H, L | R | L | 2.5 | L | 0.0 (L) | H | 2.37 (H)
| | | | | 3.3 | | 0.0 (L) | | 3.15 (H)
| | | | | 4.0 | | 0.0 (L) | | 3.81 (H)
| | | | | 4.5 | | 0.0 (L) | | 4.43 (H)
| | | | | 5 | | 0.0 (L) | | 4.85 (H)
H | H | H, L, H, L, H, L, H, L | R | L | 2.5 | L | 0.0 (L) | H | 2.37 (H)
| | | | | 3.3 | | 0.0 (L) | | 3.15 (H)
| | | | | 4.0 | | 0.0 (L) | | 3.81 (H)
| | | | | 4.5 | | 0.0 (L) | | 4.43 (H)
| | | | | 5 | | 0.0 (L) | | 4.86 (H)
H | H | H, L, H, L, H, L, H, L | R | L | 2.5 | H | 2.37 (H) | L | 0.0 (L)
| | | | | 3.3 | | 3.15 (H) | | 0.0 (L)
| | | | | 4.0 | | 3.81 (H) | | 0.0 (L)
| | | | | 4.5 | | 4.43 (H) | | 0.0 (L)
| | | | | 5 | | 4.85 (H) | | 0.0 (L)
H | H | H, L, H, L, H, L, H, L | R | L | 2.5 | H | 2.37 (H) | L | 0.0 (L)
| | | | | 3.3 | | 3.15 (H) | | 0.0 (L)
| | | | | 4.0 | | 3.81 (H) | | 0.0 (L)
| | | | | 4.5 | | 4.43 (H) | | 0.0 (L)
| | | | | 5 | | 4.85 (H) | | 0.0 (L)

Inputs | VCC | Outputs/Results
SH/LD | SER | A, B, C, D, E, F, G, H | CLK | CLK INH | | QH | QHnot
H | H | H, L, H, L, H, L, H, L | R | L | 2.5 | L | 0.0 (L) | H | 2.37 (H)
| | | | | 3.3 | | 0.0 (L) | | 3.15 (H)
| | | | | 4.0 | | 0.0 (L) | | 3.81 (H)
| | | | | 4.5 | | 0.0 (L) | | 4.43 (H)
| | | | | 5 | | 0.0 (L) | | 4.86 (H)
H | H | H, L, H, L, H, L, H, L | R | L | 2.5 | L | 0.0 (L) | H | 2.37 (H)
| | | | | 3.3 | | 0.0 (L) | | 3.15 (H)
| | | | | 4.0 | | 0.0 (L) | | 3.81 (H)
| | | | | 4.5 | | 0.0 (L) | | 4.43 (H)
| | | | | 5 | | 0.0 (L) | | 4.85 (H)
H | H | H, L, H, L, H, L, H, L | R | L | 2.5 | H | 2.37 (H) | L | 0.0 (L)
| | | | | 3.3 | | 3.15 (H) | | 0.0 (L)
| | | | | 4.0 | | 3.81 (H) | | 0.0 (L)
| | | | | 4.5 | | 4.43 (H) | | 0.0 (L)
| | | | | 5 | | 4.85 (H) | | 0.0 (L)
H | H | H, L, H, L, H, L, H, L | R | L | 2.5 | H | 2.37 (H) | L | 0.0 (L)
| | | | | 3.3 | | 3.15 (H) | | 0.0 (L)
| | | | | 4.0 | | 3.81 (H) | | 0.0 (L)
| | | | | 4.5 | | 4.43 (H) | | 0.0 (L)
| | | | | 5 | | 4.86 (H) | | 0.0 (L)

### No Change 1: PASS

Inputs | VCC | Outputs/Results
SH/LD | SER | A, B, C, D, E, F, G, H | CLK | CLK INH | | QH | QHnot
L | X | H, L, H, L, H, L, H, L | X | X | 2.5 | L | 0.0 (L) | H | 2.37 (H)
| | | | | 3.3 | | 0.0 (L) | | 3.15 (H)
| | | | | 4.0 | | 0.0 (L) | | 3.81 (H)
| | | | | 4.5 | | 0.0 (L) | | 4.43 (H)
| | | | | 5 | | 0.0 (L) | | 4.86 (H)
H | L | H, L, H, L, H, L, H, L | L | R | 2.5 | H | 2.37 (H) | L | 0.0 (L)
| | | | | 3.3 | | 3.15 (H) | | 0.0 (L)
| | | | | 4.0 | | 3.81 (H) | | 0.0 (L)
| | | | | 4.5 | | 4.43 (H) | | 0.0 (L)
| | | | | 5 | | 4.86 (H) | | 0.0 (L)
H | H | H, L, H, L, H, L, H, L | L | R | 2.5 | L | 0.0 (L) | H | 2.37 (H)
| | | | | 3.3 | | 0.0 (L) | | 3.15 (H)
| | | | | 4.0 | | 0.0 (L) | | 3.81 (H)
| | | | | 4.5 | | 0.0 (L) | | 4.43 (H)
| | | | | 5 | | 0.0 (L) | | 4.86 (H)
H | H | H, L, H, L, H, L, H, L | L | R | 2.5 | H | 2.37 (H) | L | 0.0 (L)
| | | | | 3.3 | | 3.15 (H) | | 0.0 (L)
| | | | | 4.0 | | 3.81 (H) | | 0.0 (L)
| | | | | 4.5 | | 4.44 (H) | | 0.0 (L)
| | | | | 5 | | 4.86 (H) | | 0.0 (L)

Inputs | VCC | Outputs/Results
SH/LD | SER | A, B, C, D, E, F, G, H | CLK | CLK INH | | QH | QHnot
H | H | H, L, H, L, H, L, H, L | L | R | 2.5 | L | 0.0 (L) | H | 2.37 (H)
| | | | | 3.3 | | 0.0 (L) | | 3.15 (H)
| | | | | 4.0 | | 0.0 (L) | | 3.81 (H)
| | | | | 4.5 | | 0.0 (L) | | 4.43 (H)
| | | | | 5 | | 0.0 (L) | | 4.85 (H)
H | H | H, L, H, L, H, L, H, L | L | R | 2.5 | H | 2.37 (H) | L | 0.0 (L)
| | | | | 3.3 | | 3.15 (H) | | 0.0 (L)
| | | | | 4.0 | | 3.81 (H) | | 0.0 (L)
| | | | | 4.5 | | 4.43 (H) | | 0.0 (L)
| | | | | 5 | | 4.86 (H) | | 0.0 (L)
H | H | H, L, H, L, H, L, H, L | L | R | 2.5 | L | 0.0 (L) | H | 2.37 (H)
| | | | | 3.3 | | 0.0 (L) | | 3.15 (H)
| | | | | 4.0 | | 0.0 (L) | | 3.81 (H)
| | | | | 4.5 | | 0.0 (L) | | 4.43 (H)
| | | | | 5 | | 0.0 (L) | | 4.85 (H)
H | H | H, L, H, L, H, L, H, L | L | R | 2.5 | H | 2.37 (H) | L | 0.0 (L)
| | | | | 3.3 | | 3.15 (H) | | 0.0 (L)
| | | | | 4.0 | | 3.81 (H) | | 0.0 (L)
| | | | | 4.5 | | 4.44 (H) | | 0.0 (L)
| | | | | 5 | | 4.85 (H) | | 0.0 (L)

Inputs | VCC | Outputs/Results
SH/LD | SER | A, B, C, D, E, F, G, H | CLK | CLK INH | | QH | QHnot
H | H | H, L, H, L, H, L, H, L | L | R | 2.5 | L | 0.0 (L) | H | 2.37 (H)
| | | | | 3.3 | | 0.0 (L) | | 3.15 (H)
| | | | | 4.0 | | 0.0 (L) | | 3.81 (H)
| | | | | 4.5 | | 0.0 (L) | | 4.43 (H)
| | | | | 5 | | 0.0 (L) | | 4.86 (H)
H | H | H, L, H, L, H, L, H, L | H | X | 2.5 | L | 0.0 (L) | H | 2.37 (H)
| | | | | 3.3 | | 0.0 (L) | | 3.15 (H)
| | | | | 4.0 | | 0.0 (L) | | 3.81 (H)
| | | | | 4.5 | | 0.0 (L) | | 4.43 (H)
| | | | | 5 | | 0.0 (L) | | 4.86 (H)
H | H | H, L, H, L, H, L, H, L | H | X | 2.5 | L | 0.0 (L) | H | 2.37 (H)
| | | | | 3.3 | | 0.0 (L) | | 3.15 (H)
| | | | | 4.0 | | 0.0 (L) | | 3.81 (H)
| | | | | 4.5 | | 0.0 (L) | | 4.43 (H)
| | | | | 5 | | 0.0 (L) | | 4.85 (H)
H | H | H, L, H, L, H, L, H, L | H | X | 2.5 | L | 0.0 (L) | H | 2.37 (H)
| | | | | 3.3 | | 0.0 (L) | | 3.15 (H)
| | | | | 4.0 | | 0.0 (L) | | 3.81 (H)
| | | | | 4.5 | | 0.0 (L) | | 4.43 (H)
| | | | | 5 | | 0.0 (L) | | 4.85 (H)

### No Change 2: PASS

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

Inputs | VCC | Outputs/Results
SH/LD | SER | A, B, C, D, E, F, G, H | CLK | CLK INH | | QH | QHnot
H | H | H, L, H, L, H, L, H, L | L | R | 2.5 | L | 0.0 (L) | H | 2.37 (H)
| | | | | 3.3 | | 0.0 (L) | | 3.15 (H)
| | | | | 4.0 | | 0.0 (L) | | 3.81 (H)
| | | | | 4.5 | | 0.0 (L) | | 4.43 (H)
| | | | | 5 | | 0.0 (L) | | 4.86 (H)
H | H | H, L, H, L, H, L, H, L | L | R | 2.5 | H | 2.37 (H) | L | 0.0 (L)
| | | | | 3.3 | | 3.15 (H) | | 0.0 (L)
| | | | | 4.0 | | 3.81 (H) | | 0.0 (L)
| | | | | 4.5 | | 4.43 (H) | | 0.0 (L)
| | | | | 5 | | 4.85 (H) | | 0.0 (L)
H | H | H, L, H, L, H, L, H, L | L | R | 2.5 | L | 0.0 (L) | H | 2.37 (H)
| | | | | 3.3 | | 0.0 (L) | | 3.15 (H)
| | | | | 4.0 | | 0.0 (L) | | 3.81 (H)
| | | | | 4.5 | | 0.0 (L) | | 4.44 (H)
| | | | | 5 | | 0.0 (L) | | 4.86 (H)
H | H | H, L, H, L, H, L, H, L | L | R | 2.5 | H | 2.37 (H) | L | 0.0 (L)
| | | | | 3.3 | | 3.15 (H) | | 0.0 (L)
| | | | | 4.0 | | 3.81 (H) | | 0.0 (L)
| | | | | 4.5 | | 4.43 (H) | | 0.0 (L)
| | | | | 5 | | 4.86 (H) | | 0.0 (L)

Inputs | VCC | Outputs/Results
SH/LD | SER | A, B, C, D, E, F, G, H | CLK | CLK INH | | QH | QHnot
H | H | H, L, H, L, H, L, H, L | L | R | 2.5 | L | 0.0 (L) | H | 2.37 (H)
| | | | | 3.3 | | 0.0 (L) | | 3.15 (H)
| | | | | 4.0 | | 0.0 (L) | | 3.81 (H)
| | | | | 4.5 | | 0.0 (L) | | 4.43 (H)
| | | | | 5 | | 0.0 (L) | | 4.86 (H)
H | H | H, L, H, L, H, L, H, L | X | H | 2.5 | L | 0.0 (L) | H | 2.37 (H)
| | | | | 3.3 | | 0.0 (L) | | 3.15 (H)
| | | | | 4.0 | | 0.0 (L) | | 3.81 (H)
| | | | | 4.5 | | 0.0 (L) | | 4.44 (H)
| | | | | 5 | | 0.0 (L) | | 4.86 (H)
H | H | H, L, H, L, H, L, H, L | X | H | 2.5 | L | 0.0 (L) | H | 2.37 (H)
| | | | | 3.3 | | 0.0 (L) | | 3.15 (H)
| | | | | 4.0 | | 0.0 (L) | | 3.81 (H)
| | | | | 4.5 | | 0.0 (L) | | 4.44 (H)
| | | | | 5 | | 0.0 (L) | | 4.86 (H)
H | H | H, L, H, L, H, L, H, L | X | H | 2.5 | L | 0.0 (L) | H | 2.37 (H)
| | | | | 3.3 | | 0.0 (L) | | 3.15 (H)
| | | | | 4.0 | | 0.0 (L) | | 3.81 (H)
| | | | | 4.5 | | 0.0 (L) | | 4.43 (H)
| | | | | 5 | | 0.0 (L) | | 4.86 (H)

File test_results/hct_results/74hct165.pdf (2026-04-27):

## Pin Map

Pin Name | Pin | Pin Name | Pin
SH/LD | 1 | CLK | 2
E | 3 | F | 4
G | 5 | H | 6
QHnot | 7 | QH | 13
SER | 14 | A | 15
B | 16 | C | 17
D | 18 | CLK INH | 19

## Global Parameters

Parameter | Value
VCC Pin | 20
GND Pin | 8
VCC Voltage | 5
Input Low | 0.8
Input High | 2
Output Low | 0.33
Output High | 3.84

## Tests: IC PASS 5/5

### Parallel Load: PASS

Inputs | Outputs/Results
SH/LD | SER | CLK INH | A, B, C, D, E, F, G, H | CLK | QH | QHnot
L | L | X | H, L, H, L, H, L, H, H | X | H | 4.85 (H) L | 0.0 (L)
H | L | L | H, L, H, L, H, L, H, H | R | H | 4.85 (H) L | 0.0 (L)
H | L | L | H, L, H, L, H, L, H, H | R | L | 0.0 (L) H | 4.86 (H)
H | L | L | H, L, H, L, H, L, H, H | R | H | 4.85 (H) L | 0.0 (L)
H | L | L | H, L, H, L, H, L, H, H | R | L | 0.0 (L) H | 4.86 (H)
H | L | L | H, L, H, L, H, L, H, H | R | H | 4.85 (H) L | 0.0 (L)

Inputs | Outputs/Results
SH/LD | SER | CLK INH | A, B, C, D, E, F, G, H | CLK | QH | QHnot
H | L | L | H, L, H, L, H, L, H, H | R | L | 0.0 (L) H | 4.86 (H)
H | L | L | H, L, H, L, H, L, H, H | R | H | 4.86 (H) L | 0.0 (L)

### Serial In 1: PASS

Inputs | Outputs/Results
SH/LD | SER | A, B, C, D, E, F, G, H | CLK | CLK INH | QH | QHnot
L | X | H, L, H, L, H, L, H, L | X | X | L | 0.0 (L) H | 4.85 (H)
H | L | H, L, H, L, H, L, H, L | L | R | H | 4.85 (H) L | 0.0 (L)
H | L | H, L, H, L, H, L, H, L | L | R | L | 0.0 (L) H | 4.85 (H)
H | H | H, L, H, L, H, L, H, L | L | R | H | 4.85 (H) L | 0.0 (L)
H | H | H, L, H, L, H, L, H, L | L | R | L | 0.0 (L) H | 4.85 (H)
H | L | H, L, H, L, H, L, H, L | L | R | H | 4.85 (H) L | 0.0 (L)
H | L | H, L, H, L, H, L, H, L | L | R | L | 0.0 (L) H | 4.85 (H)
H | H | H, L, H, L, H, L, H, L | L | R | H | 4.85 (H) L | 0.0 (L)
H | H | H, L, H, L, H, L, H, L | L | R | L | 0.0 (L) H | 4.85 (H)
H | H | H, L, H, L, H, L, H, L | L | R | L | 0.0 (L) H | 4.85 (H)
H | H | H, L, H, L, H, L, H, L | L | R | H | 4.86 (H) L | 0.0 (L)
H | H | H, L, H, L, H, L, H, L | L | R | H | 4.85 (H) L | 0.0 (L)
H | H | H, L, H, L, H, L, H, L | L | R | L | 0.0 (L) H | 4.85 (H)
H | H | H, L, H, L, H, L, H, L | L | R | L | 0.0 (L) H | 4.85 (H)
H | H | H, L, H, L, H, L, H, L | L | R | H | 4.85 (H) L | 0.0 (L)
H | H | H, L, H, L, H, L, H, L | L | R | H | 4.85 (H) L | 0.0 (L)

### Serial In 2: PASS

Inputs | Outputs/Results
SH/LD | SER | A, B, C, D, E, F, G, H | CLK | CLK INH | QH | QHnot
L | X | H, L, H, L, H, L, H, L | X | X | L | 0.0 (L) H | 4.85 (H)
H | L | H, L, H, L, H, L, H, L | R | L | H | 4.85 (H) L | 0.0 (L)
H | L | H, L, H, L, H, L, H, L | R | L | L | 0.0 (L) H | 4.86 (H)
H | H | H, L, H, L, H, L, H, L | R | L | H | 4.86 (H) L | 0.0 (L)
H | H | H, L, H, L, H, L, H, L | R | L | L | 0.0 (L) H | 4.86 (H)
H | L | H, L, H, L, H, L, H, L | R | L | H | 4.85 (H) L | 0.0 (L)
H | L | H, L, H, L, H, L, H, L | R | L | L | 0.0 (L) H | 4.85 (H)
H | H | H, L, H, L, H, L, H, L | R | L | H | 4.85 (H) L | 0.0 (L)
H | H | H, L, H, L, H, L, H, L | R | L | L | 0.0 (L) H | 4.86 (H)
H | H | H, L, H, L, H, L, H, L | R | L | L | 0.0 (L) H | 4.86 (H)
H | H | H, L, H, L, H, L, H, L | R | L | H | 4.85 (H) L | 0.0 (L)
H | H | H, L, H, L, H, L, H, L | R | L | H | 4.86 (H) L | 0.0 (L)
H | H | H, L, H, L, H, L, H, L | R | L | L | 0.0 (L) H | 4.86 (H)
H | H | H, L, H, L, H, L, H, L | R | L | L | 0.0 (L) H | 4.85 (H)
H | H | H, L, H, L, H, L, H, L | R | L | H | 4.85 (H) L | 0.0 (L)
H | H | H, L, H, L, H, L, H, L | R | L | H | 4.86 (H) L | 0.0 (L)

### No Change 1: PASS

Inputs | Outputs/Results
SH/LD | SER | A, B, C, D, E, F, G, H | CLK | CLK INH | QH | QHnot
L | X | H, L, H, L, H, L, H, L | X | X | L | 0.0 (L) H | 4.85 (H)
H | L | H, L, H, L, H, L, H, L | L | R | H | 4.85 (H) L | 0.0 (L)
H | H | H, L, H, L, H, L, H, L | L | R | L | 0.0 (L) H | 4.85 (H)

Inputs | Outputs/Results
SH/LD | SER | A, B, C, D, E, F, G, H | CLK | CLK INH | QH | QHnot
H | H | H, L, H, L, H, L, H, L | L | R | H | 4.85 (H) L | 0.0 (L)
H | H | H, L, H, L, H, L, H, L | L | R | L | 0.0 (L) H | 4.85 (H)
H | H | H, L, H, L, H, L, H, L | L | R | H | 4.85 (H) L | 0.0 (L)
H | H | H, L, H, L, H, L, H, L | L | R | L | 0.0 (L) H | 4.85 (H)
H | H | H, L, H, L, H, L, H, L | L | R | H | 4.85 (H) L | 0.0 (L)
H | H | H, L, H, L, H, L, H, L | L | R | L | 0.0 (L) H | 4.86 (H)
H | H | H, L, H, L, H, L, H, L | H | X | L | 0.0 (L) H | 4.86 (H)
H | H | H, L, H, L, H, L, H, L | H | X | L | 0.0 (L) H | 4.86 (H)
H | H | H, L, H, L, H, L, H, L | H | X | L | 0.0 (L) H | 4.86 (H)

### No Change 2: PASS

Inputs | Outputs/Results
SH/LD | SER | A, B, C, D, E, F, G, H | CLK | CLK INH | QH | QHnot
L | X | H, L, H, L, H, L, H, L | X | X | L | 0.0 (L) H | 4.86 (H)
H | L | H, L, H, L, H, L, H, L | L | R | H | 4.86 (H) L | 0.0 (L)
H | H | H, L, H, L, H, L, H, L | L | R | L | 0.0 (L) H | 4.85 (H)
H | H | H, L, H, L, H, L, H, L | L | R | H | 4.85 (H) L | 0.0 (L)
H | H | H, L, H, L, H, L, H, L | L | R | L | 0.0 (L) H | 4.86 (H)
H | H | H, L, H, L, H, L, H, L | L | R | H | 4.85 (H) L | 0.0 (L)
H | H | H, L, H, L, H, L, H, L | L | R | L | 0.0 (L) H | 4.86 (H)
H | H | H, L, H, L, H, L, H, L | L | R | H | 4.85 (H) L | 0.0 (L)
H | H | H, L, H, L, H, L, H, L | L | R | L | 0.0 (L) H | 4.86 (H)
H | H | H, L, H, L, H, L, H, L | X | H | L | 0.0 (L) H | 4.85 (H)

Inputs | Outputs/Results
SH/LD | SER | A, B, C, D, E, F, G, H | CLK | CLK INH | QH | QHnot
H | H | H, L, H, L, H, L, H, L | X | H | L | 0.0 (L) H | 4.85 (H)
H | H | H, L, H, L, H, L, H, L | X | H | L | 0.0 (L) H | 4.86 (H)

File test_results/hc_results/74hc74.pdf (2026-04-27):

## Pin Map

Pin Name | Pin | Pin Name | Pin
1CLR | 1 | 1D | 2
1CLK | 3 | 1PRE | 4
1Q | 5 | 1Qnot | 6
2Qnot | 14 | 2Q | 15
2PRE | 16 | 2CLK | 17
2D | 18 | 2CLR | 19

## Global Parameters

Parameter | Value
VCC Pin | 20
GND Pin | 7
VCC Voltage | 2.5, 3.3, 4.0, 4.5, 5
Input Low | 0.75, 0.99, 1.2, 1.35, 1.5
Input High | 1.75, 2.31, 2.8, 3.15, 3.5
Output Low | 0.3, 0.3, 0.3, 0.3, 0.3
Output High | 2.2, 3.0, 3.6, 4.1, 4.7

## Tests: IC FAIL 1/4

### D Flip-Flop 1: PASS

Inputs | VCC | Outputs/Results
1PRE | 1CLR | 1D | 1CLK | | 1Q | 1Qnot
L | H | X | X | 2.5 | H | 2.36 (H) | L | 0.0 (L)
| | | | 3.3 | | 3.14 (H) | | 0.0 (L)
| | | | 4.0 | | 3.79 (H) | | 0.0 (L)
| | | | 4.5 | | 4.39 (H) | | 0.0 (L)
| | | | 5 | | 4.85 (H) | | 0.0 (L)

Inputs | VCC | Outputs/Results
1PRE | 1CLR | 1D | 1CLK | | 1Q | 1Qnot
H | L | X | X | 2.5 | L | 0.0 (L) | H | 2.36 (H)
| | | | 3.3 | | 0.0 (L) | | 3.14 (H)
| | | | 4.0 | | 0.0 (L) | | 3.79 (H)
| | | | 4.5 | | 0.0 (L) | | 4.39 (H)
| | | | 5 | | 0.0 (L) | | 4.85 (H)
L | L | X | X | 2.5 | H | 2.36 (H) | H | 2.36 (H)
| | | | 3.3 | | 3.14 (H) | | 3.14 (H)
| | | | 4.0 | | 3.79 (H) | | 3.79 (H)
| | | | 4.5 | | 4.39 (H) | | 4.39 (H)
| | | | 5 | | 4.85 (H) | | 4.85 (H)
H | H | H | R | 2.5 | H | 2.36 (H) | L | 0.0 (L)
| | | | 3.3 | | 3.14 (H) | | 0.0 (L)
| | | | 4.0 | | 3.79 (H) | | 0.0 (L)
| | | | 4.5 | | 4.39 (H) | | 0.0 (L)
| | | | 5 | | 4.85 (H) | | 0.0 (L)
H | H | L | R | 2.5 | L | 0.0 (L) | H | 2.36 (H)
| | | | 3.3 | | 0.0 (L) | | 3.14 (H)
| | | | 4.0 | | 0.0 (L) | | 3.79 (H)
| | | | 4.5 | | 0.0 (L) | | 4.39 (H)
| | | | 5 | | 0.0 (L) | | 4.85 (H)

### D Flip-Flop 2: FAIL

Inputs | VCC | Outputs/Results
2PRE | 2CLR | 2D | 2CLK | | 2Q | 2Qnot
L | H | X | X | 2.5 | H | 2.36 (H) | L | 0.0 (L)
| | | | 3.3 | | 3.15 (H) | | 0.0 (L)
| | | | 4.0 | | 3.81 (H) | | 0.0 (L)
| | | | 4.5 | | 4.43 (H) | | 0.0 (L)
| | | | 5 | | 4.85 (H) | | 0.0 (L)
H | L | X | X | 2.5 | L | 0.0 (L) | H | 2.36 (H)
| | | | 3.3 | | 0.0 (L) | | 3.15 (H)
| | | | 4.0 | | 0.0 (L) | | 3.81 (H)
| | | | 4.5 | | 0.0 (L) | | 4.43 (H)
| | | | 5 | | 0.0 (L) | | 4.85 (H)
L | L | X | X | 2.5 | H | 2.37 (H) | H | 2.37 (H)
| | | | 3.3 | | 3.15 (H) | | 3.15 (H)
| | | | 4.0 | | 3.81 (H) | | 3.81 (H)
| | | | 4.5 | | 4.43 (H) | | 4.43 (H)
| | | | 5 | | 4.85 (H) | | 4.85 (H)
H | H | H | R | 2.5 | H | 2.37 (H) | L | 0.0 (L)
| | | | 3.3 | | 3.15 (H) | | 0.0 (L)
| | | | 4.0 | | 3.81 (H) | | 0.0 (L)
| | | | 4.5 | | 4.43 (H) | | 0.0 (L)
| | | | 5 | | 4.85 (H) | | 0.0 (L)

Inputs | VCC | Outputs/Results
2PRE | 2CLR | 2D | 2CLK | | 2Q | 2Qnot
H | H | L | R | 2.5 | L | 0.0 (L) | H | 0.0 (L)
| | | | 3.3 | | 0.0 (L) | | 0.0 (L)
| | | | 4.0 | | 0.0 (L) | | 0.0 (L)
| | | | 4.5 | | 0.0 (L) | | 0.0 (L)
| | | | 5 | | 0.0 (L) | | 0.0 (L)

### No Change -> H: FAIL

Inputs | VCC | Outputs/Results
1PRE, 2PRE | 1CLR, 2CLR | 1D, 2D | 1CLK, 2CLK | | 1Q | 2Q | 1Qnot | 2Qnot
H | H | H | R | 2.5 | H | 2.37 (H) | H | 2.37 (H) | L | 0.0 (L) | L | 0.0 (L)
| | | | 3.3 | | 3.15 (H) | | 3.15 (H) | | 0.0 (L) | | 0.0 (L)
| | | | 4.0 | | 3.81 (H) | | 3.81 (H) | | 0.0 (L) | | 0.0 (L)
| | | | 4.5 | | 4.43 (H) | | 4.43 (H) | | 0.0 (L) | | 0.0 (L)
| | | | 5 | | 4.85 (H) | | 4.85 (H) | | 0.0 (L) | | 0.0 (L)
H | H | X | L | 2.5 | H | 2.37 (H) | H | 2.37 (H) | L | 0.0 (L) | L | 0.0 (L)
| | | | 3.3 | | 3.15 (H) | | 0.0 (L) | | 0.0 (L) | | 0.0 (L)
| | | | 4.0 | | 3.81 (H) | | 0.0 (L) | | 0.0 (L) | | 0.0 (L)
| | | | 4.5 | | 4.43 (H) | | 0.0 (L) | | 0.0 (L) | | 0.0 (L)
| | | | 5 | | 4.85 (H) | | 0.0 (L) | | 0.0 (L) | | 0.0 (L)
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

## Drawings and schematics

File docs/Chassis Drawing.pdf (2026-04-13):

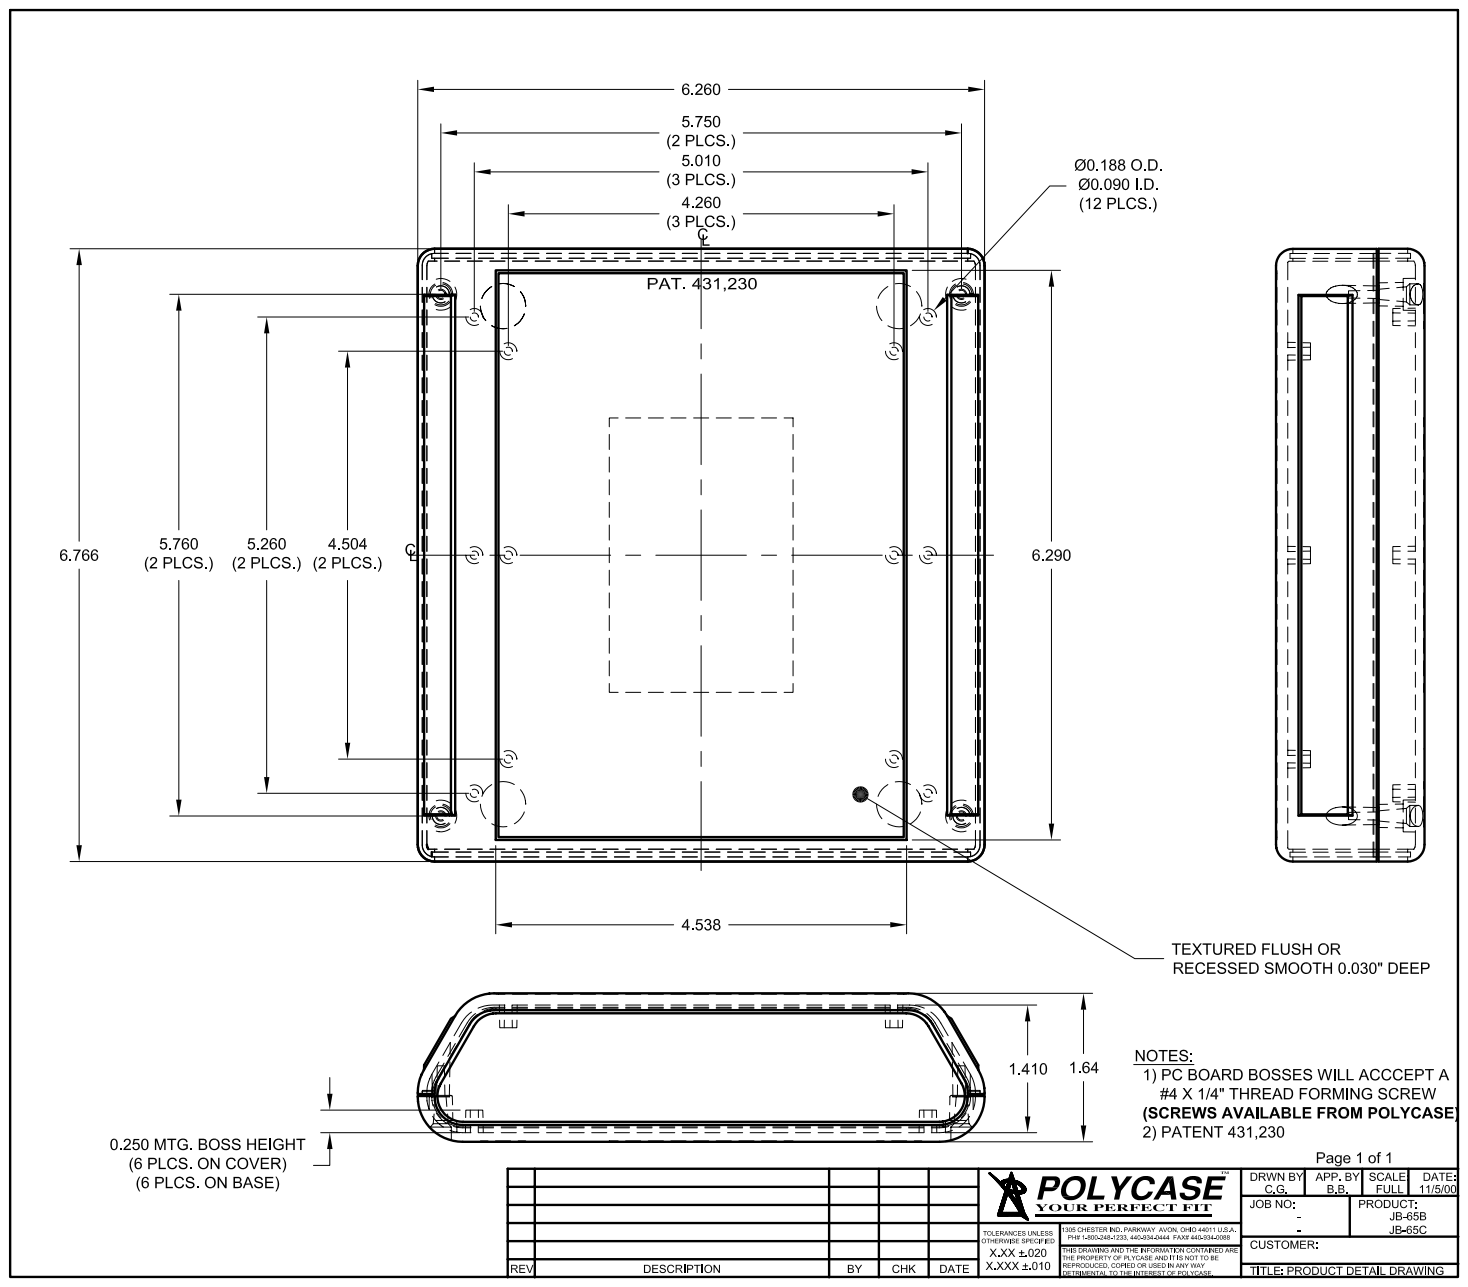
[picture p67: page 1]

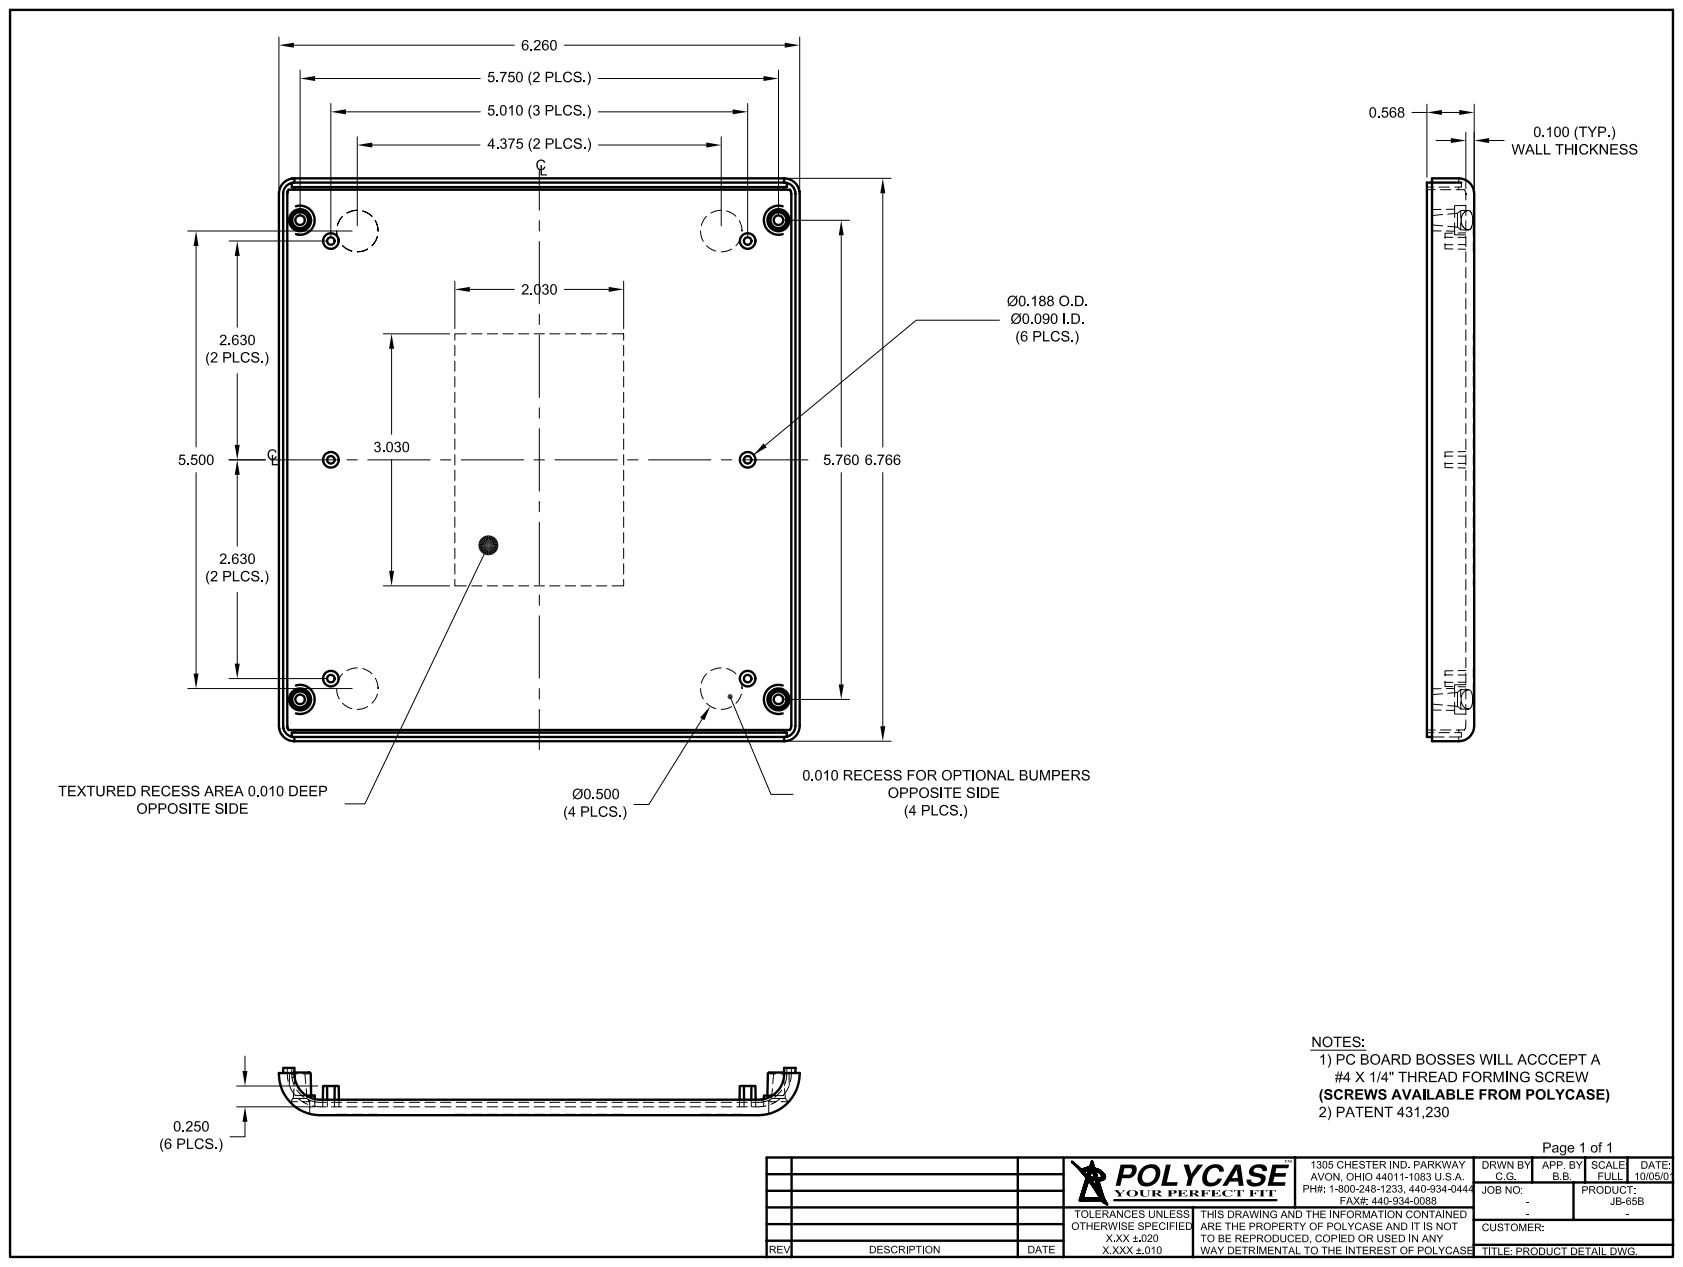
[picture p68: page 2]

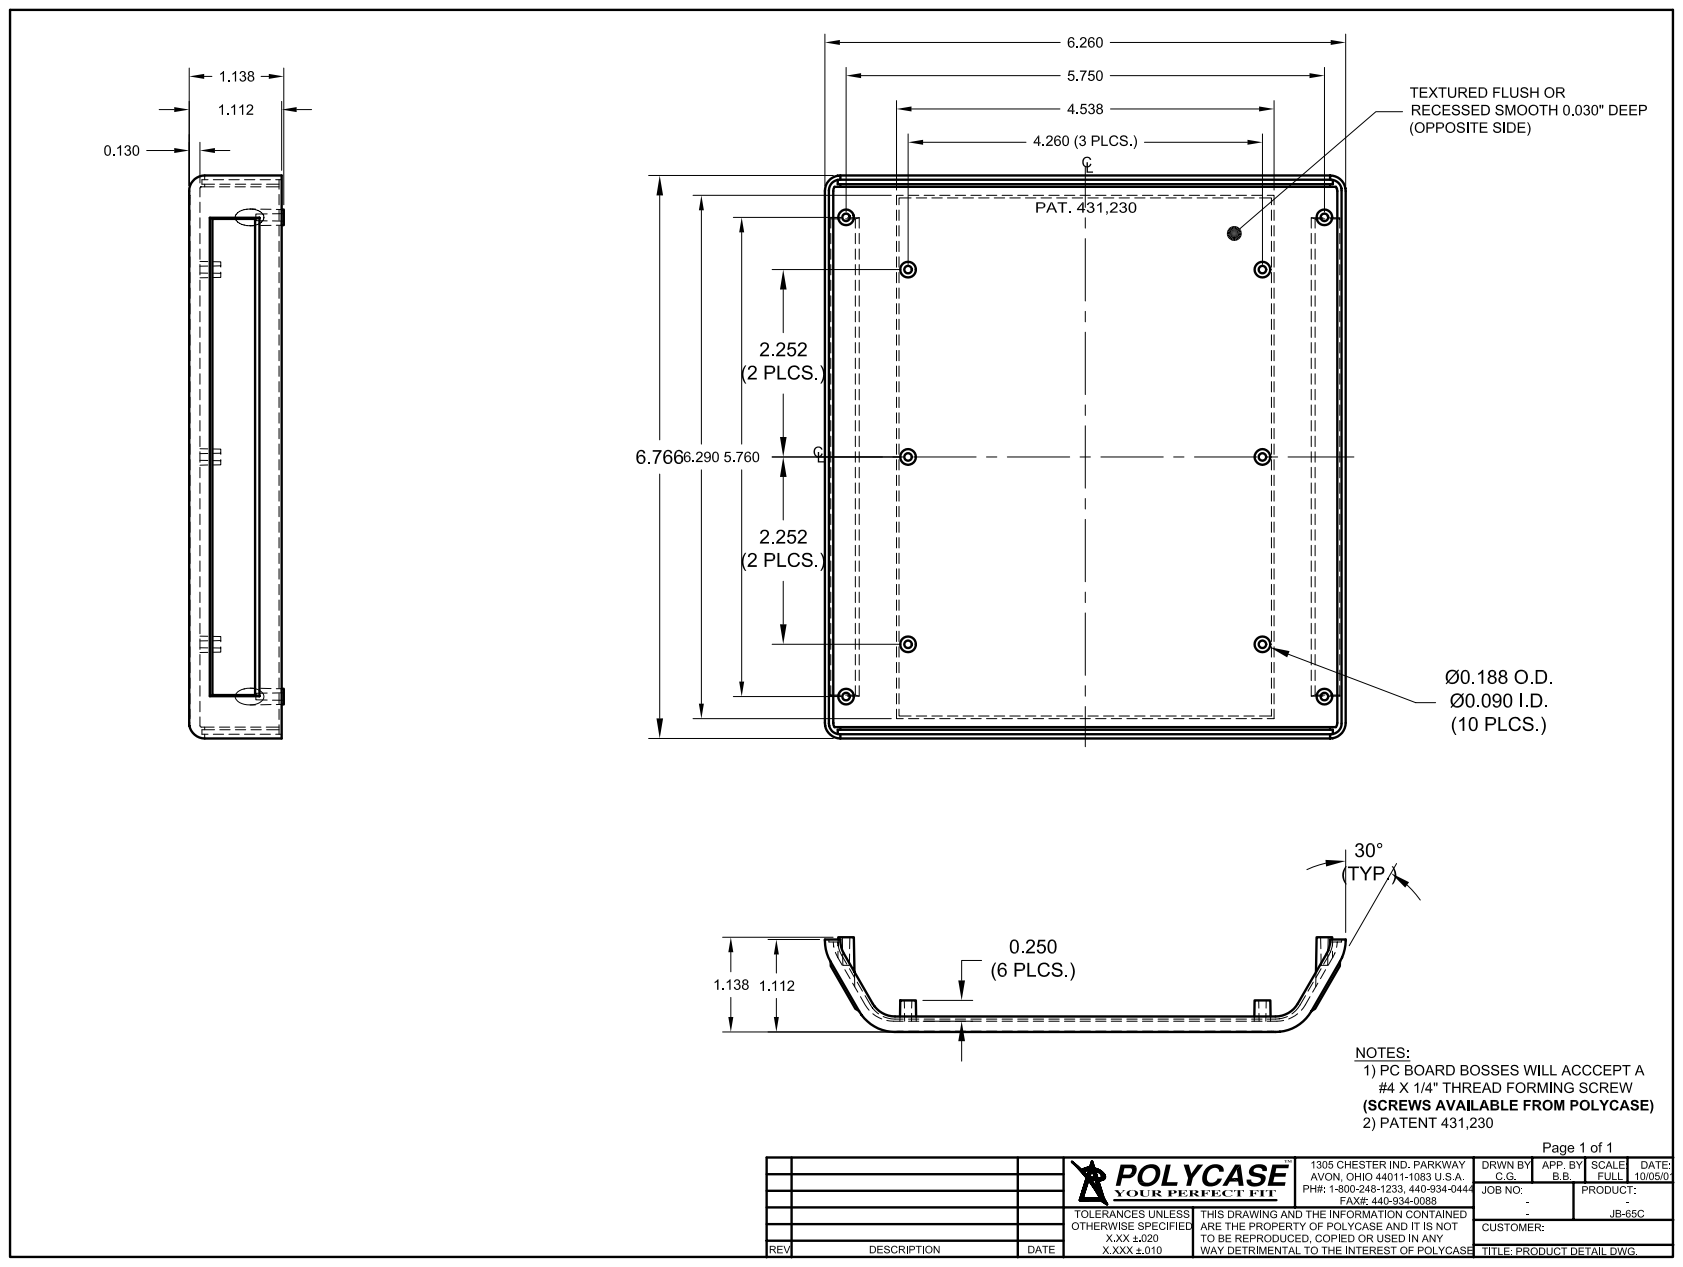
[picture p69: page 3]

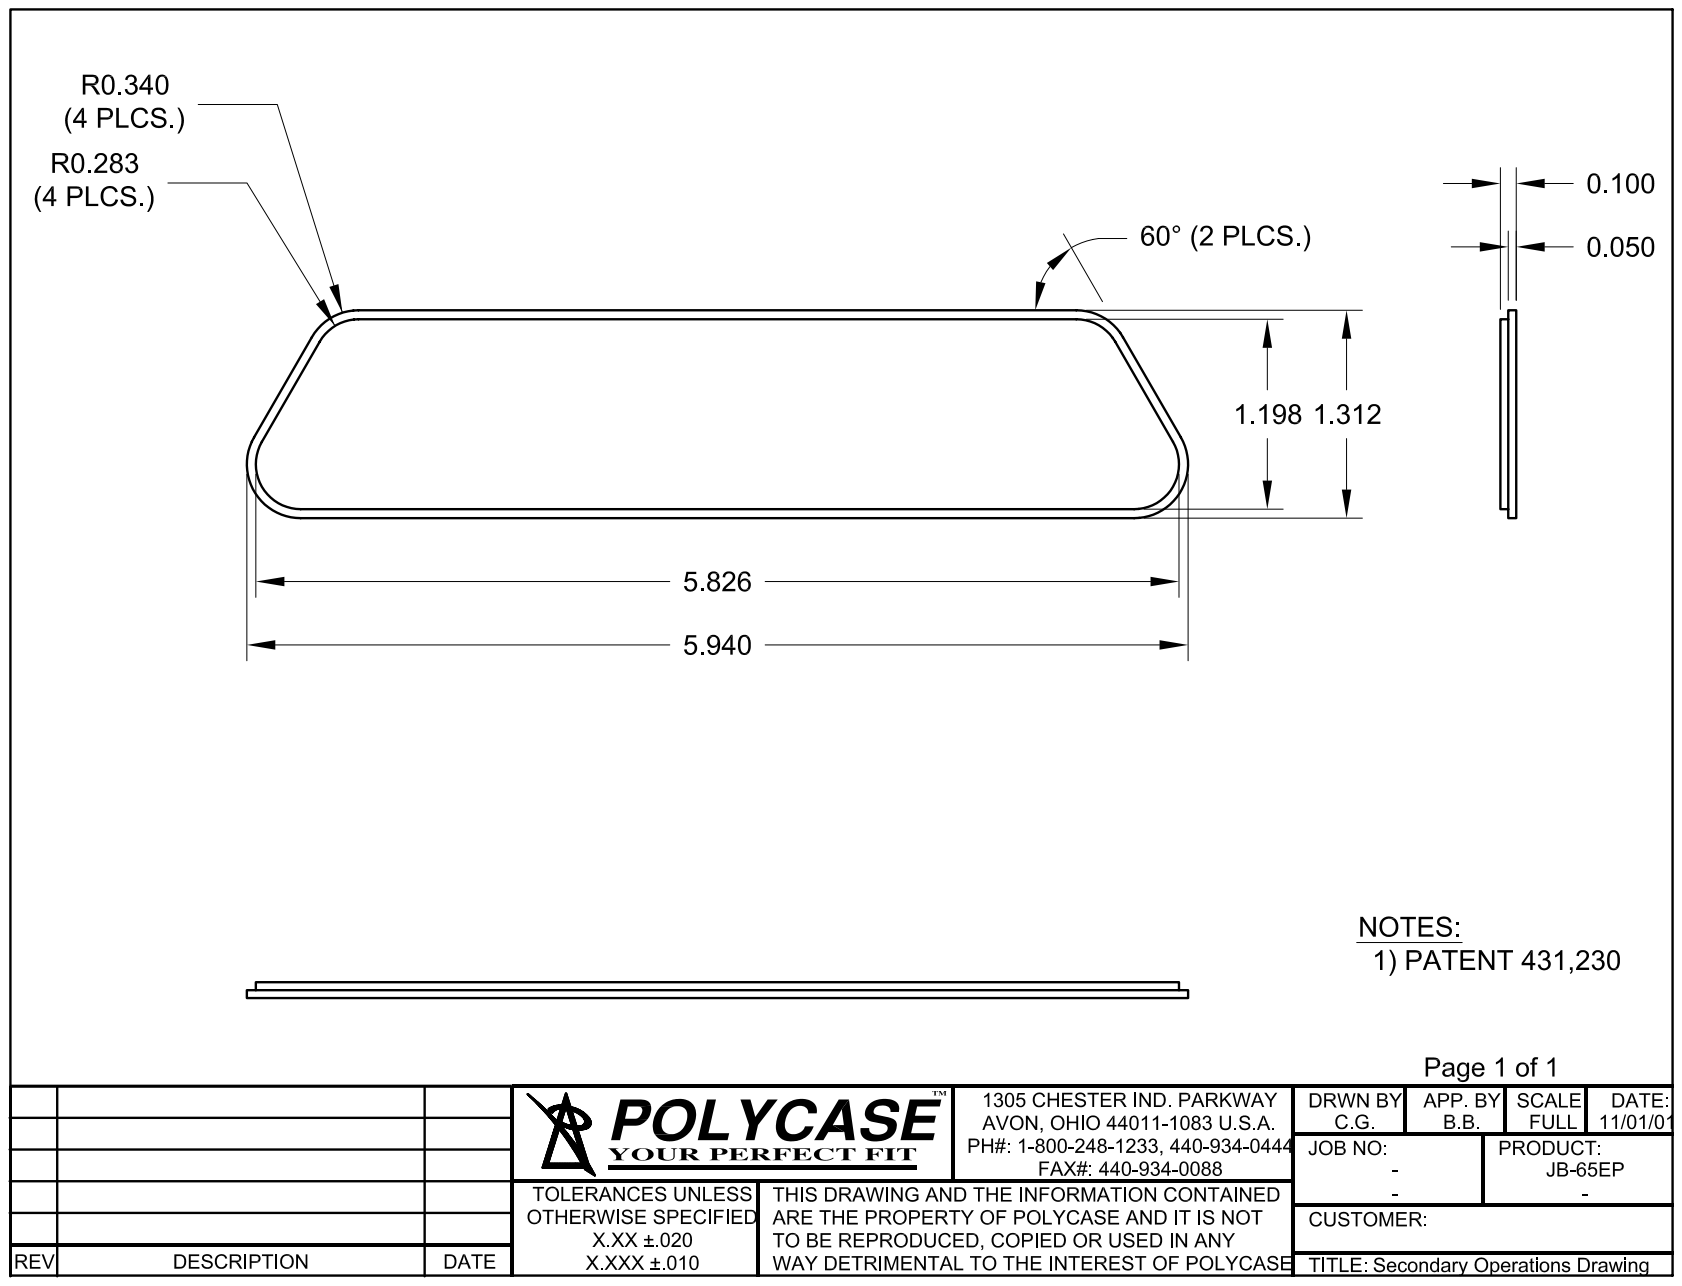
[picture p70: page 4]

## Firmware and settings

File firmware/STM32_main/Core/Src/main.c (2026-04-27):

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
/* Includes ------------------------------------------------------------------*/
#include "main.h"

/* USER CODE BEGIN Includes */
#include "test_utils.h"
#include "bist.h"
#include "firmware_crc.h"
#include <string.h>
#include <stdio.h>
#include <stdlib.h>
#include <ctype.h>
#include <stdarg.h>
/* USER CODE END Includes */


I2C_HandleTypeDef hi2c1;
I2C_HandleTypeDef hi2c2;

UART_HandleTypeDef huart1;

/* USER CODE BEGIN PV */
static uint8_t rx_ch;
static char line_buf[LINE_BUF_SIZE];
static uint32_t line_len = 0;

static ParsedState g_state;
static volatile uint8_t g_run_test = 0;
static volatile uint8_t g_run_bist = 0;
static volatile uint8_t g_start_script = 0;
static volatile uint8_t g_crc_start = 0;
static volatile uint8_t g_ping = 0;

static volatile uint8_t g_line_ready = 0;
static char cmd_buf[LINE_BUF_SIZE];

/*
 * Session caching for GUI scripts:
 * - PRM / VIN / INS / OUT changes mark session dirty
 * - VIP changes do NOT mark session dirty
 * - first TEST after dirty setup runs prepare stage
 * - later TEST calls with same structural setup skip prepare
 */
static uint8_t g_test_session_prepared = 0;
static uint8_t g_test_session_dirty = 1;
/* USER CODE END PV */

void SystemClock_Config(void);
static void MX_GPIO_Init(void);
static void MX_I2C1_Init(void);
static void MX_I2C2_Init(void);
static void MX_USART1_UART_Init(void);
/* USER CODE BEGIN 0 */
static uint8_t u8_array_equal(const uint8_t *a, const uint8_t *b, uint8_t n)
{
  for (uint8_t i = 0; i < n; i++) {
    if (a[i] != b[i]) return 0;
  }
  return 1;
}

static uint8_t ins_changed(const uint8_t *new_arr, uint8_t new_n)
{
  (void)new_arr;
  (void)new_n;
  return 0;
}

static uint8_t outs_changed(const uint8_t *new_arr, uint8_t new_n)
{
  (void)new_arr;
  (void)new_n;
  return 0;
}

static uint8_t vin_changed(int32_t low_mv, int32_t high_mv)
{
  (void)low_mv;
  (void)high_mv;

  /*
   * VIN changes do NOT invalidate the prepared session.
   * They only affect logic interpretation thresholds for this sub-test.
   */
  return 0;
}

static uint8_t prm_changed(uint8_t vcc_pin, uint8_t gnd_pin, int32_t vcc_mv)
{
  (void)vcc_mv;

  /*
   * VCC magnitude changes do NOT invalidate the prepared session.
   * Only changing which DUT pins are used for VCC/GND should force
   * a new calibration + fault-preflight session.
   */
  if (!g_state.prm_set) return 1;
  if (g_state.vcc_pin != vcc_pin) return 1;
  if (g_state.gnd_pin != gnd_pin) return 1;
  return 0;
}


static void uart_print(const char *s)
{
  HAL_UART_Transmit(&huart1, (uint8_t*)s, (uint16_t)strlen(s), HAL_MAX_DELAY);
}

static void uart_printf(const char *fmt, ...)
{
  char out[256];
  va_list args;
  va_start(args, fmt);
  vsnprintf(out, sizeof(out), fmt, args);
  va_end(args);
  uart_print(out);
}

static void invalidate_test_session(void)
{
  g_test_session_prepared = 0;
  g_test_session_dirty = 1;
}

// Trim whitespace in-place (leading + trailing)
static void trim(char *s)
{
  char *p = s;
  while (*p && isspace((unsigned char)*p)) p++;
  if (p != s) memmove(s, p, strlen(p) + 1);

  size_t n = strlen(s);
  while (n > 0 && isspace((unsigned char)s[n - 1])) {
    s[n - 1] = '\0';
    n--;
  }
}

static int parse_pin_list(const char *csv, uint8_t *arr, uint8_t *count_out)
{
  char tmp[LINE_BUF_SIZE];
  strncpy(tmp, csv, sizeof(tmp) - 1);
  tmp[sizeof(tmp) - 1] = '\0';

  uint8_t count = 0;
  char *save = NULL;
  char *tok = strtok_r(tmp, ",", &save);

  while (tok)
  {
    trim(tok);
    if (*tok == '\0') return -2;

    char *endp = NULL;
    long v = strtol(tok, &endp, 10);
    if (endp == tok) return -2;
    if (v < 1 || v > 20) return -3;
    if (count >= MAX_PINS) return -4;

    arr[count++] = (uint8_t)v;
    tok = strtok_r(NULL, ",", &save);
  }

  *count_out = count;
  return 0;
}

static int parse_vin_limits_mv(const char *csv, int32_t *low_mv, int32_t *high_mv)
{
  char tmp[LINE_BUF_SIZE];
  strncpy(tmp, csv, sizeof(tmp) - 1);
  tmp[sizeof(tmp) - 1] = '\0';

  char *save = NULL;
  char *a = strtok_r(tmp, ",", &save);
  char *b = strtok_r(NULL, ",", &save);
  if (!a || !b) return -2;

  trim(a);
  trim(b);
  if (*a == '\0' || *b == '\0') return -2;

  double lo = strtod(a, NULL);
  double hi = strtod(b, NULL);

  *low_mv  = (int32_t)(lo * 1000.0 + (lo >= 0 ? 0.5 : -0.5));
  *high_mv = (int32_t)(hi * 1000.0 + (hi >= 0 ? 0.5 : -0.5));
  return 0;
}

static int parse_prm(const char *csv,
                     uint8_t *vcc_pin_out,
                     uint8_t *gnd_pin_out,
                     int32_t *vcc_mv_out)
{
  char tmp[LINE_BUF_SIZE];
  strncpy(tmp, csv, sizeof(tmp) - 1);
  tmp[sizeof(tmp) - 1] = '\0';

  char *save = NULL;
  char *a = strtok_r(tmp, ",", &save);
  char *b = strtok_r(NULL, ",", &save);
  char *c = strtok_r(NULL, ",", &save);

  if (!a || !b || !c) return -2;

  trim(a);
  trim(b);
  trim(c);
  if (*a == '\0' || *b == '\0' || *c == '\0') return -2;

  char *endp1 = NULL;
  char *endp2 = NULL;
  long vcc = strtol(a, &endp1, 10);
  long gnd = strtol(b, &endp2, 10);
  if (endp1 == a || endp2 == b) return -2;

  if (vcc < 1 || vcc > 20) return -3;
  if (gnd < 1 || gnd > 20) return -3;

  double v = strtod(c, NULL);
  int32_t mv = (int32_t)(v * 1000.0 + (v >= 0 ? 0.5 : -0.5));

  *vcc_pin_out = (uint8_t)vcc;
  *gnd_pin_out = (uint8_t)gnd;
  *vcc_mv_out  = mv;
  return 0;
}

static void normalize_vip_bin_lengths(ParsedState *st)
{
  size_t max_len = 0;

  if (st == NULL) return;

  for (uint8_t i = 0; i < st->n_vip; i++)
  {
    if (st->vip_kind[i] == VIP_KIND_BIN)
    {
      size_t len = strlen(st->vip_bin[i]);
      if (len >= 2) {
        len -= 2;
        if (len > max_len) {
          max_len = len;
        }
      }
    }
  }

  if (max_len == 0) {
    return;
  }

  for (uint8_t i = 0; i < st->n_vip; i++)
  {
    if (st->vip_kind[i] == VIP_KIND_BIN)
    {
      char padded[VIP_BIN_MAX];
      const char *src = st->vip_bin[i] + 2;
      size_t cur_len = strlen(src);

      if (cur_len >= max_len) {
        continue;
      }

      size_t out_idx = 0;
      padded[out_idx++] = '0';
      padded[out_idx++] = 'b';

      for (size_t j = 0; j < cur_len; j++) {
        padded[out_idx++] = src[j];
      }

      while ((out_idx - 2) < max_len) {
        padded[out_idx++] = '0';
      }

      padded[out_idx] = '\0';

      strncpy(st->vip_bin[i], padded, VIP_BIN_MAX - 1);
      st->vip_bin[i][VIP_BIN_MAX - 1] = '\0';
    }
  }
}

static int parse_vip_token(const char *tok_in,
                           VipKind *kind_out,
                           int32_t *mv_out,
                           uint32_t *clk_mhz_out,
                           char bin_out[VIP_BIN_MAX])
{
  char tok[VIP_BIN_MAX];
  strncpy(tok, tok_in, sizeof(tok) - 1);
  tok[sizeof(tok) - 1] = '\0';
  trim(tok);

  if (*tok == '\0') return -2;

  if (strncmp(tok, "CLK", 3) == 0)
  {
    const char *p = tok + 3;
    if (*p == '\0') return -2;

    for (const char *q = p; *q; q++) {
      if (!isdigit((unsigned char)*q)) return -2;
    }

    long mhz = strtol(p, NULL, 10);
    if (mhz <= 0 || mhz > 1000) return -3;

    *kind_out = VIP_KIND_CLK;
    *clk_mhz_out = (uint32_t)mhz;
    return 0;
  }

  if (strncmp(tok, "0b", 2) == 0)
  {
    const char *p = tok + 2;
    if (*p == '\0') return -2;

    size_t n = strlen(p);
    if (n > 32) return -4;

    for (const char *q = p; *q; q++) {
      if (*q != '0' && *q != '1' && *q != 'R' && *q != 'F') {
        return -2;
      }
    }

    *kind_out = VIP_KIND_BIN;
    strncpy(bin_out, tok, VIP_BIN_MAX - 1);
    bin_out[VIP_BIN_MAX - 1] = '\0';
    return 0;
  }

  double v = strtod(tok, NULL);
  int32_t mv = (int32_t)(v * 1000.0 + (v >= 0 ? 0.5 : -0.5));

  *kind_out = VIP_KIND_VOLT;
  *mv_out = mv;
  return 0;
}

static int parse_vip_list(const char *csv,
                          VipKind *kinds,
                          int32_t *mv_arr,
                          uint32_t *clk_arr,
                          char bin_arr[MAX_PINS][VIP_BIN_MAX],
                          uint8_t *count_out)
{
  char tmp[LINE_BUF_SIZE];
  strncpy(tmp, csv, sizeof(tmp) - 1);
  tmp[sizeof(tmp) - 1] = '\0';

  uint8_t count = 0;
  char *save = NULL;
  char *tok = strtok_r(tmp, ",", &save);

  while (tok)
  {
    if (count >= MAX_PINS) return -4;
    trim(tok);
    if (*tok == '\0') return -2;

    kinds[count] = VIP_KIND_NONE;
    mv_arr[count] = 0;
    clk_arr[count] = 0;
    bin_arr[count][0] = '\0';

    int rc = parse_vip_token(tok,
                             &kinds[count],
                             &mv_arr[count],
                             &clk_arr[count],
                             bin_arr[count]);
    if (rc != 0) return rc;

    count++;
    tok = strtok_r(NULL, ",", &save);
  }

  *count_out = count;
  return 0;
}

static void handle_command_line(char *line)
{
  trim(line);
  if (*line == '\0') return;

  if (strcmp(line, "PING") == 0)
  {
	  uart_print("OK PING\r\n");
	  g_ping = 1;
	  return;
  }

  if (strcmp(line, "TEST") == 0)
  {
    uart_print("OK TEST\r\n");
    g_run_test = 1;
    return;
  }

  if (strcmp(line, "BIST") == 0)
  {
    uart_print("OK BIST\r\n");
    g_run_bist = 1;
    return;
  }
  if (strcmp(line, "START") == 0)
  {
	  uart_print("OK START\r\n");
	  g_start_script=1;
	  return;
    }

  if (strcmp(line, "FWCRC") == 0)
  {
	  uart_print("OK FWCRC\r\n");
	  g_crc_start=1;
	  return;
  }

  char *colon = strchr(line, ':');
  if (!colon) {
    uart_print("ERR no_colon\r\n");
    return;
  }

  *colon = '\0';
  char *cmd = line;
  char *params = colon + 1;
  trim(cmd);
  trim(params);

  if (strcmp(cmd, "INS") == 0)
  {
    uint8_t parsed_ins[MAX_PINS];
    uint8_t parsed_n = 0;

    int rc = parse_pin_list(params, parsed_ins, &parsed_n);
    if (rc == 0) {
      uint8_t changed = ins_changed(parsed_ins, parsed_n);

      memcpy(g_state.ins, parsed_ins, sizeof(parsed_ins));
      g_state.n_ins = parsed_n;

      uart_printf("OK INS n=%u\r\n", g_state.n_ins);

      if (changed) {
        invalidate_test_session();
      }
    } else {
      uart_printf("ERR INS rc=%d\r\n", rc);
    }
    return;
  }



  if (strcmp(cmd, "OUT") == 0)
  {
    uint8_t parsed_outs[MAX_PINS];
    uint8_t parsed_n = 0;

    int rc = parse_pin_list(params, parsed_outs, &parsed_n);
    if (rc == 0) {
      uint8_t changed = outs_changed(parsed_outs, parsed_n);

      memcpy(g_state.outs, parsed_outs, sizeof(parsed_outs));
      g_state.n_outs = parsed_n;

      uart_printf("OK OUT n=%u\r\n", g_state.n_outs);

      if (changed) {
        invalidate_test_session();
      }
    } else {
      uart_printf("ERR OUT rc=%d\r\n", rc);
    }
    return;
  }

  if (strcmp(cmd, "VIN") == 0)
  {
    int32_t lo_mv = 0, hi_mv = 0;
    int rc = parse_vin_limits_mv(params, &lo_mv, &hi_mv);
    if (rc == 0) {
      uint8_t changed = vin_changed(lo_mv, hi_mv);

      g_state.vin_low_mv  = lo_mv;
      g_state.vin_high_mv = hi_mv;
      g_state.vin_set     = 1;

      uart_print("OK VIN\r\n");

      if (changed) {
        invalidate_test_session();
      }
    } else {
      uart_printf("ERR VIN rc=%d\r\n", rc);
    }
    return;
  }

  if (strcmp(cmd, "PRM") == 0)
  {
    uint8_t vcc = 0, gnd = 0;
    int32_t vcc_mv = 0;

    int rc = parse_prm(params, &vcc, &gnd, &vcc_mv);
    if (rc == 0) {
      uint8_t changed = prm_changed(vcc, gnd, vcc_mv);

      g_state.vcc_pin = vcc;
      g_state.gnd_pin = gnd;
      g_state.vcc_mv  = vcc_mv;
      g_state.prm_set = 1;

      uart_print("OK PRM\r\n");

      if (changed) {
        invalidate_test_session();
      }
    } else {
      uart_printf("ERR PRM rc=%d\r\n", rc);
    }
    return;
  }

  if (strcmp(cmd, "VIP") == 0)
  {
    int rc = parse_vip_list(params,
                            g_state.vip_kind,
                            g_state.vip_mv,
                            g_state.vip_clk_mhz,
                            g_state.vip_bin,
                            &g_state.n_vip);
    if (rc == 0) {
      uart_printf("OK VIP n=%u\r\n", g_state.n_vip);
      normalize_vip_bin_lengths(&g_state);
      /* VIP changes do NOT invalidate test session */
    } else {
      uart_printf("ERR VIP rc=%d\r\n", rc);
    }
    return;
  }

  uart_print("ERR unknown_cmd\r\n");
}
/* USER CODE END 0 */

/**
  * @brief  The application entry point.
  * @retval int
  */
int main(void)
{
  HAL_Init();
  SystemClock_Config();

  MX_GPIO_Init();
  MX_I2C1_Init();
  MX_I2C2_Init();
  MX_USART1_UART_Init();

  /* USER CODE BEGIN 2 */
  memset(&g_state, 0, sizeof(g_state));
  uart_print("READY\r\n");
  HAL_UART_Receive_IT(&huart1, &rx_ch, 1);
  /* USER CODE END 2 */

  while (1)
  {


	  if (g_line_ready)
	  {
		g_line_ready = 0;
		handle_command_line(cmd_buf);
	  }

	  if (g_ping)
	  {
		  g_ping = 0;
		  uart_printf("Device is ready\r\n");
	  }

	  if (g_crc_start){
		  g_crc_start=0;
		  //run the checksum
		  uint32_t crc = firmware_crc32();
		  uart_printf("FW CRC32=0x%08lX\r\n", crc);

	  }

    if (g_run_test)
    {
      g_run_test = 0;

      //if its the start of a script (START is passed),
      //then run adc cal and fault check
      if (g_start_script==1)
      {
        if (Test_PrepareIfNeeded(&g_state) == HAL_OK)
        {
        	g_start_script=0;
        	Test(&g_state);
        }
      }
      else{
    	  //run test
    	  Test(&g_state);

      }


    }

    if (g_run_bist)
    {
      g_run_bist = 0;
      Run_BIST();

      /* BIST changes hardware state; force next TEST to prepare again */
      invalidate_test_session();
    }
  }
}

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
/* USER CODE BEGIN 4 */
void HAL_UART_RxCpltCallback(UART_HandleTypeDef *huart)
{
  if (huart->Instance == USART1)
  {
    char c = (char)rx_ch;

    if (c == '\r') {
      /* ignore CR */
    }
    else if (c == '\n')
    {
      line_buf[line_len] = '\0';

      strncpy(cmd_buf, line_buf, sizeof(cmd_buf) - 1);
      cmd_buf[sizeof(cmd_buf) - 1] = '\0';

      line_len = 0;
      g_line_ready = 1;
    }
    else
    {
      if (line_len < (LINE_BUF_SIZE - 1)) {
        line_buf[line_len++] = c;
      } else {
        line_len = 0;
        uart_print("ERR line_overflow\r\n");
      }
    }

    HAL_UART_Receive_IT(&huart1, &rx_ch, 1);
  }
}
/* USER CODE END 4 */
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


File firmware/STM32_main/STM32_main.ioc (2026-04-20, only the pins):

Mcu.UserName=STM32C071RBTxN
PA1.Signal=GPIO_Output
PA10.Signal=USART1_RX
PA2.Signal=GPIO_Output
PA3.Signal=GPIO_Output
PA4.Signal=GPIO_Output
PA5.Signal=GPIO_Output
PA8.Signal=GPIO_Output
PA9.Signal=USART1_TX
PB0.Signal=GPIO_Output
PB1.Signal=GPIO_Output
PB10.Signal=I2C2_SCL
PB11.Signal=I2C2_SDA
PB2.Signal=GPIO_Output
PB6.Signal=I2C1_SCL
PB7.Signal=I2C1_SDA
PC10.Signal=GPIO_Output
PF0-OSC_IN(PF0).Signal=GPIO_Analog
PF1-OSC_OUT(PF1).Signal=GPIO_Analog

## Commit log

2025-11-25 Managed project "Reconfigurable_Test_Fixture" created from AD
    [Reconfigurable_Test_Fixture.PrjPcb]
2026-01-20 Add files via upload
    Demo to test communication through stm32 and python program through UART
2026-01-23 Added STM32_main zip file
    Beginning of stm32 code. Right now it can receive specific configuration commands from a python application and parse them, and send info back to the python app. Next step is to add functions to cont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
2026-01-25 updated parsing algorithm to handle voltage in input lines and expanded TestVector data structure
2026-01-30 fixed pin range to 1-20
2026-02-05 moved altium project and schematics into altium_files directory
    [Analog_Switch_Array_and_ZIF_ socket.SchDoc, Muxes_and_ADC.SchDoc, Reconfigurable_Test_Fixture.PrjPcb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]
2026-02-05 Restore Altium project after VCS reset
    [Analog_Switch_Array_and_ZIF_ socket.SchDoc, Muxes_and_ADC.SchDoc, Reconfigurable_Test_Fixture.PrjPcb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]
2026-02-05 Initial commit of Altium test fixture project
    [Analog_Switch_Array_and_ZIF_ socket.SchDoc, Muxes_and_ADC.SchDoc, Reconfigurable_Test_Fixture.PrjPcb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]
2026-02-05 Update STM32 schematic
    [STM32.SchDoc]
2026-02-05 removed all preview/history files, placed project and scehmatic in altium_file dir
    [Analog_Switch_Array_and_ZIF_ socket.SchDoc, Muxes_and_ADC.SchDoc, Reconfigurable_Test_Fixture.PrjPcb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]
2026-02-11 Updated schematic - analog mux + ADC corrections
    [Analog_Switch_Array_and_ZIF_ socket.SchDoc, Muxes_and_ADC.SchDoc, Reconfigurable_Test_Fixture.PrjPcb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]
2026-02-12 Updated ADC supply, mux decoupling, and USB LED implementation
    [Analog_Switch_Array_and_ZIF_ socket.SchDoc, Muxes_and_ADC.SchDoc, STM32.SchDoc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]
2026-02-12 Deleted old Altium folders and zip archives
    [Analog_Switch_Array_and_ZIF_ socket.SchDoc, Muxes_and_ADC.SchDoc, Reconfigurable_Test_Fixture.PrjPcb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]
2026-02-15 Updated schematics
    [Analog_Switch_Array_and_ZIF_ socket.SchDoc, Muxes_and_ADC.SchDoc, STM32.SchDoc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]
2026-02-24 Created a new PCB file and added traces to components
    [PCB2.PcbDoc]
2026-02-26 refactor + fixed to work with integer inputs
    [testvector.py]
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2026-03-19 fixed gui bugs + refactors
    [testvector.py]
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2026-03-23 Updates made to schematics
    [Analog_Switch_Array_and_ZIF_ socket.SchDoc, PCB2.PcbDoc, STM32.SchDoc]
2026-03-24 Updates made to the PCB, only DRC left to complete the PCB
    [Analog_Switch_Array_and_ZIF_ socket.SchDoc, PCB2.PcbDoc, Reconfigurable_Test_Fixture.PrjPcb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]
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2026-03-25 Updates made to the PCB, Board is 98% done
    [PCB2.PcbDoc, USB_to_UART.SchDoc]
2026-03-25 Checklist changes have been applied
    [Muxes_and_ADC.SchDoc, PCB2.PcbDoc]
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2026-03-25 Board is complete pending changes
    [PCB2.PcbDoc]
2026-03-26 Updates added to PCB
    [PCB2.PcbDoc]
2026-03-29 Updates added to the Schematics & PCB
    [Analog_Switch_Array_and_ZIF_ socket.SchDoc, Muxes_and_ADC.SchDoc, PCB2.PcbDoc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]
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2026-03-30 updated stm32 ADC calcs based on circuit, stm32_src restructure, uploaded PDF results of chips tested.
2026-03-31 Final changes have been made to the PCB
    [Muxes_and_ADC.SchDoc, PCB2.PcbDoc, STM32.SchDoc]
2026-04-01 Changes made to the PCB
    [PCB2.PcbDoc, Reconfigurable_Test_Fixture.PrjPcb]
2026-04-01 PCB changes updated
    [PCB2.PcbDoc, USB_to_UART.SchDoc]
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2026-04-03 Updates made to the PCB
    [Muxes_and_ADC.SchDoc, PCB2.PcbDoc, USB_to_UART.SchDoc]
2026-04-03 Final Updates pushed
    [Muxes_and_ADC.SchDoc, PCB2.PcbDoc]
2026-04-05 Relief connect applied to through hole components
    [PCB2.PcbDoc]
2026-04-05 Changes drom checklist have been applied
    [Muxes_and_ADC.SchDoc, PCB2.PcbDoc, STM32.SchDoc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]
2026-04-05 Op-amp connection have been corrected
    [Muxes_and_ADC.SchDoc, PCB2.PcbDoc]
2026-04-06 PCB checklist updated
    [Muxes_and_ADC.SchDoc, PCB2.PcbDoc, STM32.SchDoc]
2026-04-07 Final changes have been applied
    [PCB2.PcbDoc]
2026-04-07 Final Final Changes Applied
    [Muxes_and_ADC.SchDoc, PCB2.PcbDoc]
2026-04-07 Gerber files have been added to the repo
    [PCB2.PcbDoc, Reconfigurable_Test_Fixture.PrjPcb]
2026-04-07 Final changes and updated gerber have been added to the repo
    [Analog_Switch_Array_and_ZIF_ socket.SchDoc, Muxes_and_ADC.SchDoc, PCB2.PcbDoc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]
2026-04-07 Final Gerber Files uploaded
    [PCB2.PcbDoc, Reconfigurable_Test_Fixture.PrjPcb]
2026-04-11 Schematics have been cleaned up
    [Analog_Switch_Array_and_ZIF_ socket.SchDoc, Analog_Switch_Arrays.SchDoc, Muxes_and_ADC.SchDoc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]
2026-04-13 restructured repo to be closer to final deliverable, TODO: installation, usage and licensing
    [Abstandzbolzen Stahl verzinkt I-I M4_-_Ettinger - 5.04.251 (M4x25).stp, JB-65B_JB-65B_00.SLDPRT, JB-65C_JB-65TC_00.SLDPRT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]
2026-04-13 Altium Files have been moved into hardware folder
    [Analog_Switch_Arrays.SchDoc, Muxes_and_ADC.SchDoc, PCB1.PcbDoc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]
2026-04-13 Folder clean up
    [Analog_Switch_Arrays.SchDoc, Muxes_and_ADC.SchDoc, PCB1.PcbDoc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]
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2026-04-13 Altium folder Cleanup
    [PCB1.PcbDoc, PCB_1.PcbDoc, Reconfigurable_Test_Fixture.PrjPcb]
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2026-04-20 Add files via upload
    Initial test results with "fixed" PCB (4/20/26) - ZF
2026-04-20 Firmware changes to reflect correct new mux pinout
    [STM32_main.ioc, main.c, mux_utils.c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]
2026-04-23 Added BIST, adc cal, fault handling, bug fixes
    Added BIST, adc cal, fault handling, and fixed a bug causing the first pin read to be off
2026-04-23 Added BIST, fault handling, adc cal, and fix 1st read
    [adg2128_router.c, bist.c, fault_handling.c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]
2026-04-23 Fixed error message for test aborted
    [test_utils.c]
2026-04-24 Added START command, startup tweaks
    Added START command functionality which sets a flag to run fault handling and adc calibration on the next TEST execution. Also added 100mv range for high-z, from 20mv range
2026-04-24 Added START command, high-z range fix
    100mv range for high Z, added START command which runs adc cal and fault handling on the next TEST command sent
    [main.c, test_utils.c]
2026-04-24 Minor communication bug fixes
    [main.c, test_utils.c]
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2026-04-26 Updates made to the hardware
    [Analog_Switch_Arrays.SchDoc, Muxes_and_ADC.SchDoc, PCB_1.PcbDoc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]
2026-04-28 Add README for VREF circuits documentation
    Added detailed explanation of VREF circuits including components, formulas, and resistor values.
2026-04-28 Add README for IC test fixture chassis design
    Added documentation for the SolidWorks CAD files of the IC test fixture chassis design, including details on pre-fab chassis and assembly instructions.
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2026-04-29 added BOM to docs/
    [Reconfigurable Test Fixture BOM.xlsx]
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2026-04-30 Update README with hardware design documentation
    This repository contains the hardware design documentation for a reconfigurable test fixture used to evaluate 7400-series digital integrated circuits (ICs). The documentation details the system architecture, circuit design, component selection, and PCB implementation used to support flexible, multi-voltage logic testing.
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2026-04-30 cleanup repository + finishing touches
    [Analog_Switch_Arrays.SchDoc, Muxes_and_ADC.SchDoc, PCB_1.PcbDoc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]

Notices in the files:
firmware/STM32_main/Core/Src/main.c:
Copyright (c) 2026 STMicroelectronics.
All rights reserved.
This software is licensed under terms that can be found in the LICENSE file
